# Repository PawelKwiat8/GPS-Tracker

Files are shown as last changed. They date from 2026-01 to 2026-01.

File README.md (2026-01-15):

# Projekt i realizacja autonomicznego rejestratora parametrów ruchu GPS z interfejsem bezprzewodowym opartym o układ ESP32

## Wstęp

 Celem tej pracy jest zaprojektowanie i zbudowanie urządzenia typu “GPS Tracker". Urządzenie ma rejestrować trasę, monitorować parametry ruchu i pokazywać dane w czasie rzeczywistym.

Głównym założeniem projektu było stworzenie systemu autonomicznego, zasilanego bateryjnie, który łączy w sobie funkcjonalność klasycznego rejestratora danych (tzw. "czarnej skrzynki") z nowoczesnym interfejsem użytkownika dostępnym przez przeglądarkę internetową (Web Interface).

### Koncepcja architektury systemu telemetrycznego

Do realizacji zadania wybrano platformę **ESP32**, kierując się jej  architekturą dwurdzeniową. Pozwala ona na separację procesów krytycznych (obsługa przerwań GPS i IMU) od obsługi stosu sieciowego WiFi, co jest ważne, żeby dane były zapisywane ciągle. Dodatkowo, wysoki stopień integracji w jednym układzie pozwolił zminimalizować wymiary urządzenia oraz uprościć układ oraz obniżyć cene.

## Projekt sprzętowy

Warstwa sprzętowa urządzenia została zaprojektowana w sposób modułowy, co ułatwia diagnostykę oraz ewentualną wymianę komponentów. System składa się z następujących komponentów:

### Elementy układu

* **Mikrokontroler:** ESP32 DevKit V1 WROOM-32 – dwurdzeniowy procesor z WiFi i Bluetooth
* **Moduł GPS:** NEO-6M V2 – odbiornik satelitarny (komunikacja UART)
* **IMU (czujnik ruchu):** MPU6050 – akcelerometr i żyroskop 6-osiowy (I2C)
* **Wyświetlacz:** OLED 0.96" – monochromatyczny ekran 128x64 px (I2C)
* **Pamięć masowa:** Micro SD Card Module – czytnik kart MicroSD (SPI)
* **Zasilanie:** Ładowarka Li-Ion z wejściem USB-C i zabezpieczeniami, współpracująca z ogniwem 18650. Układ umożliwia ładowanie baterii lub zasilanie systemu bezpośrednio z portu USB.

### Konfiguracja interfejsów i połączeń

Wszystkie moduły peryferyjne zostały połączone z mikrokontrolerem zgodnie z załączonym schematem elektrycznym. Kluczowym wymogiem poprawności działania układu jest połączenie wszystkich mas (GND) w jeden wspólny potencjał.

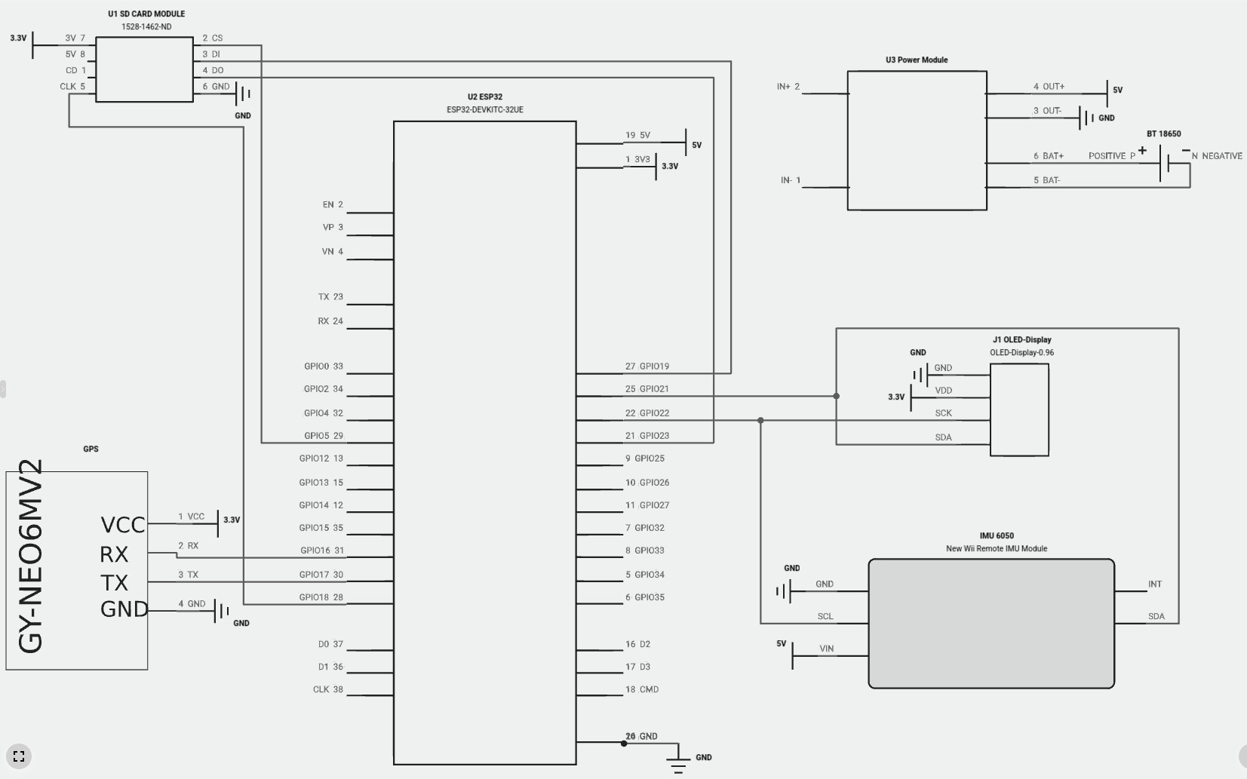
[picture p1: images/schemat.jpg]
Schemat elektryczny systemu


**Magistrala I2C (OLED + MPU6050):**
Urządzenia podłączone równolegle do wspólnych linii SDA i SCL.

| Urządzenie | Pin Modułu | Pin ESP32 | Uwagi |
| :--- | :--- | :--- | :--- |
| **OLED 0.96"** | SDA | GPIO 21 | Adres I2C: 0x3C |
| | SCL | GPIO 22 | |
| | VCC | 3.3V | Z pinu 3V3 ESP32 |
| | GND | GND | Wspólna masa |
| **MPU6050 (IMU)** | SDA | GPIO 21 | Adres I2C: 0x68 |
| | SCL | GPIO 22 | |
| | VCC | 5V | Z pinu 5V OUT power module |
| | GND | GND | Wspólna masa |

**Moduł GPS NEO-6M V2 (UART):**
Wykorzystuje sprzętowy port szeregowy UART2.

| Pin Modułu GPS | Pin ESP32 | Funkcja |
| :--- | :--- | :--- |
| TX | GPIO 16 (RX2) | Transmisja z GPS do ESP32 |
| RX | GPIO 17 (TX2) | Konfiguracja GPS (opcjonalna) |
| VCC | 3.3V | Z pinu 3V3 ESP32 |
| GND | GND | Wspólna masa |

**Micro SD Card Module (SPI):**
Wykorzystuje standardową magistralę VSPI.

| Pin Modułu SD | Pin ESP32 | Funkcja |
| :--- | :--- | :--- |
| CS | GPIO 5 | Chip Select |
| SCK | GPIO 18 | Zegar synchronizacji |
| MISO | GPIO 19 | Dane (Master In, Slave Out) |
| MOSI | GPIO 23 | Dane (Master Out, Slave In) |
| VCC | 3.3V | Z pinu 3V3 ESP32 |
| GND | GND | Wspólna masa |

### Projekt obudowy

Obudowa urządzenia przeszła ewolucję od prototypu (Wersja 1) do wersji finalnej (Wersja 2), wprowadzając istotne usprawnienia w konstrukcji i ergonomii użytkowania. Obie wersje zostały zaprojektowane w środowisku Autodesk Inventor z przeznaczeniem do druku 3D.

#### Wersja 1 (Prototyp)

Pierwsza wersja obudowy składała się z wielu elementów: podstawy z komorami na moduły i ogniwo 18650, ramki montażowej oraz pokrywy z charakterystycznym wzorem plastra miodu. Projekt zawierał dodatkową klapkę oraz otwory na kartę SD, które w praktyce okazały się zbędne lub problematyczne w druku.

Fizyczny model prototypu V1

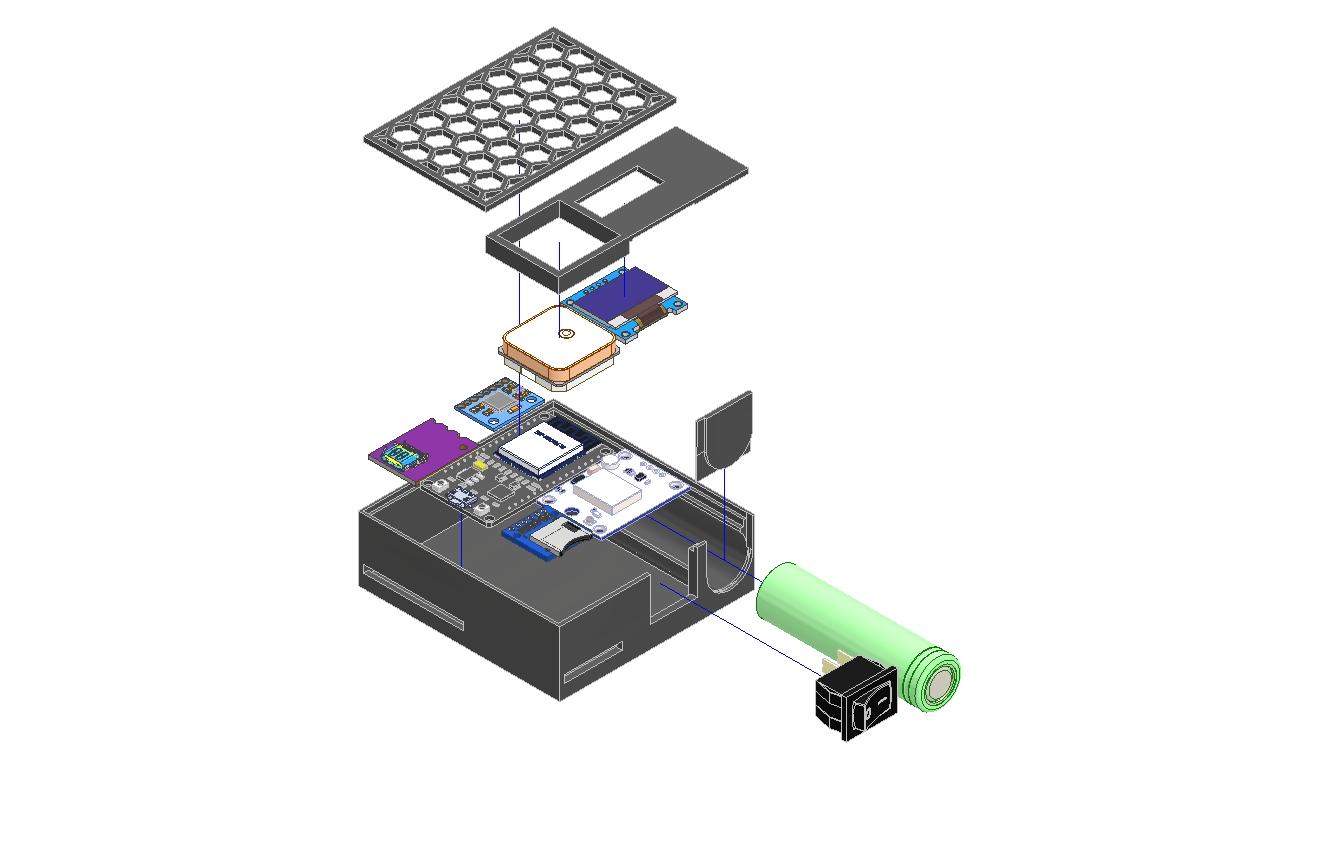
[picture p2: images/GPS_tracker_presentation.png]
Widok eksplodowany konstrukcji V1


#### Wersja 2 (Finalna)

W drugiej wersji wprowadzono szereg udoskonaleń wynikających z testów prototypu:
1.  **Uproszczona konstrukcja**: Usunięto zbędną klapkę oraz otwory na kartę SD, co zwiększyło sztywność i szczelność obudowy.
2.  **Zintegrowana pokrywa**: Dwie oddzielne górne pokrywy zostały połączone w jeden solidny element.
3.  **Wzmocnione ścianki**: Zwiększono grubość ścianek, co poprawiło wytrzymałość mechaniczną wydruku.
4.  **Lepsze dopasowanie**: Poprawiono spasowanie wszystkich elementów, eliminując luzy.
5.  **Dostęp do portów**: Zoptymalizowano otwory na porty USB (dla ładowania i programowania), ułatwiając podłączanie przewodów.

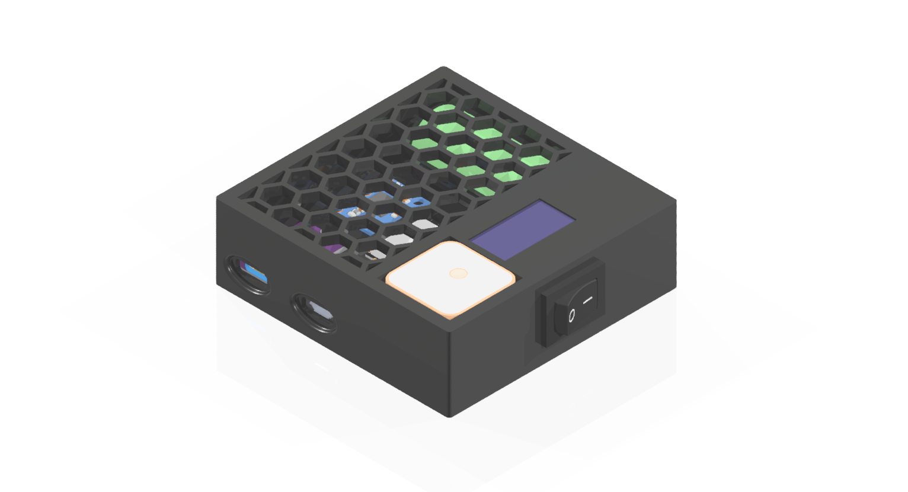
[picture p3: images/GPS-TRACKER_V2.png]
Widok złożonej obudowy V2


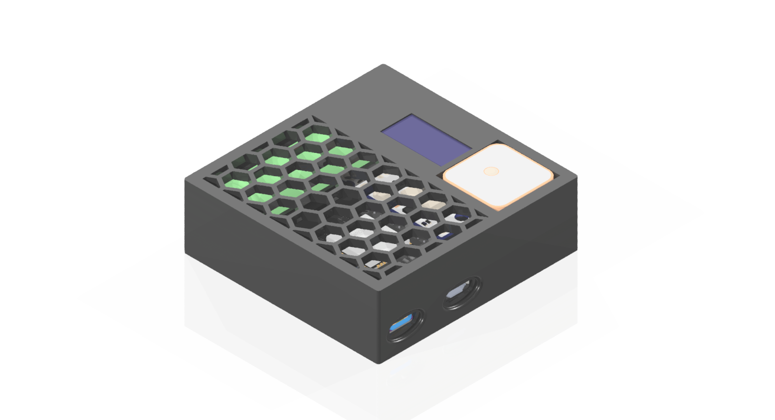
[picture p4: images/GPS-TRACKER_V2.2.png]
Widok obudowy V2 z innej perspektywy


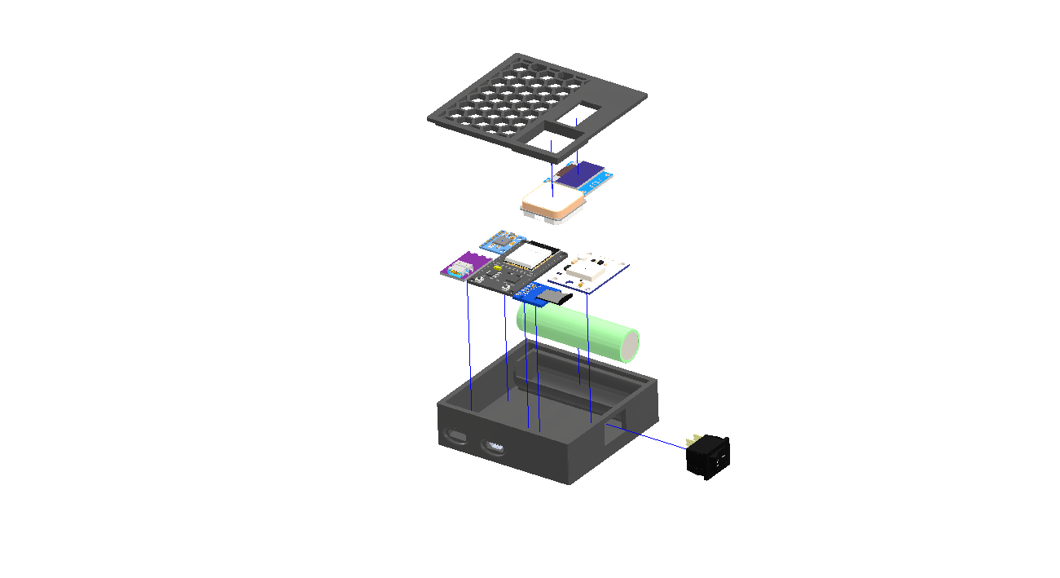
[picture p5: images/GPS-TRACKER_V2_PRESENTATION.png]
Widok eksplodowany konstrukcji V2


## Implementacja oprogramowania

### Opis funkcjonalności i obsługa aplikacji

Aplikacja webowa stanowi główne centrum sterowania urządzeniem. Poniżej przedstawiono szczegółowy opis interfejsu oraz dostępnych funkcji, które zostały zaimplementowane w celu zapewnienia intuicyjnej obsługi.

#### Ekran główny i parametry na żywo

Po nawiązaniu połączenia z siecią Wi-Fi urządzenia, w prawym górnym rogu aplikacji widoczny jest status "POŁĄCZONO". W przypadku utraty zasięgu lub zerwania połączenia, komunikat natychmiast zmienia się na "ROZŁĄCZONO", informując użytkownika o braku aktualnej synchronizacji danych.

Ekran główny został podzielony na dwie sekcje logiczne: mapę z aktualną pozycją (wykorzystującą bibliotekę Leaflet) oraz panel parametrów telemetrycznych.

Na panelu dolnym wyświetlane są kluczowe parametry odświeżane w czasie rzeczywistym:

* **Prędkość:** Aktualna prędkość przemieszczania się wyrażona w km/h.
* **Wysokość:** Wysokość nad poziomem morza w metrach.
* **Dystans:** Całkowita długość trasy przebyta w bieżącej sesji.
* **Satelity:** Liczba widocznych i używanych do nawigacji satelitów, co pozwala ocenić jakość "fixa".
* **HDOP:** Parametr precyzji geometrycznej (im niższy, tym lepiej).
* **Bateria:** Napięcie ogniwa zasilającego, pozwalające monitorować stan naładowania.

W sytuacji, gdy urządzenie nie posiada jeszcze ustalonej pozycji GPS (np. zaraz po włączeniu wewnątrz budynku), na ekranie widnieje wyraźny komunikat o szukaniu sygnału GPS.

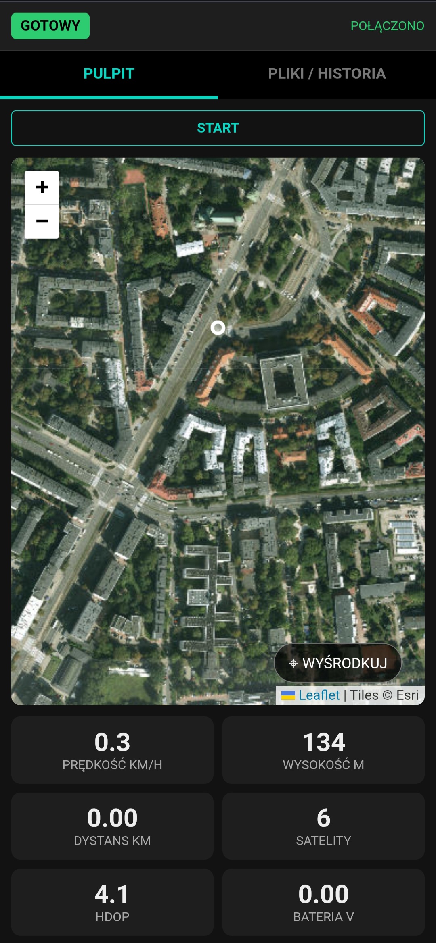
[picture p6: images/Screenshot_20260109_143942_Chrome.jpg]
Ekran startowy aplikacji - system gotowy do pracy


**Proces nagrywania trasy**

Sterowanie procesem rejestracji odbywa się za pomocą centralnego przycisku **"START"**. Rozpoczęcie nagrywania aktywuje rysowanie śladu na mapie oraz zliczanie statystyk sesji. Aplikacja udostępnia również funkcję centrowania mapy – specjalny przycisk pozwala jednym kliknięciem przywrócić widok na aktualną pozycję GPS, co jest przydatne po ręcznym przesuwaniu mapy w celu podejrzenia okolicy.

System obsługuje zaawansowane funkcje pauzowania:

* **Pauza manualna:** Użytkownik może w każdej chwili ręcznie wstrzymać zapis przyciskiem "PAUZA".
* **Auto-Pauza:** System automatycznie wykrywa brak ruchu i wstrzymuje zapis, co jest sygnalizowane pomarańczowym komunikatem "PAUZA / AUTO-PAUZA" na mapie. Zapobiega to rejestrowaniu błędnych punktów podczas postojów.

Po zakończeniu aktywności użytkownik ma do wyboru trzy opcje:

1. **WZNÓW:** Powrót do nagrywania w ramach tej samej sesji.
2. **ZAPISZ:** Trwałe zapisanie zgromadzonych danych do pliku w pamięci urządzenia.
3. **ODRZUĆ:** Anulowanie sesji i usunięcie tymczasowych danych bez zapisu.

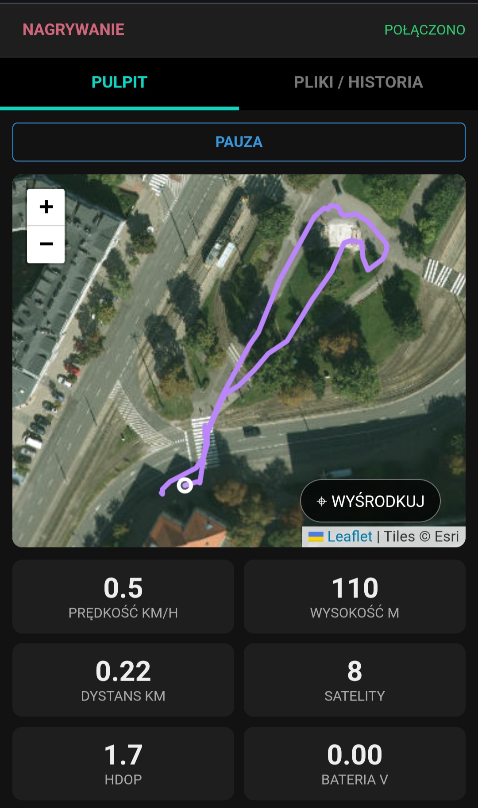
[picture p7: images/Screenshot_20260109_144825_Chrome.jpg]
Trwająca sesja z rysowaną trasą

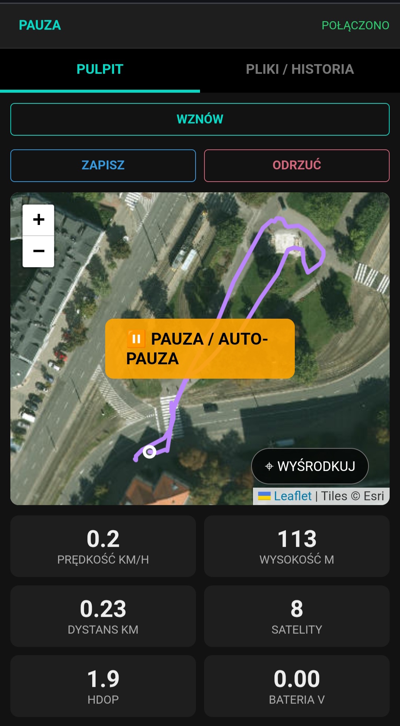
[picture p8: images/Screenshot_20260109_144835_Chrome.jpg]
Stan wstrzymania nagrywania (Pauza)


**Wykresy i analiza trendów**

Dla bardziej wnikliwej analizy aktywności, aplikacja udostępnia sekcję wykresów rysowanych na żywo. Pozwala to na bieżąco śledzić historię parametrów:

* Profil prędkości w czasie.
* Profil wysokości n.p.m.
* Wykres precyzji GPS (HDOP).
* Odczyty z akcelerometru (siły przeciążeń).

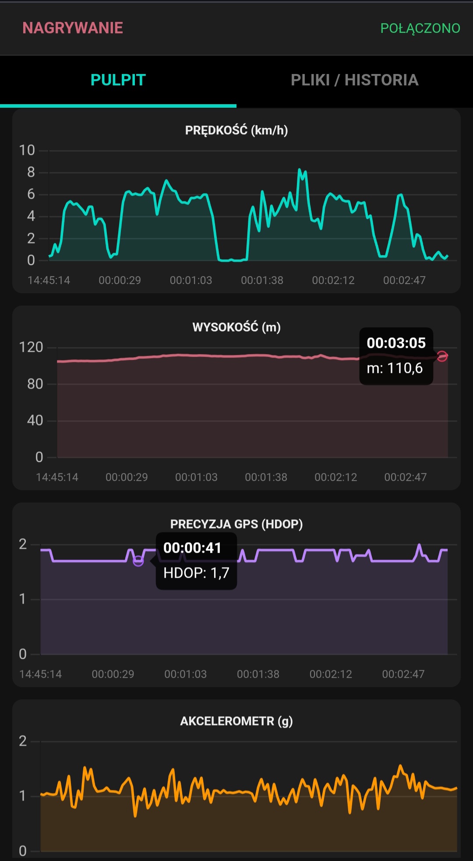
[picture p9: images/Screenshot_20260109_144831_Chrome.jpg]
Wykresy parametrów telemetrycznych


#### Zarządzanie plikami i historia tras

Druga zakładka interfejsu, "PLIKI / HISTORIA", dedykowana jest zarządzaniu danymi zgromadzonymi na karcie SD. Użytkownik otrzymuje pełną kontrolę nad archiwum tras bez konieczności wyjmowania karty z urządzenia.

Dostępne funkcjonalności obejmują:

* **Odświeżanie listy:** Pobranie aktualnego wykazu plików z karty SD.
* **Pobieranie:** Transfer wybranego pliku .csv/.txt bezpośrednio do pamięci telefonu/komputera.
* **Usuwanie:** Trwałe usunięcie niepotrzebnych plików.
* **Podgląd:** Specjalny tryb wizualizacji archiwalnej sesji.

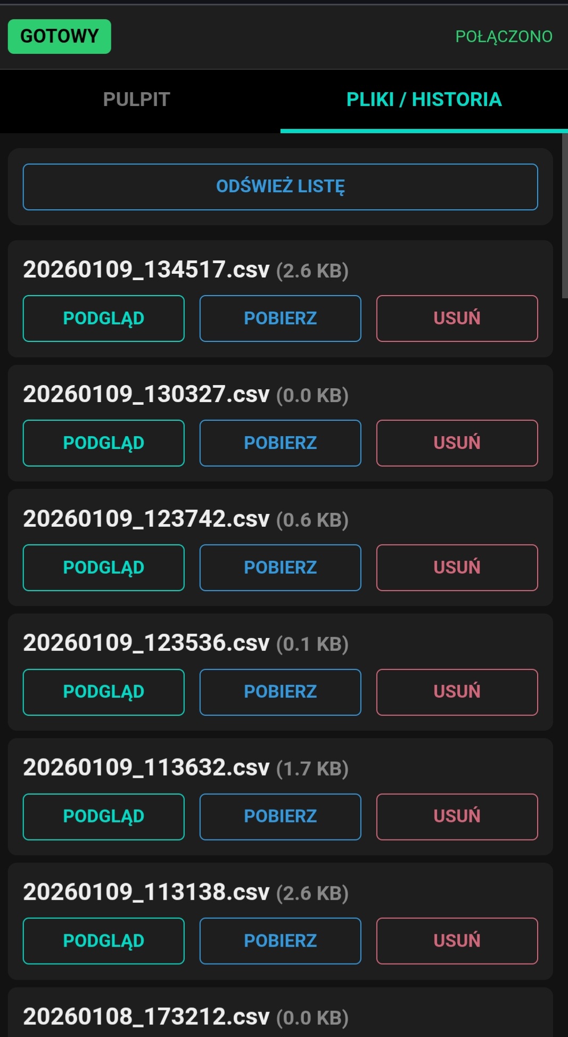
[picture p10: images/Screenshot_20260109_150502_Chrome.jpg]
Lista zapisanych plików


W trybie **podglądu pliku** interfejs prezentuje kompletny ślad trasy na mapie oraz rozszerzony zestaw statystyk, niedostępnych w trybie na żywo, takich jak:

* **Średnia prędkość:** Wartość wyliczona dla całej trasy, z uwzględnieniem postojów (auto-pauza).
* **Suma wzniosów i spadków:** Łączna różnica wysokości pokonana podczas sesji.
* **Maksymalna wysokość:** Najwyższy punkt osiagnięty na trasie (max AMSL).
* **Dystans:** Całkowita długość trasy.
* **Średnie HDOP:** Średnia wartość precyzji pomiaru z całego zapisu, pozwalająca ocenić wiarygodność danych.

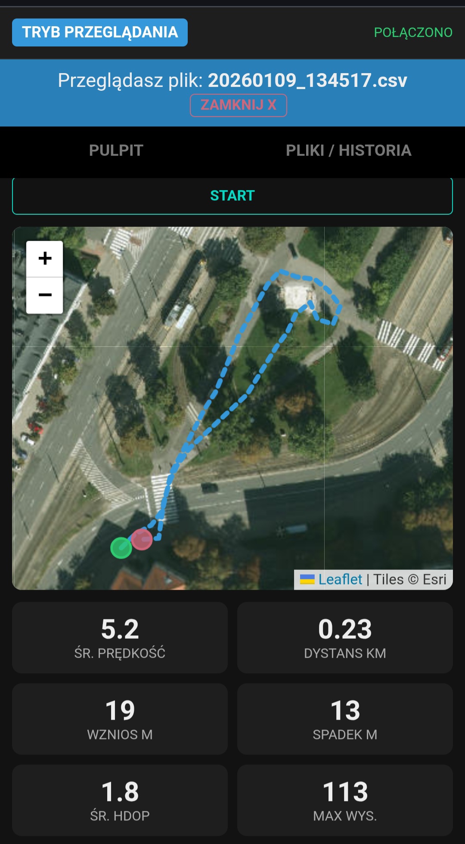
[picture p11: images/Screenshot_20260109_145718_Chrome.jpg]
Tryb podglądu historii z dodatkowymi parametrami


Dodatkowo, w trybie podglądu użytkownik ma dostęp do szczegółowych wykresów analizujących przebieg całej trasy. Są to te same wykresy co w trybie na żywo (prędkość, wysokość, HDOP), ale przedstawiające kompletne dane z całego nagrania, co pozwala na łatwą identyfikację kluczowych momentów wycieczki.

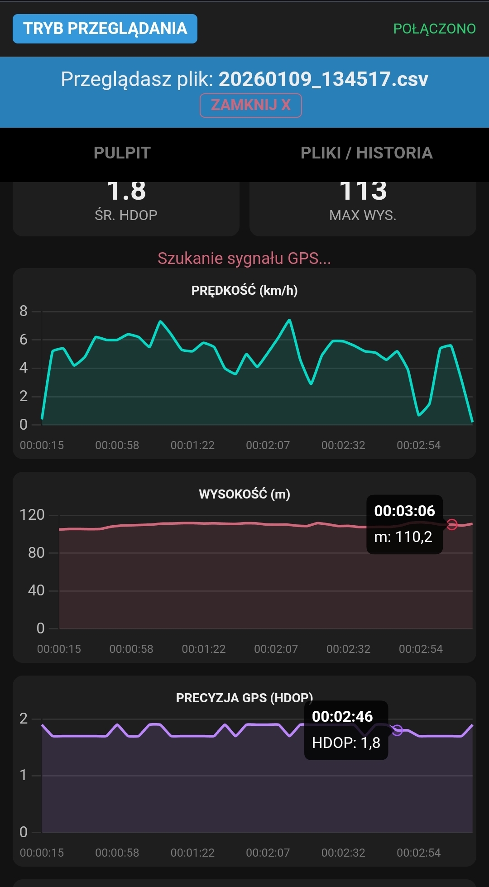
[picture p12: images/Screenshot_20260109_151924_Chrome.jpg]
Szczegółowa analiza wykresów w trybie przeglądania historii


Dane zapisywane są na karcie SD w formacie CSV (Comma Separated Values), co umożliwia ich łatwy import do arkuszy kalkulacyjnych (np. Excel) lub specjalistycznego oprogramowania GIS. Każda linia w pliku odpowiada jednemu punktowi pomiarowemu i zawiera następujące pola, oddzielone przecinkami:

* **Czas (ms):** Czas systemowy w milisekundach od uruchomienia urządzenia.
* **Szerokość i Długość geograficzna:** Współrzędne GPS (format dziesiętny).
* **Prędkość (km/h):** Chwilowa prędkość ruchu.
* **Wysokość (m n.p.m.):}** Wysokość nad poziomem morza.
* **HDOP:** Precyzja pomiaru poziomego (im mniejsza wartość, tym lepiej).
* **Satelity:** Liczba widocznych satelitów użytych do ustalenia pozycji.
* **Akcelerometr (ax, ay, az):** Surowe dane z czujnika przeciążeń dla trzech osi.
* **Bateria (V):** Napięcie zasilania w momencie pomiaru.

Przykładowa struktura linii danych:

```
millis,lat,lon,speed,alt,hdop,sats,ax,ay,az,batt
34500,52.2297,21.0122,15.5,112.4,1.2,8,0.02,-0.98,0.15,4.12
```

**Integracja z wyświetlaczem OLED**

Niezależnie od aplikacji mobilnej, urządzenie wyposażone jest w fizyczny ekran OLED. Pełni on funkcję pomocniczą, prezentując najważniejsze informacje w zwięzłej formie:

* Aktualny status: Oczekiwanie / Nagrywanie / Pauza.
* Liczba widocznych satelitów (ikona "SAT").
* Bieżąca prędkość oraz przebyty dystans.
* Adres IP oraz nazwa sieci WiFi (SSID) w celu ułatwienia połączenia.

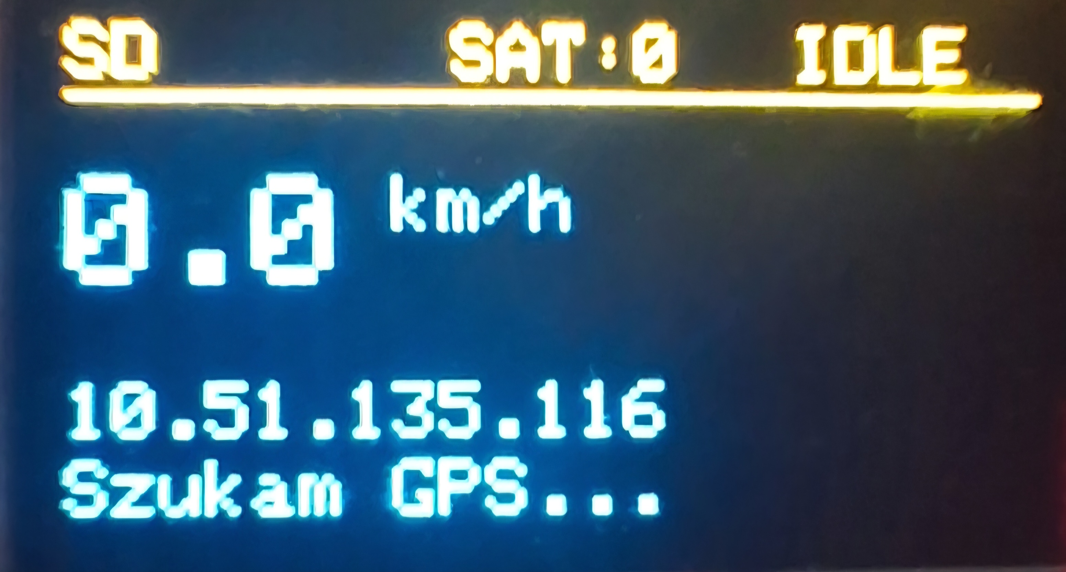
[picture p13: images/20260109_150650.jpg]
Wyświetlacz OLED w działaniu


## Wnioski końcowe

Przeprowadzone testy i analiza działania prototypu pozwalają na sformułowanie następujących wniosków:

1. **Stabilność działania:** Dzięki wykorzystaniu dwóch rdzeni procesora ESP32, urządzenie działa płynnie. Nagrywanie trasy na kartę odbywa się niezależnie od obsługi WiFi, więc korzystanie z podglądu na telefonie nie zakłóca zapisu danych.
2. **Prosty i szybki interfejs:** Strona WWW została napisana tak, aby nie obciążać procesora. Telefon pobiera tylko surowe liczby, a nie całą grafikę, dzięki czemu aplikacja działa szybko i nie zacina się.
3. **Jakość modułu GPS:** Tani moduł NEO-6M jest wystarczający do turystyki pieszej i zastosowań amatorskich. W testach statycznych wykazuje wysoką precyzję, jednak w dynamicznym ruchu (bieg) i trudnym terenie (las) jego dokładność spada, co jest typowe dla odbiorników bez wspomagania inercyjnego.
4. **Efektywność energetyczna:** Osiągnięty czas pracy na poziomie ok. 9 godzin przy zasilaniu z jednego ogniwa 18650 (z przetwornicą) czyni urządzenie praktycznym w jednodniowych zastosowaniach.
5. **Obudowa 3D:** Zaprojektowana obudowa jest kompaktowa i funkcjonalna. Chroni elektronikę przed uszkodzeniami mechanicznymi, zapewniając jednocześnie łatwy dostęp do portu ładowania i karty pamięci.

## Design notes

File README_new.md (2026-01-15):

# Projekt i realizacja autonomicznego rejestratora parametrów ruchu GPS z interfejsem bezprzewodowym opartym o układ ESP32

## Wstęp

  Celem tej pracy jest zaprojektowanie i zbudowanie urządzenia typu “GPS Tracker". Urządzenie ma rejestrować trasę, monitorować parametry ruchu i pokazywać dane w czasie rzeczywistym.

Głównym założeniem projektu było stworzenie systemu autonomicznego, zasilanego bateryjnie, który łączy w sobie funkcjonalność klasycznego rejestratora danych (tzw. "czarnej skrzynki") z nowoczesnym interfejsem użytkownika dostępnym przez przeglądarkę internetową (Web Interface).

### Koncepcja architektury systemu telemetrycznego

Największy problem przy tworzeniu przenośnych rejestratorów danych to znalezienie balansu między siłą obliczeń a zużyciem prądu. Stare, proste rejestratory danych tylko zapisują dane i nic więcej nie robią. Natomiast nowe rozwiązania IoT chcą przetwarzać dane tam, gdzie je zbierają, i nie potrzebują zewnętrznych serwerów. Z mojego doświadczenia widzę, że ten balans decyduje o tym, czy rejestrator będzie działał długo i dobrze.

W niniejszym projekcie przyjęto założenie, że urządzenie nie tylko gromadzi surowe dane pomiarowe, ale działa jako  niezależny serwera aplikacj i udostępnia pełny graficzny interfejs. To wymusiło rezygnację z prostych mikrokontrolerów 8-bitowych na rzecz wydajniejszych jednostek obliczeniowych, łączących wiele funkcji (w tym bezprzewodową łączność) w jednym układzie scalonym.

Do realizacji zadania wybrano platformę **ESP32**, kierując się jej unikalną architekturą dwurdzeniową. Pozwala ona na separację procesów krytycznych (obsługa przerwań GPS i IMU) od obsługi stosu sieciowego WiFi, co jest ważne, żeby dane były zapisywane ciągle. Dodatkowo, wysoki stopień integracji w jednym układzie pozwolił zminimalizować wymiary urządzenia oraz uprościć układ oraz obniżyć cene.

## Projekt sprzętowy

Warstwa sprzętowa urządzenia została zaprojektowana w sposób modułowy, co ułatwia diagnostykę oraz ewentualną wymianę komponentów. System składa się z następujących komponentów:

### Elementy układu

* **Mikrokontroler:** ESP32 DevKit V1 WROOM-32 – dwurdzeniowy procesor z WiFi i Bluetooth
* **Moduł GPS:** NEO-6M V2 – odbiornik satelitarny (komunikacja UART)
* **IMU (czujnik ruchu):** MPU6050 – akcelerometr i żyroskop 6-osiowy (I2C)
* **Wyświetlacz:** OLED 0.96" – monochromatyczny ekran 128x64 px (I2C)
* **Pamięć masowa:** Micro SD Card Module – czytnik kart MicroSD (SPI)
* **Zasilanie:** Ładowarka Li-Ion z wejściem USB-C i zabezpieczeniami, współpracująca z ogniwem 18650. Układ umożliwia ładowanie baterii lub zasilanie systemu bezpośrednio z portu USB.

### Konfiguracja interfejsów i połączeń

Wszystkie moduły peryferyjne zostały połączone z mikrokontrolerem zgodnie z załączonym schematem elektrycznym. Kluczowym wymogiem poprawności działania układu jest połączenie wszystkich mas (GND) w jeden wspólny potencjał.

Schemat elektryczny systemu

**Magistrala I2C (OLED + MPU6050):**
Urządzenia podłączone równolegle do wspólnych linii SDA i SCL.

| Urządzenie | Pin Modułu | Pin ESP32 | Uwagi |
| :--- | :--- | :--- | :--- |
| **OLED 0.96"** | SDA | GPIO 21 | Adres I2C: 0x3C |
| | SCL | GPIO 22 | |
| | VCC | 3.3V | Z pinu 3V3 ESP32 |
| | GND | GND | Wspólna masa |
| **MPU6050 (IMU)** | SDA | GPIO 21 | Adres I2C: 0x68 |
| | SCL | GPIO 22 | |
| | VCC | 5V | Z pinu 5V OUT power module |
| | GND | GND | Wspólna masa |

**Moduł GPS NEO-6M V2 (UART):**
Wykorzystuje sprzętowy port szeregowy UART2.

| Pin Modułu GPS | Pin ESP32 | Funkcja |
| :--- | :--- | :--- |
| TX | GPIO 16 (RX2) | Transmisja z GPS do ESP32 |
| RX | GPIO 17 (TX2) | Konfiguracja GPS (opcjonalna) |
| VCC | 3.3V | Z pinu 3V3 ESP32 |
| GND | GND | Wspólna masa |

**Micro SD Card Module (SPI):**
Wykorzystuje standardową magistralę VSPI.

| Pin Modułu SD | Pin ESP32 | Funkcja |
| :--- | :--- | :--- |
| CS | GPIO 5 | Chip Select |
| SCK | GPIO 18 | Zegar synchronizacji |
| MISO | GPIO 19 | Dane (Master In, Slave Out) |
| MOSI | GPIO 23 | Dane (Master Out, Slave In) |
| VCC | 3.3V | Z pinu 3V3 ESP32 |
| GND | GND | Wspólna masa |

### Projekt obudowy

Obudowa została zaprojektowana w Autodesk Inventor z przeznaczeniem do druku 3D. Składa się z podstawy, ramki montażowej i pokrywy z wzorem plastra miodu. Podstawa zawiera komory na poszczególne moduły oraz schowek na ogniwo 18650. Ramka dystansowa tworzy okno dostępu do ekranu i GPS. Pokrywa z ażurowym wzorem zapewnia podglad wnetrza układu.

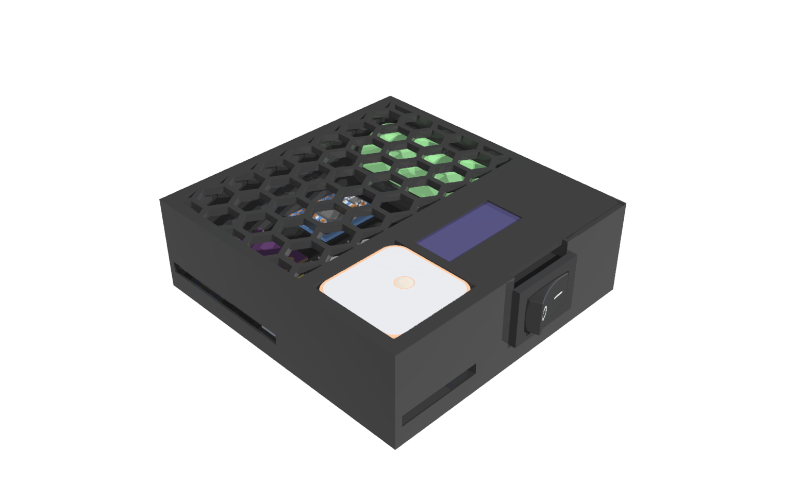
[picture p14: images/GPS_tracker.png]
Widok złożonej obudowy


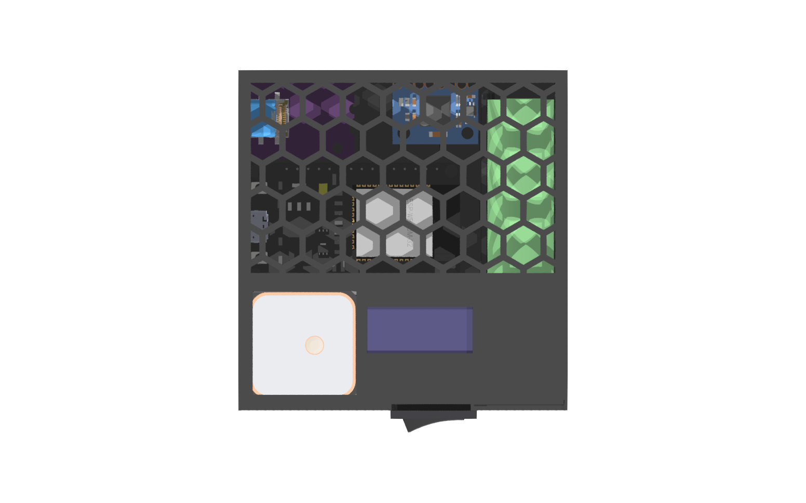
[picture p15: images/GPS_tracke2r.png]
Widok z góry


Widok eksplodowany konstrukcji

## Implementacja oprogramowania

### Opis funkcjonalności i obsługa aplikacji

Aplikacja webowa stanowi główne centrum sterowania urządzeniem. Poniżej przedstawiono szczegółowy opis interfejsu oraz dostępnych funkcji, które zostały zaimplementowane w celu zapewnienia intuicyjnej obsługi.

#### Ekran główny i parametry na żywo

Po nawiązaniu połączenia z siecią Wi-Fi urządzenia, w prawym górnym rogu aplikacji widoczny jest status "POŁĄCZONO". W przypadku utraty zasięgu lub zerwania połączenia, komunikat natychmiast zmienia się na "ROZŁĄCZONO", informując użytkownika o braku aktualnej synchronizacji danych.

Ekran główny został podzielony na dwie sekcje logiczne: mapę z aktualną pozycją (wykorzystującą bibliotekę Leaflet) oraz panel parametrów telemetrycznych.

Na panelu dolnym wyświetlane są kluczowe parametry odświeżane w czasie rzeczywistym:

* **Prędkość:** Aktualna prędkość przemieszczania się wyrażona w km/h.
* **Wysokość:** Wysokość nad poziomem morza w metrach.
* **Dystans:** Całkowita długość trasy przebyta w bieżącej sesji.
* **Satelity:** Liczba widocznych i używanych do nawigacji satelitów, co pozwala ocenić jakość "fixa".
* **HDOP:** Parametr precyzji geometrycznej (im niższy, tym lepiej).
* **Bateria:** Napięcie ogniwa zasilającego, pozwalające monitorować stan naładowania.

W sytuacji, gdy urządzenie nie posiada jeszcze ustalonej pozycji GPS (np. zaraz po włączeniu wewnątrz budynku), na ekranie widnieje wyraźny komunikat o szukaniu sygnału GPS.

Ekran startowy aplikacji - system gotowy do pracy

**Proces nagrywania trasy**

Sterowanie procesem rejestracji odbywa się za pomocą centralnego przycisku **"START"**. Rozpoczęcie nagrywania aktywuje rysowanie śladu na mapie oraz zliczanie statystyk sesji. Aplikacja udostępnia również funkcję centrowania mapy – specjalny przycisk pozwala jednym kliknięciem przywrócić widok na aktualną pozycję GPS, co jest przydatne po ręcznym przesuwaniu mapy w celu podejrzenia okolicy.

System obsługuje zaawansowane funkcje pauzowania:

* **Pauza manualna:** Użytkownik może w każdej chwili ręcznie wstrzymać zapis przyciskiem "PAUZA".
* **Auto-Pauza:** System automatycznie wykrywa brak ruchu i wstrzymuje zapis, co jest sygnalizowane pomarańczowym komunikatem "PAUZA / AUTO-PAUZA" na mapie. Zapobiega to rejestrowaniu błędnych punktów podczas postojów.

Po zakończeniu aktywności użytkownik ma do wyboru trzy opcje:

1. **WZNÓW:** Powrót do nagrywania w ramach tej samej sesji.
2. **ZAPISZ:** Trwałe zapisanie zgromadzonych danych do pliku w pamięci urządzenia.
3. **ODRZUĆ:** Anulowanie sesji i usunięcie tymczasowych danych bez zapisu.

Trwająca sesja z rysowaną trasą
Stan wstrzymania nagrywania (Pauza)

**Wykresy i analiza trendów**

Dla bardziej wnikliwej analizy aktywności, aplikacja udostępnia sekcję wykresów rysowanych na żywo. Pozwala to na bieżąco śledzić historię parametrów:

* Profil prędkości w czasie.
* Profil wysokości n.p.m.
* Wykres precyzji GPS (HDOP).
* Odczyty z akcelerometru (siły przeciążeń).

Wykresy parametrów telemetrycznych

#### Zarządzanie plikami i historia tras

Druga zakładka interfejsu, "PLIKI / HISTORIA", dedykowana jest zarządzaniu danymi zgromadzonymi na karcie SD. Użytkownik otrzymuje pełną kontrolę nad archiwum tras bez konieczności wyjmowania karty z urządzenia.

Dostępne funkcjonalności obejmują:

* **Odświeżanie listy:** Pobranie aktualnego wykazu plików z karty SD.
* **Pobieranie:** Transfer wybranego pliku .csv/.txt bezpośrednio do pamięci telefonu/komputera.
* **Usuwanie:** Trwałe usunięcie niepotrzebnych plików.
* **Podgląd:** Specjalny tryb wizualizacji archiwalnej sesji.

Lista zapisanych plików

W trybie **podglądu pliku** interfejs prezentuje kompletny ślad trasy na mapie oraz rozszerzony zestaw statystyk, niedostępnych w trybie na żywo, takich jak:

* **Średnia prędkość:** Wartość wyliczona dla całej trasy, z uwzględnieniem postojów (auto-pauza).
* **Suma wzniosów i spadków:** Łączna różnica wysokości pokonana podczas sesji.
* **Maksymalna wysokość:** Najwyższy punkt osiagnięty na trasie (max AMSL).
* **Dystans:** Całkowita długość trasy.
* **Średnie HDOP:** Średnia wartość precyzji pomiaru z całego zapisu, pozwalająca ocenić wiarygodność danych.

Tryb podglądu historii z dodatkowymi parametrami

Dodatkowo, w trybie podglądu użytkownik ma dostęp do szczegółowych wykresów analizujących przebieg całej trasy. Są to te same wykresy co w trybie na żywo (prędkość, wysokość, HDOP), ale przedstawiające kompletne dane z całego nagrania, co pozwala na łatwą identyfikację kluczowych momentów wycieczki.

Szczegółowa analiza wykresów w trybie przeglądania historii

Dane zapisywane są na karcie SD w formacie CSV (Comma Separated Values), co umożliwia ich łatwy import do arkuszy kalkulacyjnych (np. Excel) lub specjalistycznego oprogramowania GIS. Każda linia w pliku odpowiada jednemu punktowi pomiarowemu i zawiera następujące pola, oddzielone przecinkami:

* **Czas (ms):** Czas systemowy w milisekundach od uruchomienia urządzenia.
* **Szerokość i Długość geograficzna:** Współrzędne GPS (format dziesiętny).
* **Prędkość (km/h):** Chwilowa prędkość ruchu.
* **Wysokość (m n.p.m.):}** Wysokość nad poziomem morza.
* **HDOP:** Precyzja pomiaru poziomego (im mniejsza wartość, tym lepiej).
* **Satelity:** Liczba widocznych satelitów użytych do ustalenia pozycji.
* **Akcelerometr (ax, ay, az):** Surowe dane z czujnika przeciążeń dla trzech osi.
* **Bateria (V):** Napięcie zasilania w momencie pomiaru.

Przykładowa struktura linii danych:

```
millis,lat,lon,speed,alt,hdop,sats,ax,ay,az,batt
34500,52.2297,21.0122,15.5,112.4,1.2,8,0.02,-0.98,0.15,4.12
```

**Integracja z wyświetlaczem OLED**

Niezależnie od aplikacji mobilnej, urządzenie wyposażone jest w fizyczny ekran OLED. Pełni on funkcję pomocniczą, prezentując najważniejsze informacje w zwięzłej formie:

* Aktualny status: Oczekiwanie / Nagrywanie / Pauza.
* Liczba widocznych satelitów (ikona "SAT").
* Bieżąca prędkość oraz przebyty dystans.
* Adres IP oraz nazwa sieci WiFi (SSID) w celu ułatwienia połączenia.

## Wnioski końcowe

Przeprowadzone testy i analiza działania prototypu pozwalają na sformułowanie następujących wniosków:

1. **Stabilność działania:** Dzięki wykorzystaniu dwóch rdzeni procesora ESP32, urządzenie działa płynnie. Nagrywanie trasy na kartę odbywa się niezależnie od obsługi WiFi, więc korzystanie z podglądu na telefonie nie zakłóca zapisu danych.
2. **Prosty i szybki interfejs:** Strona WWW została napisana tak, aby nie obciążać procesora. Telefon pobiera tylko surowe liczby, a nie całą grafikę, dzięki czemu aplikacja działa szybko i nie zacina się.
3. **Jakość modułu GPS:** Tani moduł NEO-6M jest wystarczający do turystyki pieszej i zastosowań amatorskich. W testach statycznych wykazuje wysoką precyzję, jednak w dynamicznym ruchu (bieg) i trudnym terenie (las) jego dokładność spada, co jest typowe dla odbiorników bez wspomagania inercyjnego.
4. **Efektywność energetyczna:** Osiągnięty czas pracy na poziomie ok. 9 godzin przy zasilaniu z jednego ogniwa 18650 (z przetwornicą) czyni urządzenie praktycznym w jednodniowych zastosowaniach.
5. **Obudowa 3D:** Zaprojektowana obudowa jest kompaktowa i funkcjonalna. Chroni elektronikę przed uszkodzeniami mechanicznymi, zapewniając jednocześnie łatwy dostęp do portu ładowania i karty pamięci.

### Podsumowanie działania

Zrealizowany system działa w pełni poprawnie i spełnił wszystkie założenia oraz cel pracy. Urządzenie pomyślnie przeszło testy terenowe, rejestrując trasy bez awarii. Projekt udowodnił, że wykorzystując tanie i ogólnodostępne moduły (ESP32, NEO-6M), można zbudować narzędzie telemetryczne o funkcjonalności zbliżonej do prostych urządzeń komercyjnych.

Dodatkową wartością projektu jest jego aspekt edukacyjny. Budowa urządzenia wymagała połączenia wiedzy z zakresu elektroniki, druku 3D oraz programowania systemów wbudowanych i aplikacji webowych. Powstały prototyp jest nie tylko działającym urządzeniem, ale także solidną platformą do dalszego rozwoju, np. poprzez dodanie modułu GSM w przyszłości.

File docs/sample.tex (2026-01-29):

\documentclass[12pt, a4paper]{EE-dyplom}

\usepackage{float}
\usepackage{tabularx}
\usepackage{url}
\def\UrlBreaks{\do\/\do-}
\usepackage{indentfirst}
\usepackage{titlesec}
\usepackage{hyperref}

% DANE DO STRONY TYTUŁOWEJ
\kierunek{Automatyka, Robotyka i Informatyka Przemysłowa}
\title{Projekt i realizacja autonomicznego rejestratora parametrów ruchu GPS z interfejsem bezprzewodowym opartym o układ ESP32}
\album{320126}
\author{Paweł Kwiatkowski}
\promotor{[...]} 
\date{2026}

% Ręczna konfiguracja języka polskiego
\renewcommand{\contentsname}{Spis treści}
\renewcommand{\listfigurename}{Spis rysunków}
\renewcommand{\listtablename}{Spis tabel}
\renewcommand{\figurename}{Rysunek}
\renewcommand{\tablename}{Tabela}
\renewcommand{\refname}{Bibliografia}
\renewcommand{\abstractname}{Streszczenie}

\sloppy 

\begin{document}

\maketitle

\newpage

\begin{abstract}
Celem niniejszej pracy inżynierskiej jest zaprojektowanie i realizacja autonomicznego 
rejestratora parametrów ruchu GPS, wyposażonego w zintegrowany interfejs bezprzewodowy WiFi. 
Urządzenie, oparte na dwurdzeniowym mikrokontrolerze ESP32, łączy w sobie funkcjonalność klasycznego
 "data-loggera" zapisującego dane na karcie pamięci SD z nowoczesną wizualizacją parametrów w czasie r
 zeczywistym poprzez dedykowaną stronę internetową (Web Interface).

W ramach projektu opracowano kompletną warstwę sprzętową, integrującą moduł nawigacji satelitarnej 
NEO-6M, czujnik inercyjny IMU (MPU6050) oraz wyświetlacz OLED. Praca opisuje również 
proces projektowania ergonomicznej obudowy  oraz jej wykonanie w technologii druku 3D. 
Przeprowadzone testy terenowe potwierdziły poprawność działania prototypu, stabilność rejestracji śladu 
oraz satysfakcjonujący czas pracy na zasilaniu bateryjnym.
\end{abstract}
\newpage

\tableofcontents
\newpage
\section{Wstęp}
\subsection{Cel pracy i założenia projektowe}

Celem tej pracy jest zaprojektowanie i 
zbudowanie urządzenia typu “GPS Tracker". Urządzenie ma rejestrować trasę,
monitorować parametry ruchu i pokazywać dane w czasie rzeczywistym.

Głównym założeniem projektu było stworzenie systemu autonomicznego, 
zasilanego bateryjnie, który łączy w sobie funkcjonalność klasycznego rejestratora danych 
 z nowoczesnym interfejsem użytkownika dostępnym przez przeglądarkę 
internetową (Web Interface).

\subsection{Koncepcja architektury systemu telemetrycznego}

W niniejszym projekcie przyjęto założenie, że urządzenie nie tylko gromadzi surowe dane pomiarowe, 
ale działa jako  niezależny serwera aplikacj i udostępnia pełny graficzny interfejs. 
To wymusiło rezygnację z prostych mikrokontrolerów 8-bitowych na rzecz wydajniejszych jednostek obliczeniowych,
łączących wiele funkcji (w tym bezprzewodową łączność) w jednym układzie scalonym.

Do realizacji zadania wybrano platformę \textbf{ESP32}, kierując się jej unikalną architekturą dwurdzeniową.
Pozwala ona na separację procesów krytycznych (obsługa przerwań GPS i IMU) od obsługi stosu sieciowego WiFi, 
co jest ważne, żeby dane były zapisywane ciągle. Dodatkowo, wysoki stopień integracji  
w jednym układzie pozwolił zminimalizować wymiary urządzenia oraz uprościć układ oraz obniżyć cene 

\section{Projekt sprzętowy}

Warstwa sprzętowa urządzenia została zaprojektowana w sposób modułowy, co ułatwia diagnostykę oraz ewentualną wymianę komponentów. System składa się z następujących komponentów:

\subsection{Elementy układu}

\begin{itemize}
    \item \textbf{Mikrokontroler:} ESP32 DevKit V1 WROOM-32 – dwurdzeniowy procesor z WiFi i Bluetooth
    \item \textbf{Moduł GPS:} NEO-6M V2 – odbiornik satelitarny (komunikacja UART)
    \item \textbf{IMU (czujnik ruchu):} MPU6050 – akcelerometr i żyroskop 6-osiowy (I2C)
    \item \textbf{Wyświetlacz:} OLED 0.96" – monochromatyczny ekran 128x64 px (I2C)
    \item \textbf{Pamięć masowa:} Micro SD Card Module – czytnik kart MicroSD (SPI)
    \item \textbf{Zasilanie:} Ładowarka Li-Ion z wejściem USB-C i zabezpieczeniami, współpracująca z ogniwem 18650. Układ umożliwia ładowanie baterii lub zasilanie systemu bezpośrednio z portu USB.
\end{itemize}

\subsection{Konfiguracja interfejsów i połączeń}
Wszystkie moduły peryferyjne zostały połączone z mikrokontrolerem zgodnie z załączonym schematem elektrycznym. Kluczowym wymogiem poprawności działania układu jest połączenie wszystkich mas (GND) w jeden wspólny potencjał.

\begin{figure}[H]
    \centering
    
    \caption{Schemat elektryczny systemu}
    \label{fig:schemat}
\end{figure}

\textbf{Magistrala I2C (OLED + MPU6050):}
Urządzenia podłączone równolegle do wspólnych linii SDA i SCL.

\begin{table}[H]
\centering
\begin{tabular}{|l|l|l|l|}
\hline
\textbf{Urządzenie} & \textbf{Pin Modułu} & \textbf{Pin ESP32} & \textbf{Uwagi} \\
\hline
\textbf{OLED 0.96"} & SDA & GPIO 21 & Adres I2C: 0x3C \\
 & SCL & GPIO 22 & \\
 & VCC & 3.3V & Z pinu 3V3 ESP32 \\
 & GND & GND & Wspólna masa \\
\hline
\textbf{MPU6050 (IMU)} & SDA & GPIO 21 & Adres I2C: 0x68 \\
 & SCL & GPIO 22 & \\
 & VCC & 5V & Z pinu 5V OUT power module \\
 & GND & GND & Wspólna masa \\
\hline
\end{tabular}
\caption{Konfiguracja magistrali I2C}
\label{tab:i2c}
\end{table}

\textbf{Moduł GPS NEO-6M V2 (UART):}
Wykorzystuje sprzętowy port szeregowy UART2.

\begin{table}[H]
\centering
\begin{tabular}{|l|l|l|}
\hline
\textbf{Pin Modułu GPS} & \textbf{Pin ESP32} & \textbf{Funkcja} \\
\hline
TX & GPIO 16 (RX2) & Transmisja z GPS do ESP32 \\
RX & GPIO 17 (TX2) & Konfiguracja GPS (opcjonalna) \\
VCC & 3.3V & Z pinu 3V3 ESP32 \\
GND & GND & Wspólna masa \\
\hline
\end{tabular}
\caption{Połączenie modułu GPS}
\label{tab:gps}
\end{table}

\textbf{Micro SD Card Module (SPI):}
Wykorzystuje standardową magistralę VSPI.

\begin{table}[H]
\centering
\begin{tabular}{|l|l|l|}
\hline
\textbf{Pin Modułu SD} & \textbf{Pin ESP32} & \textbf{Funkcja} \\
\hline
CS & GPIO 5 & Chip Select \\
SCK & GPIO 18 & Zegar synchronizacji \\
MISO & GPIO 19 & Dane (Master In, Slave Out) \\
MOSI & GPIO 23 & Dane (Master Out, Slave In) \\
VCC & 3.3V & Z pinu 3V3 ESP32 \\
GND & GND & Wspólna masa \\
\hline
\end{tabular}
\caption{Połączenie czytnika kart SD}
\label{tab:sd}
\end{table}

\subsection{Projekt obudowy}

Obudowa urządzenia przeszła ewolucję od prototypu (Wersja 1) do wersji finalnej (Wersja 2), wprowadzając istotne usprawnienia w konstrukcji i ergonomii użytkowania. Obie wersje zostały zaprojektowane w środowisku Autodesk Inventor z przeznaczeniem do druku 3D.

\subsubsection{Wersja 1 (Prototyp)}

Pierwsza wersja obudowy składała się z wielu elementów: podstawy z komorami na moduły i ogniwo 18650, ramki montażowej oraz pokrywy z charakterystycznym wzorem plastra miodu. Projekt zawierał dodatkową klapkę oraz otwory na kartę SD, które w praktyce okazały się zbędne lub problematyczne w druku.

\begin{figure}[H]
    \centering
    
    \caption{Fizyczny model prototypu V1}
\end{figure}

\begin{figure}[H]
    \centering
    
    \caption{Widok rozstrzelony konstrukcji V1}
\end{figure}

\subsubsection{Wersja 2 (Finalna)}

W drugiej wersji wprowadzono szereg udoskonaleń wynikających z testów prototypu:
\begin{enumerate}
    \item \textbf{Uproszczona konstrukcja}: Usunięto zbędną klapkę oraz otwory na kartę SD, co zwiększyło sztywność i szczelność obudowy.
    \item \textbf{Zintegrowana pokrywa}: Dwie oddzielne górne pokrywy zostały połączone w jeden solidny element.
    \item \textbf{Wzmocnione ścianki}: Zwiększono grubość ścianek, co poprawiło wytrzymałość mechaniczną wydruku.
    \item \textbf{Lepsze dopasowanie}: Poprawiono spasowanie wszystkich elementów, eliminując luzy.
    \item \textbf{Dostęp do portów}: Zoptymalizowano otwory na porty USB (dla ładowania i programowania), ułatwiając podłączanie przewodów.
\end{enumerate}

\begin{figure}[H]
    \centering
    
    \caption{Widok złożonej obudowy V2}
\end{figure}

\begin{figure}[H]
    \centering
    
    \caption{Widok obudowy V2 z innej perspektywy}
\end{figure}

\begin{figure}[H]
    \centering
    
    \caption{Widok rozstrzelony konstrukcji V2}
\end{figure}

\newpage
\section{Przegląd technologii i narzędzi}

Budowa trackera GPS wymaga połączenia kilku różnych technologii komunikacyjnych. Poniżej opisano kluczowe elementy systemu wykorzystane w projekcie.

\subsection{Rozwój IoT i miniaturyzacja}

Internet Rzeczy (IoT) to świat połączonych urządzeń – od zegarków, przez czujniki temperatury, aż po inteligentne zamki \cite{botland_esp32, msalamon_rodziny}. Miniaturyzacja, czyli proces zmniejszania rozmiarów komponentów elektronicznych, umożliwiła budowę tak małych i wydajnych urządzeń.

Moduł odbiornika GPS NEO-6M ma wymiary zaledwie 16 × 12,2 × 2,4 mm \cite{ublox_datasheet}, co pozwala zbudować kompaktowy tracker. Mniejsze układy zużywają też znacznie mniej energii – urządzenie może pracować na baterii przez wiele godzin lub dni. Integracja wielu funkcji w jednym układzie (System on Chip, w skrócie SoC) obniża koszty produkcji i zwiększa niezawodność systemu.

\subsection{Telemetria i przetwarzanie danych}

Telemetria to technologia zbierania danych z odległych miejsc i przesyłania ich w czasie rzeczywistym. W przypadku trackera GPS oznacza to automatyczne odczytywanie pozycji i prędkości bez potrzeby fizycznego dostępu do urządzenia.

Przetwarzanie na miejscu (Edge Computing) to koncepcja, w której dane nie są od razu wysyłane do internetu, ale wstępnie analizowane bezpośrednio w urządzeniu \cite{sensors_edge}. Mikrokontroler ESP32 odbiera surowe dane z modułu GPS, przetwarza je – rozpoznaje współrzędne, oblicza prędkość – i zapisuje gotowe wyniki na karcie pamięci. 

Dlaczego to ważne? Po pierwsze, oszczędza to energię baterii – zamiast ciągle wysyłać dane przez sieć (co zużywa dużo prądu), urządzenie analizuje je lokalnie i wysyła tylko niezbędne informacje. Po drugie, zwiększa to szybkość reakcji – decyzje podejmowane są natychmiast, bez czekania na odpowiedź z serwera.

\subsection{Architektura ESP32}

ESP32 to mikrokontroler firmy Espressif Systems, który posiada dwa niezależne rdzenie procesora Xtensa LX6 pracujące z częstotliwością do 240 MHz \cite{esp32_trm, msalamon_rodziny}. W praktyce oznacza to, że może wykonywać dwa zadania jednocześnie, bez wzajemnego spowalniania się.

Jak to działa? Jeden rdzeń może zajmować się obliczeniami – odbieraniem danych GPS, zapisywaniem ich na kartę pamięci, wyświetlaniem informacji na ekranie \cite{electronics_lang}. W tym samym czasie drugi rdzeń obsługuje komunikację bezprzewodową – Wi-Fi lub Bluetooth. Dzięki temu oba procesy działają płynnie i nie przeszkadzają sobie nawzajem.

ESP32 posiada także wbudowane moduły Wi-Fi i Bluetooth, co czyni go idealnym rozwiązaniem dla projektów wymagających bezprzewodowej komunikacji \cite{botland_esp32}. Dodatkowo, układ obsługuje zaawansowane tryby oszczędzania energii – może automatycznie "zasypiać" gdy nie wykonuje zadań, pobierając mniej niż 10 mikroamperów prądu.

\subsection{System GNSS i protokół NMEA 0183}

Odbiornik GPS komunikuje się z mikrokontrolerem za pomocą protokołu NMEA 0183 – standardu opracowanego przez National Marine Electronics Association, używanego w nawigacji morskiej i lądowej \cite{wikipedia_nmea, geoforum_nmea}. Jest to protokół tekstowy, w którym dane przesyłane są w postaci czytelnych dla człowieka zdań ASCII.

Moduł u-blox NEO-6M wysyła dane przez port szeregowy z prędkością 9600 bitów na sekundę \cite{ublox_datasheet}. Dane te mają postać tekstowych linii rozpoczynających się od znaku dolara (\$), zawierających kod identyfikacyjny oraz pola oddzielone przecinkami.

Najważniejsze typy ramek wykorzystywane w projekcie to:

\begin{itemize}
    \item \textbf{\$GPGGA} – zawiera podstawowe dane o pozycji: szerokość geograficzną, długość geograficzną, wysokość nad poziomem morza oraz liczbę widocznych satelitów. To te informacje, które odpowiadają na pytanie "gdzie jestem?" \cite{elektropraktyk_nmea}.
    \item \textbf{\$GPRMC} – dostarcza dane o ruchu: prędkość przemieszczania się oraz kierunek jazdy (kurs). Dzięki tym danym można wyświetlić strzałkę wskazującą kierunek poruszania się.
\end{itemize}

ESP32 posiada sprzętowe porty UART, które automatycznie odbierają dane w tle \cite{esp32_trm}. Oznacza to, że procesor nie musi ciągle sprawdzać, czy nadeszły nowe dane – specjalny układ UART robi to automatycznie i informuje procesor, gdy cała ramka została odebrana. To znacznie odciąża główny procesor i zapewnia stabilność działania.

\subsection{Magistrale komunikacyjne w systemach wbudowanych}

W projekcie wykorzystano trzy różne standardy komunikacji, każdy wybrany do konkretnego zadania:

\textbf{I2C (Inter-Integrated Circuit)} to magistrala, która wykorzystuje tylko dwa przewody: jeden do przesyłania danych (SDA), drugi do synchronizacji czasowej (SCL) \cite{wonderfulpcb_protocols}. Największą zaletą I2C jest możliwość podłączenia wielu urządzeń do tych samych dwóch przewodów – każde urządzenie ma swój unikalny adres i reaguje tylko na komunikaty skierowane do niego.

W trackerze na jednej magistrali I2C pracują jednocześnie wyświetlacz OLED oraz czujnik ruchu IMU. Mikrokontroler rozróżnia je po adresach. I2C jest idealne dla urządzeń znajdujących się blisko siebie, które nie wymagają bardzo szybkiego przesyłu danych – typowa prędkość to do 400 tysięcy bitów na sekundę, co w zupełności wystarcza dla wyświetlaczy i czujników \cite{ourpcb_i2c_spi}.

\vspace{0.5cm}
\textbf{SPI (Serial Peripheral Interface)} to magistrala synchroniczna zaprojektowana do szybkiego przesyłu danych. Wykorzystuje cztery linie komunikacyjne i może przesyłać dane jednocześnie w obu kierunkach (tzw. komunikacja dwukierunkowa) \cite{wonderfulpcb_protocols}.

SPI zostało wybrane do obsługi karty pamięci SD, ponieważ zapis danych wymaga szybkiego transferu – karta SD może przyjmować dane z prędkością kilku do kilkudziesięciu megabitów na sekundę \cite{ourpcb_i2c_spi}. To znacznie szybciej niż I2C, dlatego dla karty pamięci jest to najlepszy wybór.

\vspace{0.5cm}
\textbf{UART (Universal Asynchronous Receiver-Transmitter)} to port szeregowy wykorzystujący dwa przewody: jeden do wysyłania danych (TX), drugi do odbierania (RX) \cite{elektropraktyk_uart}. Komunikacja odbywa się bez wspólnej linii zegarowej – oba urządzenia muszą być po prostu skonfigurowane na tę samą prędkość transmisji.

W projekcie UART obsługuje moduł GPS. ESP32 posiada sprzętowe porty UART, co oznacza, że odbiór danych odbywa się automatycznie przez dedykowany układ elektroniczny \cite{esp32_trm}. Procesor nie musi ciągle sprawdzać, czy nadeszły nowe dane – układ sam go powiadomi. To zapewnia stabilność odbioru danych nawet przy intensywnej pracy procesora.

UART jest prosty, niezawodny i działa nawet na większych odległościach (przy odpowiednio niższych prędkościach). Jest idealny dla urządzeń, które wymagają prostego, dwukierunkowego połączenia między dwoma urządzeniami.

\section{Implementacja oprogramowania}

\subsection{Opis funkcjonalności i obsługa aplikacji}
Aplikacja webowa stanowi główne centrum sterowania urządzeniem. Poniżej przedstawiono szczegółowy opis interfejsu oraz dostępnych funkcji, które zostały zaimplementowane w celu zapewnienia intuicyjnej obsługi.

\subsubsection{Ekran główny i parametry na żywo}

Po nawiązaniu połączenia z siecią Wi-Fi urządzenia, w prawym górnym rogu aplikacji widoczny jest status "POŁĄCZONO". W przypadku utraty zasięgu lub zerwania połączenia, komunikat natychmiast zmienia się na "ROZŁĄCZONO", informując użytkownika o braku aktualnej synchronizacji danych.

Ekran główny został podzielony na dwie sekcje logiczne: mapę z aktualną pozycją (wykorzystującą bibliotekę Leaflet) oraz panel parametrów telemetrycznych.

Na panelu dolnym wyświetlane są kluczowe parametry odświeżane w czasie rzeczywistym:
\begin{itemize}
    \item \textbf{Prędkość:} Aktualna prędkość przemieszczania się wyrażona w km/h.
    \item \textbf{Wysokość:} Wysokość nad poziomem morza w metrach.
    \item \textbf{Dystans:} Całkowita długość trasy przebyta w bieżącej sesji.
    \item \textbf{Satelity:} Liczba widocznych i używanych do nawigacji satelitów, co pozwala ocenić jakość "fixa".
    \item \textbf{HDOP:} Parametr precyzji geometrycznej (im niższy, tym lepiej).
    \item \textbf{Bateria:} Napięcie ogniwa zasilającego, pozwalające monitorować stan naładowania.
\end{itemize}

W sytuacji, gdy urządzenie nie posiada jeszcze ustalonej pozycji GPS (np. zaraz po włączeniu wewnątrz budynku), na ekranie widnieje wyraźny komunikat o szukaniu sygnału GPS.

\begin{figure}[H]
    \centering
    
    \caption{Ekran startowy aplikacji - system gotowy do pracy}
    \label{fig:app_start}
\end{figure}

\textbf{Proces nagrywania trasy}

Sterowanie procesem rejestracji odbywa się za pomocą centralnego przycisku \textbf{"START"}. Rozpoczęcie nagrywania aktywuje rysowanie śladu na mapie oraz zliczanie statystyk sesji. Aplikacja udostępnia również funkcję centrowania mapy – specjalny przycisk pozwala jednym kliknięciem przywrócić widok na aktualną pozycję GPS, co jest przydatne po ręcznym przesuwaniu mapy w celu podejrzenia okolicy.

System obsługuje zaawansowane funkcje pauzowania:
\begin{itemize}
    \item \textbf{Pauza manualna:} Użytkownik może w każdej chwili ręcznie wstrzymać zapis przyciskiem "PAUZA".
    \item \textbf{Auto-Pauza:} System automatycznie wykrywa brak ruchu i wstrzymuje zapis, co jest sygnalizowane pomarańczowym komunikatem "PAUZA / AUTO-PAUZA" na mapie. Zapobiega to rejestrowaniu błędnych punktów podczas postojów.
\end{itemize}

Po zakończeniu aktywności użytkownik ma do wyboru trzy opcje:
\begin{enumerate}
    \item \textbf{WZNÓW:} Powrót do nagrywania w ramach tej samej sesji.
    \item \textbf{ZAPISZ:} Trwałe zapisanie zgromadzonych danych do pliku w pamięci urządzenia.
    \item \textbf{ODRZUĆ:} Anulowanie sesji i usunięcie tymczasowych danych bez zapisu.
\end{enumerate}

\begin{figure}[H]
    \centering
    \begin{minipage}{0.45\textwidth}
        \centering
        
        \caption{Trwająca sesja z rysowaną trasą}
    \end{minipage}\hfill
    \begin{minipage}{0.45\textwidth}
        \centering
        
        \caption{Stan wstrzymania nagrywania (Pauza)}
    \end{minipage}
\end{figure}

\textbf{Wykresy i analiza trendów}

Dla bardziej wnikliwej analizy aktywności, aplikacja udostępnia sekcję wykresów rysowanych na żywo. Pozwala to na bieżąco śledzić historię parametrów:
\begin{itemize}
    \item Profil prędkości w czasie.
    \item Profil wysokości n.p.m.
    \item Wykres precyzji GPS (HDOP).
    \item Odczyty z akcelerometru (siły przeciążeń).
\end{itemize}

\begin{figure}[H]
    \centering
    
    \caption{Wykresy parametrów telemetrycznych}
    \label{fig:app_charts}
\end{figure}

\subsubsection{Zarządzanie plikami i historia tras}

Druga zakładka interfejsu, "PLIKI / HISTORIA", dedykowana jest zarządzaniu danymi zgromadzonymi na karcie SD. Użytkownik otrzymuje pełną kontrolę nad archiwum tras bez konieczności wyjmowania karty z urządzenia.

Dostępne funkcjonalności obejmują:
\begin{itemize}
    \item \textbf{Odświeżanie listy:} Pobranie aktualnego wykazu plików z karty SD.
    \item \textbf{Pobieranie:} Transfer wybranego pliku .csv/.txt bezpośrednio do pamięci telefonu/komputera.
    \item \textbf{Usuwanie:} Trwałe usunięcie niepotrzebnych plików.
    \item \textbf{Podgląd:} Specjalny tryb wizualizacji archiwalnej sesji.
\end{itemize}

\begin{figure}[H]
    \centering
    
    \caption{Lista zapisanych plików}
\end{figure}

W trybie \textbf{podglądu pliku} interfejs prezentuje kompletny ślad trasy na mapie oraz rozszerzony zestaw statystyk, niedostępnych w trybie na żywo, takich jak:
\begin{itemize}
    \item \textbf{Średnia prędkość:} Wartość wyliczona dla całej trasy, z uwzględnieniem postojów (auto-pauza).
    \item \textbf{Suma wzniosów i spadków:} Łączna różnica wysokości pokonana podczas sesji.
    \item \textbf{Maksymalna wysokość:} Najwyższy punkt osiagnięty na trasie (max AMSL).
    \item \textbf{Dystans:} Całkowita długość trasy.
    \item \textbf{Średnie HDOP:} Średnia wartość precyzji pomiaru z całego zapisu, pozwalająca ocenić wiarygodność danych.
\end{itemize}

\begin{figure}[H]
    \centering
    
    \caption{Tryb podglądu historii z dodatkowymi parametrami}
\end{figure}

Dodatkowo, w trybie podglądu użytkownik ma dostęp do szczegółowych wykresów analizujących przebieg całej trasy. Są to te same wykresy co w trybie na żywo (prędkość, wysokość, HDOP), ale przedstawiające kompletne dane z całego nagrania, co pozwala na łatwą identyfikację kluczowych momentów wycieczki.

\begin{figure}[H]
    \centering
    
    \caption{Szczegółowa analiza wykresów w trybie przeglądania historii}
    \label{fig:history_charts}
\end{figure}

Dane zapisywane są na karcie SD w formacie CSV (Comma Separated Values), co umożliwia ich łatwy import do arkuszy kalkulacyjnych (np. Excel) lub specjalistycznego oprogramowania GIS. Każda linia w pliku odpowiada jednemu punktowi pomiarowemu i zawiera następujące pola, oddzielone przecinkami:
\begin{itemize}
    \item \textbf{Czas (ms):} Czas systemowy w milisekundach od uruchomienia urządzenia.
    \item \textbf{Szerokość i Długość geograficzna:} Współrzędne GPS (format dziesiętny).
    \item \textbf{Prędkość (km/h):} Chwilowa prędkość ruchu.
    \item \textbf{Wysokość (m n.p.m.):} Wysokość nad poziomem morza.
    \item \textbf{HDOP:} Precyzja pomiaru poziomego (im mniejsza wartość, tym lepiej).
    \item \textbf{Satelity:} Liczba widocznych satelitów użytych do ustalenia pozycji.
    \item \textbf{Akcelerometr (ax, ay, az):} Surowe dane z czujnika przeciążeń dla trzech osi.
    \item \textbf{Bateria (V):} Napięcie zasilania w momencie pomiaru.
\end{itemize}

Przykładowa struktura linii danych:
\begin{verbatim}
millis,lat,lon,speed,alt,hdop,sats,ax,ay,az,batt
34500,52.2297,21.0122,15.5,112.4,1.2,8,0.02,-0.98,0.15,4.12
\end{verbatim}

\textbf{Integracja z wyświetlaczem OLED}

Niezależnie od aplikacji mobilnej, urządzenie wyposażone jest w fizyczny ekran OLED. Pełni on funkcję pomocniczą, prezentując najważniejsze informacje w zwięzłej formie:
\begin{itemize}
    \item Aktualny status: Oczekiwanie / Nagrywanie / Pauza.
    \item Liczba widocznych satelitów (ikona "SAT").
    \item Bieżąca prędkość oraz przebyty dystans.
    \item Adres IP oraz nazwa sieci WiFi (SSID) w celu ułatwienia połączenia.
\end{itemize}

\begin{figure}[H]
    \centering
    
    \caption{Przykładowy wygląd ekranu OLED prezentujący status urządzenia}
    \label{fig:oled_screen}
\end{figure}

\subsection{Szczegóły techniczne implementacji}

\textbf{Architektura wielowątkowa}

Oprogramowanie zostało zrealizowane w środowisku PlatformIO (C++) na układzie ESP32, który posiada dwa rdzenie. Pozwoliło to na podział zadań:
\begin{itemize}
    \item \textbf{Rdzeń 0 (Komunikacyjny):} Obsługuje WiFi i serwer strony internetowej. Dzięki temu, gdy użytkownik przegląda mapę na telefonie, nie obciąża to głównego procesu zapisu.
    \item \textbf{Rdzeń 1 (Logiczny):} Zajmuje się tylko tym, co najważniejsze - odbieraniem danych z GPS i zapisywaniem ich na kartę.
\end{itemize}

\vspace{0.5cm}
\textbf{Bezpieczeństwo i wielozadaniowość (Mutex)}

Aby dwa rdzenie nie próbowały jednocześnie pisać na tę samą kartę SD (co mogłoby ją uszkodzić), zastosowano mechanizm Mutex. Działa on jak cyfrowy "klucz" - tylko jeden proces może mieć do niego dostęp w danym momencie. Jeśli WiFi chce odczytać plik, musi poczekać, aż GPS skończy zapamiętywać pozycję.

\vspace{0.5cm}
\textbf{Logika sterowania (Maszyna Stanów)}

System działa w trzech, ściśle określonych trybach, co zapobiega błędom:
\begin{itemize}
    \item \textbf{IDLE (Czuwanie):} Urządzenie działa i pokazuje dane, ale nie zapisuje plików.
    \item \textbf{RECORDING (Nagrywanie):} Główny tryb wycieczkowy - dane są zapisywane na kartę.
    \item \textbf{PAUSED (Pauza):} Wstrzymanie zapisu. Ważne jest to, że przejście w tryb pauzy wymusza "zrzut" (Flush) wszystkich danych na kartę, więc nagłe wyłączenie urządzenia nie spowoduje utraty ostatniego fragmentu trasy.
\end{itemize}

\vspace{0.5cm}
\textbf{Interfejs WWW (SPA)}

Strona internetowa ładuje się z pamięci urządzenia tylko raz. Potem telefon pobiera w tle już tylko same liczby (prędkość, pozycję). Dzięki temu interfejs działa płynnie nawet na słabszym zasięgu, a bateria trackera jest oszczędzana.

\vspace{0.5cm}
\textbf{Bezpieczeństwo Zapisu}

Dane zbierane są w pamięci RAM, a na kartę SD zrzucane są w większych paczkach co 10 sekund. Chroni to kartę przed zużyciem, a nazwy plików tworzone są automatycznie z daty i godziny.

\vspace{0.5cm}
\textbf{Stabilność i Watchdog}

System ignoruje "pływanie" GPS na postoju (Filtr Histerezowy). Dodatkowo, funkcja "Watchdog" restertuje moduł WiFi w razie problemów z połączeniem, nie przerywając przy tym nagrywania trasy.

\section{Testy i analiza wyników}

W celu weryfikacji założeń projektowych przeprowadzono serię testów sprawdzających niezawodność urządzenia w warunkach rzeczywistych. Skupiono się na trzech krytycznych aspektach: czasie akwizycji sygnału GPS, odporności na błędy zapisu oraz wydajności energetycznej.

\subsection{Testy modułu GPS (Cold Start vs Hot Start)}
Jednym z kluczowych parametrów użytkowych lokalizatora jest czas oczekiwania na ustalenie pierwszej pozycji (Time To First Fix - TTFF). Procedura testowa obejmowała uruchomienie urządzenia w otwartej przestrzeni po długim okresie nieaktywności (powyżej 4 godzin).

\begin{itemize}
    \item \textbf{Cold Start (Zimny start):} Moduł uruchamia się "na ślepo" - nie wie, gdzie się znajduje,
     ani gdzie na niebie szukać satelitów. Musi dopiero pobrać te dane z sygnału GPS. 
     aobserwowane czasy oczekiwania wynosiły od 1 do 5 minut.  
    \item \textbf{Hot Start:} Po krótkim zaniku zasilania (poniżej 30 minut) moduł odzyskuje fix niemal natychmiastowo (zazwyczaj poniżej 5 sekund), co potwierdza poprawność działania układu zasilania.
\end{itemize}

Jak wskazują badania porównawcze \cite{gps_comparison_2025}, moduł NEO-6M, mimo bycia rozwiązaniem budżetowym, oferuje dokładność porównywalną do droższych sensorów (np. Walksnail WS-M181). Głównymi wadami wymienianymi w literaturze, a potwierdzonymi w niniejszym projekcie, są długi czas zimnego startu (wyszukiwania satelitów) oraz niższa częstotliwość odświeżania. Jednakże, jak zauważają autorzy badania, wady te nie są krytyczne w typowych zastosowaniach amatorskich i przy pomiarach w punktach statycznych.

\subsection{Analiza jakości śladu w ruchu}
Testy wykazały, że o ile w warunkch, gdzie emodoł jest donbrze widoczny urządzenie radzi sobie bardzo dobrze, 
to podczas aktywności bardziej dynamicznych (np. bieg) 
lub przy okresowym przesłanianiu anteny, jakość sygnału zauważalnie spada.

W momentach, gdy antena jest zasłaniana (np. przez ciało biegacza lub gęste korony drzew), na mapie mogą pojawiać się nieprawdziwe trasy (artefakty), odbiegające od rzeczywistego toru poruszania się. Towarzyszą temu również błędne odczyty prędkości chwilowej. Jest to zjawisko wynikające z chwilowej utraty widoczności satelitów i jest typowe dla odbiorników GPS tej klasy bez wspomagania systemami inercyjnymi.

\subsection{Bilans energetyczny i czas pracy}
Urządzenie zasilane jest ogniwem Li-Ion 18650 o pojemności nominalnej 2600 mAh.
Szacunkowy pobór prądu przez poszczególne moduły:
\begin{itemize}
    \item ESP32 (z WiFi w trybie AP+STA): ok. 150-200 mA \cite{esp32_power}
    \item Moduł GPS: ok. 40 mA \cite{roboticsbd_neo6m}
    \item OLED i czujniki: ok. 10-15 mA \cite{bitbank_oled}
\end{itemize}
Łączny pobór prądu oscyluje w granicach 250 mA. Uwzględniając sprawność przetwornicy Step-Up (ok. 85\%), realny czas pracy wynosi:
\[
T \approx \frac{2600 mAh}{250 mA} \cdot 0.85 \approx 8.8 h
\]
Jest to wynik satysfakcjonujący dla jednodniowej wycieczki rowerowej lub pieszego monitoringu.

\section{Podsumowanie i wnioski}

\subsection{Wnioski końcowe}
Przeprowadzone testy i analiza działania prototypu pozwalają na sformułowanie następujących wniosków:

\begin{enumerate}
    \item \textbf{Stabilność działania:} Dzięki wykorzystaniu dwóch rdzeni procesora ESP32, urządzenie działa płynnie. Nagrywanie trasy na kartę odbywa się niezależnie od obsługi WiFi, więc korzystanie z podglądu na telefonie nie zakłóca zapisu danych.
    \item \textbf{Prosty i szybki interfejs:} Strona WWW została napisana tak, aby nie obciążać procesora. Telefon pobiera tylko surowe liczby, a nie całą grafikę, dzięki czemu aplikacja działa szybko i nie zacina się.
    \item \textbf{Jakość modułu GPS:} Tani moduł NEO-6M jest wystarczający do turystyki pieszej i zastosowań amatorskich. W testach statycznych wykazuje wysoką precyzję, jednak w dynamicznym ruchu (bieg) i trudnym terenie (las) jego dokładność spada, co jest typowe dla odbiorników bez wspomagania inercyjnego.
    \item \textbf{Efektywność energetyczna:} Osiągnięty czas pracy na poziomie ok. 9 godzin przy zasilaniu z jednego ogniwa 18650 (z przetwornicą) czyni urządzenie praktycznym w jednodniowych zastosowaniach.
    \item \textbf{Obudowa 3D:} Zaprojektowana obudowa jest kompaktowa i funkcjonalna. Chroni elektronikę przed uszkodzeniami mechanicznymi, zapewniając jednocześnie łatwy dostęp do portu ładowania i karty pamięci.
\end{enumerate}

\subsection{Podsumowanie działania}
Zrealizowany system działa w pełni poprawnie i spełnił wszystkie założenia oraz cel pracy. Urządzenie pomyślnie przeszło testy terenowe, rejestrując trasy bez awarii. Projekt udowodnił, że wykorzystując tanie i ogólnodostępne moduły (ESP32, NEO-6M), można zbudować narzędzie telemetryczne o funkcjonalności zbliżonej do prostych urządzeń komercyjnych.

Dodatkową wartością projektu jest jego aspekt edukacyjny. 
Budowa urządzenia wymagała połączenia wiedzy z zakresu elektroniki,
 druku 3D oraz programowania systemów wbudowanych i aplikacji webowych. 
 Powstały prototyp jest nie tylko działającym urządzeniem, ale także solidną platformą 
 do dalszego rozwoju, np. poprzez dodanie modułu GSM w przyszłości.

\newpage
\begin{thebibliography}{99}

\bibitem{ublox_datasheet}
u-blox AG. \textit{NEO-6 u-blox 6 GPS Modules – Data Sheet} (GPS.G6-HW-09005). 2011.

\bibitem{sensors_edge}
Design and Implementation of ESP32-Based Edge Computing for Object Detection. \textit{Sensors}, vol. 25, no. 6, p. 1656, 2025. DOI: 10.3390/s25061656.

\bibitem{botland_esp32}
Botland. \textit{ESP32 - Co to jest i do czego służy?} 2024. [Online]. Dostępne: \url{https://botland.com.pl/blog/esp32-co-to-jest-i-do-czego-sluzy/}

\bibitem{electronics_lang}
Performance Evaluation of Programming Languages on ESP32 Microcontroller. \textit{Electronics}, vol. 12, no. 1, p. 143, 2022.

\bibitem{esp32_trm}
Espressif Systems. \textit{ESP32 Technical Reference Manual}. 2024. [Online]. Dostępne: \url{https://www.espressif.com/sites/default/files/documentation/esp32_technical_reference_manual_en.pdf}

\bibitem{msalamon_rodziny}
MSalamon.pl. \textit{ESP32 od Podstaw – Przegląd Rodzin Układów i Ich Najważniejszych Cech}. 2025. [Online]. Dostępne: \url{https://sklep.msalamon.pl/blog/esp32-od-podstaw-przeglad-rodzin-ukladow-i-ich-najwazniejszych-cech/}

\bibitem{wikipedia_nmea}
Wikipedia. \textit{NMEA 0183 – Wikipedia, wolna encyklopedia}. 2005. [Online]. Dostępne: \url{https://pl.wikipedia.org/wiki/NMEA_0183}

\bibitem{elektropraktyk_nmea}
Elektro-Praktyk. \textit{System nawigacji satelitarnej GPS, część 8 – Protokół NMEA-0183}. 2013.

\bibitem{geoforum_nmea}
Geoforum.pl. \textit{Uniwersalny język nawigacji – Standard NMEA-0183 w odbiornikach GPS}. (b.d.).

\bibitem{elektropraktyk_uart}
Elektro-Praktyk. \textit{UART na SPI/I2C – Zestawienie cech i parametrów mostków komunikacyjnych}. 2013.

\bibitem{wonderfulpcb_protocols}
WonderfulPCB. \textit{Wybór właściwego protokołu komunikacyjnego: I2C, SPI lub UART}. 2025. [Online]. Dostępne: \url{https://www.wonderfulpcb.com/pl/blog/i2c-communication-protocol-vs-spi-vs-uart-comparison-guide/}

\bibitem{ourpcb_i2c_spi}
OurPCB. \textit{I2C vs SPI: Różnice, które powinieneś znać}. (b.d.). [Online]. Dostępne: \url{https://ourpcb.pl/i2c-vs-spi.html}

\bibitem{gps_comparison_2025}
Comparative Experimental Evaluation of the Error of GPS Modules. \textit{Automatic Control and Power Systems}, vol. 10, no. 2, 2025. [Online]. Dostępne: \url{https://science.lpnu.ua/acps/all-volumes-and-issues/volume-10-number-2-2025/comparative-experimental-evaluation-error-gps}

\bibitem{esp32_power}
DeepBlueEmbedded. \textit{ESP32 Sleep Modes \& Power Consumption}. (b.d.). [Online]. Dostępne: \url{https://deepbluembedded.com/esp32-sleep-modes-power-consumption-in-each-mode/}

\bibitem{roboticsbd_neo6m}
Robotics Bangladesh. \textit{GPS Module NEO-6M Satellite Positioning Module}. (b.d.). [Online]. Dostępne: \url{https://roboticsbd.com/electronics-module/2397-gps-module-neo-6m-satellite-positioning-module-for-arduino-with-microusb-robotics-bangladesh-roboticsbd-745.html}

\bibitem{bitbank_oled}
BitBank Software. \textit{How much current do OLED displays use?}. 2019. [Online]. Dostępne: \url{https://bitbanksoftware.blogspot.com/2019/06/how-much-current-do-oled-displays-use.html}

\end{thebibliography}

\end{document}

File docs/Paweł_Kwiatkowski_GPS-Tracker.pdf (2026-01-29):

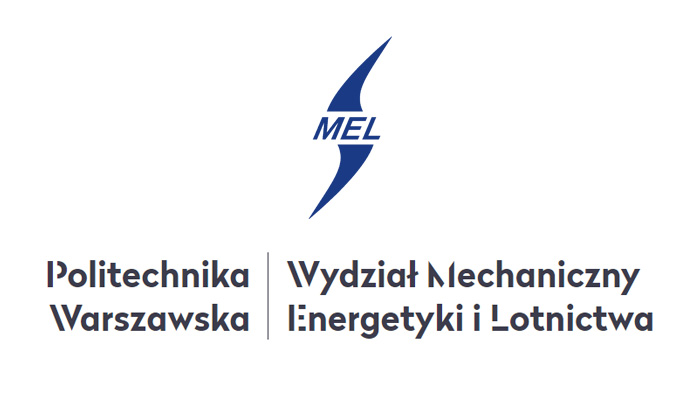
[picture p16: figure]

# Praca przejsciowa ´

# magisterska

## Projekt i realizacja autonomicznego rejestratora parametrów ruchu GPS z interfejsem bezprzewodowym opartym o układ ESP32

## Paweł Kwiatkowski

promotor
[...]

WARSZAWA 2026

Streszczenie

Celem niniejszej pracy inzynierskiej jest zaprojektowanie i realizacja autonomicznego rejes- ˙ tratora parametrów ruchu GPS, wyposazonego w zintegrowany interfejs bezprzewodowy WiFi. ˙ Urz ądzenie, oparte na dwurdzeniowym mikrokontrolerze ESP32, ł ączy w sobie funkcjonalnosć´ klasycznego "data-loggera" zapisuj ącego dane na karcie pamięci SD z nowoczesn ą wizualizacj ą parametrów w czasie r zeczywistym poprzez dedykowan ą stronę internetow ą (Web Interface).
W ramach projektu opracowano kompletn ą warstwę sprzętow ą, integruj ąc ą moduł nawigacji satelitarnej NEO-6M, czujnik inercyjny IMU (MPU6050) oraz wyswietlacz OLED. Praca opisuje ´ równiez proces projektowania ergonomicznej obudowy oraz jej wykonanie w technologii druku ˙
3D. Przeprowadzone testy terenowe potwierdziły poprawnosć działania prototypu, stabilno ´ | sć re- ´
jestracji sladu oraz satysfakcjonuj ący czas pracy na zasilaniu bateryjnym. ´

## Spis tresci ´

1 Wstęp | 3
1.1 Cel pracy i załozenia projektowe | | 3 ˙
2 Projekt sprzętowy | 3
2.2 Konfiguracja interfejsów i poł ączen | | 3 ´
3 Przegl ąd technologii i narzędzi | 9
4 Implementacja oprogramowania | 11
4.1 Opis funkcjonalnosci i obsługa aplikacji | | 11 ´
4.1.1 | Ekran główny i parametry na zywo | | 11 ˙
5 Testy i analiza wyników | 19
5.2 Analiza jakosci ´ sladu w ruchu | | 19 ´
6 Podsumowanie i wnioski | 20
6.1 Wnioski koncowe | | 20 ´

## 1 Wstęp

### 1.1 Cel pracy i załozenia projektowe ˙

Celem tej pracy jest zaprojektowanie i zbudowanie urz ądzenia typu “GPS Tracker". Urz ądzenie
ma rejestrowac trasę, monitorowa ´ | c parametry ruchu i pokazywa ´ | c dane w czasie rzeczywistym. ´
Głównym załozeniem projektu było stworzenie systemu autonomicznego, zasilanego bateryjnie, ˙ który ł ączy w sobie funkcjonalnosć klasycznego rejestratora danych z nowoczesnym interfejsem ´ uzytkownika dostępnym przez przegl ądarkę internetow ą (Web Interface). ˙

### 1.2 Koncepcja architektury systemu telemetrycznego

W niniejszym projekcie przyjęto załozenie, ˙ ze urz ądzenie nie tylko gromadzi surowe dane po- ˙ miarowe, ale działa jako niezalezny serwera aplikacj i udostępnia pełny graficzny interfejs. To ˙ wymusiło rezygnację z prostych mikrokontrolerów 8-bitowych na rzecz wydajniejszych jednostek obliczeniowych, ł ącz ących wiele funkcji (w tym bezprzewodow ą ł ącznosć) w jednym układzie ´ scalonym.
Do realizacji zadania wybrano platformę ESP32, kieruj ąc się jej unikaln ą architektur ą dwurdzeniow ą. Pozwala ona na separację procesów krytycznych (obsługa przerwan GPS i IMU) od ob- ´
sługi stosu sieciowego WiFi, co jest wazne, ˙ | zeby dane były zapisywane ci ągle. Dodatkowo, wysoki ˙
stopien integracji w jednym układzie pozwolił zminimalizowa ´ | c wymiary urz ądzenia oraz upro ´ | sci ´ c´
układ oraz obnizy˙ c cene ´

## 2 Projekt sprzętowy

Warstwa sprzętowa urz ądzenia została zaprojektowana w sposób modułowy, co ułatwia diagnostykę oraz ewentualn ą wymianę komponentów. System składa się z następuj ących komponentów:

### 2.1 Elementy układu

- Mikrokontroler: ESP32 DevKit V1 WROOM-32 – dwurdzeniowy procesor z WiFi i Bluetooth
- Moduł GPS: NEO-6M V2 – odbiornik satelitarny (komunikacja UART)
- IMU (czujnik ruchu): MPU6050 – akcelerometr i zyroskop 6-osiowy (I2C) ˙
- Wyswietlacz: ´ | OLED 0.96" – monochromatyczny ekran 128x64 px (I2C)
- Pamięc masowa: ´ | Micro SD Card Module – czytnik kart MicroSD (SPI)
- Zasilanie: Ładowarka Li-Ion z wejsciem USB-C i zabezpieczeniami, współpracuj ąca z ogni- ´
wem 18650. Układ umozliwia ładowanie baterii lub zasilanie systemu bezpo ˙ | srednio z portu ´
USB.

### 2.2 Konfiguracja interfejsów i poł ączen´

Wszystkie moduły peryferyjne zostały poł ączone z mikrokontrolerem zgodnie z zał ączonym schematem elektrycznym. Kluczowym wymogiem poprawnosci działania układu jest poł ączenie wszyst- ´ kich mas (GND) w jeden wspólny potencjał.


Rysunek 1: Schemat elektryczny systemu

Magistrala I2C (OLED + MPU6050): Urz ądzenia podł ączone równolegle do wspólnych linii SDA i SCL.

Urz ądzenie | Pin Modułu | Pin ESP32 | Uwagi
OLED 0.96" | SDA SCL VCC GND | GPIO 21 GPIO 22 3.3V GND | Adres I2C: 0x3C Z pinu 3V3 ESP32 Wspólna masa
MPU6050 (IMU) | SDA SCL VCC GND | GPIO 21 GPIO 22 5V GND | Adres I2C: 0x68 Z pinu 5V OUT power module Wspólna masa

Tabela 1: Konfiguracja magistrali I2C

Moduł GPS NEO-6M V2 (UART): Wykorzystuje sprzętowy port szeregowy UART2.

Pin Modułu GPS | Pin ESP32 | Funkcja
TX RX VCC GND | GPIO 16 (RX2) GPIO 17 (TX2) 3.3V GND | Transmisja z GPS do ESP32 Konfiguracja GPS (opcjonalna) Z pinu 3V3 ESP32 Wspólna masa

Tabela 2: Poł ączenie modułu GPS

Micro SD Card Module (SPI): Wykorzystuje standardow ą magistralę VSPI.

Pin Modułu SD | Pin ESP32 | Funkcja
CS SCK MISO MOSI VCC GND | GPIO 5 GPIO 18 GPIO 19 GPIO 23 3.3V GND | Chip Select Zegar synchronizacji Dane (Master In, Slave Out) Dane (Master Out, Slave In) Z pinu 3V3 ESP32 Wspólna masa

Tabela 3: Poł ączenie czytnika kart SD

### 2.3 Projekt obudowy

Obudowa urz ądzenia przeszła ewolucję od prototypu (Wersja 1) do wersji finalnej (Wersja 2), wprowadzaj ąc istotne usprawnienia w konstrukcji i ergonomii uzytkowania. Obie wersje zostały ˙ zaprojektowane w srodowisku Autodesk Inventor z przeznaczeniem do druku 3D. ´

### 2.3.1 Wersja 1 (Prototyp)

Pierwsza wersja obudowy składała się z wielu elementów: podstawy z komorami na moduły i ogniwo 18650, ramki montazowej oraz pokrywy z charakterystycznym wzorem plastra miodu. Pro- ˙ jekt zawierał dodatkow ą klapkę oraz otwory na kartę SD, które w praktyce okazały się zbędne lub problematyczne w druku.

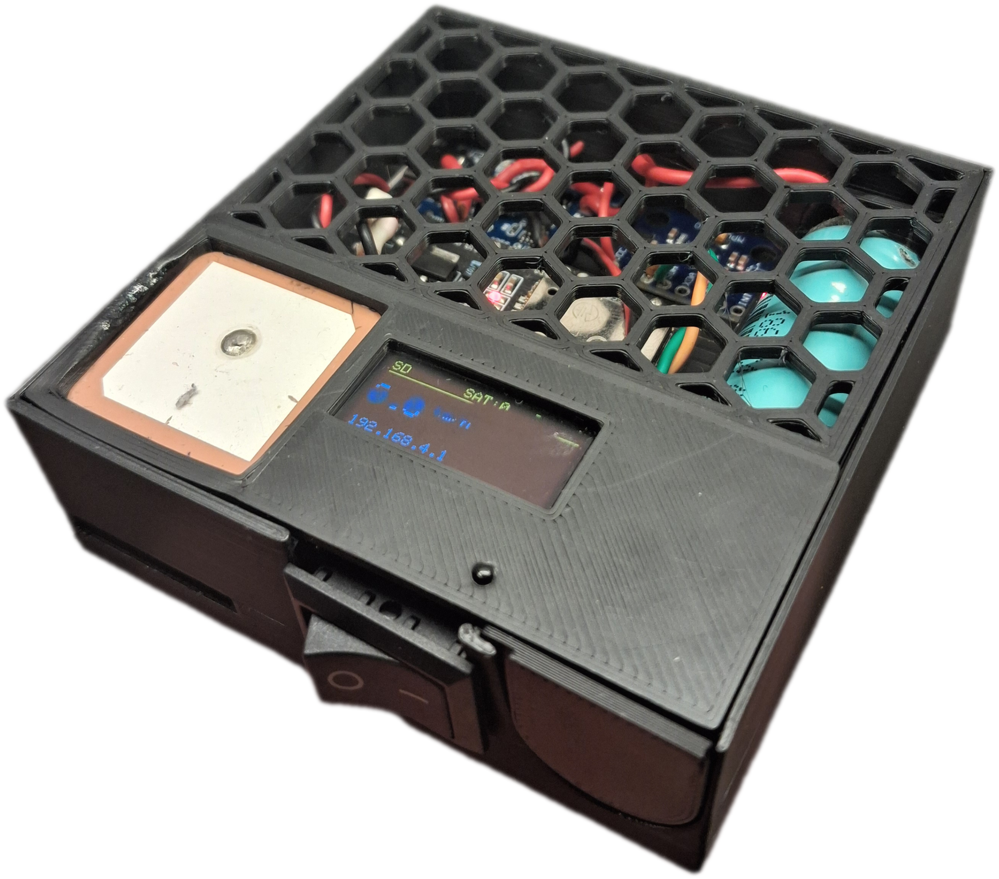
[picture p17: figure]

Rysunek 2: Fizyczny model prototypu V1

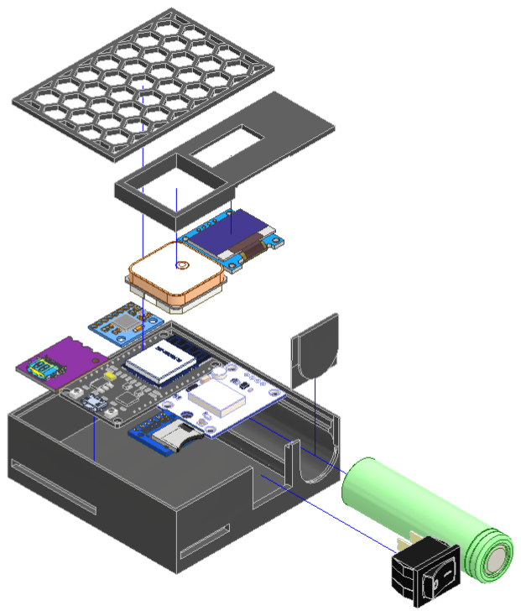
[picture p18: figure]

Rysunek 3: Widok rozstrzelony konstrukcji V1

### 2.3.2 Wersja 2 (Finalna)

W drugiej wersji wprowadzono szereg udoskonalen wynikaj ących z testów prototypu: ´

1. Uproszczona konstrukcja: Usunięto zbędn ą klapkę oraz otwory na kartę SD, co zwiększyło
sztywnosć i szczelno ´ | sć obudowy. ´
2. Zintegrowana pokrywa: Dwie oddzielne górne pokrywy zostały poł ączone w jeden solidny element.
3. Wzmocnione scianki ´ | : Zwiększono grubosć´ scianek, co poprawiło wytrzymało ´ | sć mechaniczn ą ´
wydruku.
4. Lepsze dopasowanie: Poprawiono spasowanie wszystkich elementów, eliminuj ąc luzy.
5. Dostęp do portów: Zoptymalizowano otwory na porty USB (dla ładowania i programowania), ułatwiaj ąc podł ączanie przewodów.

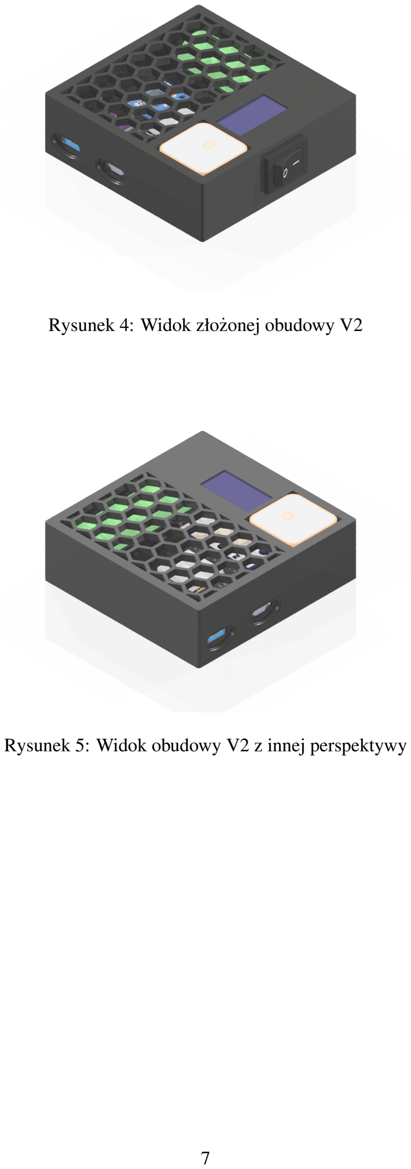
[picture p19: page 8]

Rysunek 4: Widok złozonej obudowy V2 ˙

Rysunek 5: Widok obudowy V2 z innej perspektywy

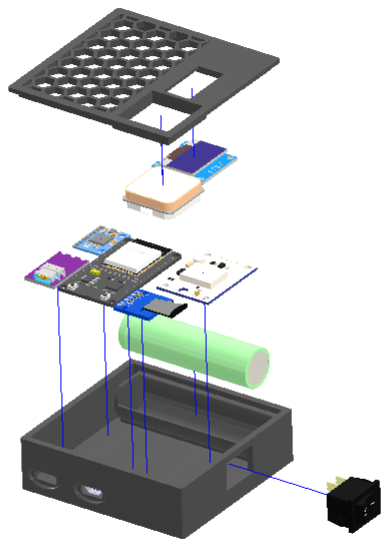
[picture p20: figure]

Rysunek 6: Widok rozstrzelony konstrukcji V2

## 3 Przegl ąd technologii i narzędzi

Budowa trackera GPS wymaga poł ączenia kilku róznych technologii komunikacyjnych. Poni ˙ | zej ˙
opisano kluczowe elementy systemu wykorzystane w projekcie.

### 3.1 Rozwój IoT i miniaturyzacja

Internet Rzeczy (IoT) to swiat poł ączonych urz ądze ´ | n – od zegarków, przez czujniki temperatury, ´
az po inteligentne zamki [3, 6]. Miniaturyzacja, czyli proces zmniejszania rozmiarów komponentów ˙
elektronicznych, umozliwiła budowę tak małych i wydajnych urz ądze ˙ | n.´
Moduł odbiornika GPS NEO-6M ma wymiary zaledwie 16 × 12,2 × 2,4 mm [1], co pozwala
zbudowac kompaktowy tracker. Mniejsze układy zu ´ | zywaj ą te ˙ | z znacznie mniej energii – urz ądzenie ˙
moze pracowa ˙ | c na baterii przez wiele godzin lub dni. Integracja wielu funkcji w jednym układzie ´
(System on Chip, w skrócie SoC) obniza koszty produkcji i zwiększa niezawodno ˙ | sć systemu. ´

### 3.2 Telemetria i przetwarzanie danych

Telemetria to technologia zbierania danych z odległych miejsc i przesyłania ich w czasie rzeczywistym. W przypadku trackera GPS oznacza to automatyczne odczytywanie pozycji i prędkosci bez ´ potrzeby fizycznego dostępu do urz ądzenia.
Przetwarzanie na miejscu (Edge Computing) to koncepcja, w której dane nie s ą od razu wysyłane do internetu, ale wstępnie analizowane bezposrednio w urz ądzeniu [2]. Mikrokontroler ESP32 od- ´ biera surowe dane z modułu GPS, przetwarza je – rozpoznaje współrzędne, oblicza prędkosć – i ´ zapisuje gotowe wyniki na karcie pamięci.
Dlaczego to wazne? Po pierwsze, oszczędza to energię baterii – zamiast ci ągle wysyła ˙ | c dane przez ´
siec (co zu ´ | zywa du ˙ | zo pr ądu), urz ądzenie analizuje je lokalnie i wysyła tylko niezbędne informacje. ˙
Po drugie, zwiększa to szybkosć reakcji – decyzje podejmowane s ą natychmiast, bez czekania na ´ odpowiedź z serwera.

### 3.3 Architektura ESP32

ESP32 to mikrokontroler firmy Espressif Systems, który posiada dwa niezalezne rdzenie proce- ˙
sora Xtensa LX6 pracuj ące z częstotliwosci ą do 240 MHz [5, 6]. W praktyce oznacza to, ´ | ze mo ˙ | ze˙
wykonywac dwa zadania jednocze ´ | snie, bez wzajemnego spowalniania się. ´
Jak to działa? Jeden rdzen mo ´ | ze zajmowa ˙ | c się obliczeniami – odbieraniem danych GPS, za- ´
pisywaniem ich na kartę pamięci, wyswietlaniem informacji na ekranie [4]. W tym samym czasie ´ drugi rdzen obsługuje komunikację bezprzewodow ą – Wi-Fi lub Bluetooth. Dzięki temu oba procesy ´ działaj ą płynnie i nie przeszkadzaj ą sobie nawzajem.
ESP32 posiada takze wbudowane moduły Wi-Fi i Bluetooth, co czyni go idealnym rozwi ązaniem ˙ dla projektów wymagaj ących bezprzewodowej komunikacji [3]. Dodatkowo, układ obsługuje za-
awansowane tryby oszczędzania energii – moze automatycznie "zasypia ˙ | c" gdy nie wykonuje zada ´ | n,´
pobieraj ąc mniej niz 10 mikroamperów pr ądu. ˙

### 3.4 System GNSS i protokół NMEA 0183

Odbiornik GPS komunikuje się z mikrokontrolerem za pomoc ą protokołu NMEA 0183 – standardu opracowanego przez National Marine Electronics Association, uzywanego w nawigacji ˙ morskiej i l ądowej [7, 9]. Jest to protokół tekstowy, w którym dane przesyłane s ą w postaci czytelnych dla człowieka zdan ASCII. ´

Moduł u-blox NEO-6M wysyła dane przez port szeregowy z prędkosci ą 9600 bitów na sekundę ´ [1]. Dane te maj ą postac tekstowych linii rozpoczynaj ących się od znaku dolara ($), zawieraj ących ´ kod identyfikacyjny oraz pola oddzielone przecinkami.
Najwazniejsze typy ramek wykorzystywane w projekcie to: ˙
- $GPGGA – zawiera podstawowe dane o pozycji: szerokosć geograficzn ą, długo ´ | sć ge- ´
ograficzn ą, wysokosć nad poziomem morza oraz liczbę widocznych satelitów. To te informacje, ´ które odpowiadaj ą na pytanie "gdzie jestem?" [8].
- $GPRMC – dostarcza dane o ruchu: prędkosć przemieszczania się oraz kierunek jazdy (kurs). ´
Dzięki tym danym mozna wy ˙ | swietli ´ | c strzałkę wskazuj ąc ą kierunek poruszania się. ´

ESP32 posiada sprzętowe porty UART, które automatycznie odbieraj ą dane w tle [5]. Oznacza
to, ze procesor nie musi ci ągle sprawdza ˙ | c, czy nadeszły nowe dane – specjalny układ UART robi to ´
automatycznie i informuje procesor, gdy cała ramka została odebrana. To znacznie odci ąza główny ˙ procesor i zapewnia stabilnosć działania. ´

### 3.5 Magistrale komunikacyjne w systemach wbudowanych

W projekcie wykorzystano trzy rózne standardy komunikacji, ka ˙ | zdy wybrany do konkretnego ˙
zadania:
I2C (Inter-Integrated Circuit) to magistrala, która wykorzystuje tylko dwa przewody: jeden do przesyłania danych (SDA), drugi do synchronizacji czasowej (SCL) [11]. Największ ą zalet ą I2C jest
mozliwo ˙ | sć podł ączenia wielu urz ądze ´ | n do tych samych dwóch przewodów – ka ´ | zde urz ądzenie ma ˙
swój unikalny adres i reaguje tylko na komunikaty skierowane do niego.
W trackerze na jednej magistrali I2C pracuj ą jednoczesnie wy ´ | swietlacz OLED oraz czujnik ruchu ´
IMU. Mikrokontroler rozróznia je po adresach. I2C jest idealne dla urz ądze ˙ | n znajduj ących się blisko ´
siebie, które nie wymagaj ą bardzo szybkiego przesyłu danych – typowa prędkosć to do 400 tysięcy ´
bitów na sekundę, co w zupełnosci wystarcza dla wy ´ | swietlaczy i czujników [12]. ´

SPI (Serial Peripheral Interface) to magistrala synchroniczna zaprojektowana do szybkiego
przesyłu danych. Wykorzystuje cztery linie komunikacyjne i moze przesyła ˙ | c dane jednocze ´ | snie w ´
obu kierunkach (tzw. komunikacja dwukierunkowa) [11].
SPI zostało wybrane do obsługi karty pamięci SD, poniewaz zapis danych wymaga szybkiego ˙
transferu – karta SD moze przyjmowa ˙ | c dane z prędko ´ | sci ą kilku do kilkudziesięciu megabitów na ´
sekundę [12]. To znacznie szybciej niz I2C, dlatego dla karty pamięci jest to najlepszy wybór. ˙

UART (Universal Asynchronous Receiver-Transmitter) to port szeregowy wykorzystuj ący dwa przewody: jeden do wysyłania danych (TX), drugi do odbierania (RX) [10]. Komunikacja odbywa się bez wspólnej linii zegarowej – oba urz ądzenia musz ą byc po prostu skonfigurowane na tę sam ą ´ prędkosć transmisji. ´
W projekcie UART obsługuje moduł GPS. ESP32 posiada sprzętowe porty UART, co oznacza, ze˙ odbiór danych odbywa się automatycznie przez dedykowany układ elektroniczny [5]. Procesor nie
musi ci ągle sprawdzac, czy nadeszły nowe dane – układ sam go powiadomi. To zapewnia stabilno ´ | sć´
odbioru danych nawet przy intensywnej pracy procesora.
UART jest prosty, niezawodny i działa nawet na większych odległosciach (przy odpowiednio ´
nizszych prędko ˙ | sciach). Jest idealny dla urz ądze ´ | n, które wymagaj ą prostego, dwukierunkowego ´
poł ączenia między dwoma urz ądzeniami.

## 4 Implementacja oprogramowania

### 4.1 Opis funkcjonalnosci i obsługa aplikacji ´

Aplikacja webowa stanowi główne centrum sterowania urz ądzeniem. Ponizej przedstawiono ˙ szczegółowy opis interfejsu oraz dostępnych funkcji, które zostały zaimplementowane w celu zapewnienia intuicyjnej obsługi.

### 4.1.1 Ekran główny i parametry na zywo ˙

Po nawi ązaniu poł ączenia z sieci ą Wi-Fi urz ądzenia, w prawym górnym rogu aplikacji widoczny jest status "POŁ ĄCZONO". W przypadku utraty zasięgu lub zerwania poł ączenia, komunikat natychmiast zmienia się na "ROZŁ ĄCZONO", informuj ąc uzytkownika o braku aktualnej synchronizacji ˙ danych.
Ekran główny został podzielony na dwie sekcje logiczne: mapę z aktualn ą pozycj ą (wykorzystuj ąc ą bibliotekę Leaflet) oraz panel parametrów telemetrycznych.
Na panelu dolnym wyswietlane s ą kluczowe parametry od ´ | swie ´ | zane w czasie rzeczywistym: ˙
- Prędkosć:´ Aktualna prędkosć przemieszczania się wyra ´ | zona w km/h. ˙
- Wysokosć:´ Wysokosć nad poziomem morza w metrach. ´
- Dystans: Całkowita długosć trasy przebyta w bie ´ | z ącej sesji. ˙
- Satelity: Liczba widocznych i uzywanych do nawigacji satelitów, co pozwala oceni ˙ | c jako ´ | sć´
"fixa".
- HDOP: Parametr precyzji geometrycznej (im nizszy, tym lepiej). ˙
- Bateria: Napięcie ogniwa zasilaj ącego, pozwalaj ące monitorowac stan naładowania. ´

W sytuacji, gdy urz ądzenie nie posiada jeszcze ustalonej pozycji GPS (np. zaraz po wł ączeniu wewn ątrz budynku), na ekranie widnieje wyraźny komunikat o szukaniu sygnału GPS.


Rysunek 7: Ekran startowy aplikacji - system gotowy do pracy

Proces nagrywania trasy
Sterowanie procesem rejestracji odbywa się za pomoc ą centralnego przycisku "START". Rozpoczęcie nagrywania aktywuje rysowanie sladu na mapie oraz zliczanie statystyk sesji. Aplikacja ´ udostępnia równiez funkcję centrowania mapy – specjalny przycisk pozwala jednym kliknięciem ˙ przywrócic widok na aktualn ą pozycję GPS, co jest przydatne po ręcznym przesuwaniu mapy w ´ celu podejrzenia okolicy.
System obsługuje zaawansowane funkcje pauzowania:
- Pauza manualna: Uzytkownik mo ˙ | ze w ka ˙ | zdej chwili ręcznie wstrzyma ˙ | c zapis przyciskiem ´
"PAUZA".
- Auto-Pauza: System automatycznie wykrywa brak ruchu i wstrzymuje zapis, co jest sygnalizowane pomaranczowym komunikatem "PAUZA / AUTO-PAUZA" na mapie. Zapobiega to ´ rejestrowaniu błędnych punktów podczas postojów.
Po zakonczeniu aktywno ´ | sci u ´ | zytkownik ma do wyboru trzy opcje: ˙

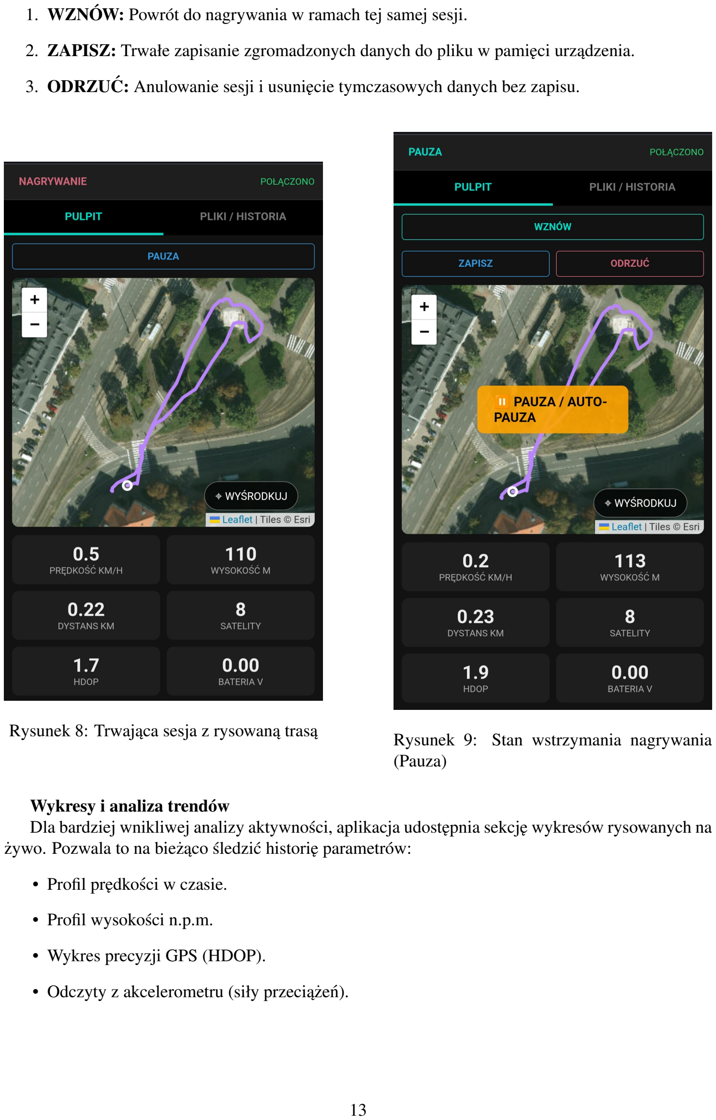
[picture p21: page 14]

1. WZNÓW: Powrót do nagrywania w ramach tej samej sesji.
2. ZAPISZ: Trwałe zapisanie zgromadzonych danych do pliku w pamięci urz ądzenia.
3. ODRZUC: ´ Anulowanie sesji i usunięcie tymczasowych danych bez zapisu.
Rysunek 8: Trwaj ąca sesja z rysowan ą tras ą | Rysunek 9: Stan wstrzymania nagrywania

(Pauza)

Wykresy i analiza trendów
Dla bardziej wnikliwej analizy aktywnosci, aplikacja udostępnia sekcję wykresów rysowanych na ´
zywo. Pozwala to na bie ˙ | z ąco ˙ | sledzi ´ | c historię parametrów: ´
- Profil prędkosci w czasie. ´
- Profil wysokosci n.p.m. ´
- Wykres precyzji GPS (HDOP).
- Odczyty z akcelerometru (siły przeci ąze˙ n). ´


Rysunek 10: Wykresy parametrów telemetrycznych

### 4.1.2 Zarz ądzanie plikami i historia tras

Druga zakładka interfejsu, "PLIKI / HISTORIA", dedykowana jest zarz ądzaniu danymi zgromad-
zonymi na karcie SD. Uzytkownik otrzymuje pełn ą kontrolę nad archiwum tras bez konieczno ˙ | sci ´
wyjmowania karty z urz ądzenia.
Dostępne funkcjonalnosci obejmuj ą: ´
- Odswie ´ | zanie listy: ˙ | Pobranie aktualnego wykazu plików z karty SD.
- Pobieranie: Transfer wybranego pliku .csv/.txt bezposrednio do pamięci telefonu/komputera. ´
- Usuwanie: Trwałe usunięcie niepotrzebnych plików.
- Podgl ąd: Specjalny tryb wizualizacji archiwalnej sesji.


Rysunek 11: Lista zapisanych plików

W trybie podgl ądu pliku interfejs prezentuje kompletny slad trasy na mapie oraz rozszerzony ´ zestaw statystyk, niedostępnych w trybie na zywo, takich jak: ˙

- Srednia prędko ´ | sć:´ Wartosć wyliczona dla całej trasy, z uwzględnieniem postojów (auto- ´
pauza).
- Suma wzniosów i spadków: Ł ączna róznica wysoko ˙ | sci pokonana podczas sesji. ´
- Maksymalna wysokosć:´ Najwyzszy punkt osiagnięty na trasie (max AMSL). ˙
- Dystans: Całkowita długosć trasy. ´
- Srednie HDOP: ´ | Srednia warto ´ | sć precyzji pomiaru z całego zapisu, pozwalaj ąca oceni ´ | c wiary- ´
godnosć danych. ´


Rysunek 12: Tryb podgl ądu historii z dodatkowymi parametrami

Dodatkowo, w trybie podgl ądu uzytkownik ma dostęp do szczegółowych wykresów analizuj ących ˙
przebieg całej trasy. S ą to te same wykresy co w trybie na zywo (prędko ˙ | sć, wysoko ´ | sć, HDOP), ale ´
przedstawiaj ące kompletne dane z całego nagrania, co pozwala na łatw ą identyfikację kluczowych momentów wycieczki.


Rysunek 13: Szczegółowa analiza wykresów w trybie przegl ądania historii

Dane zapisywane s ą na karcie SD w formacie CSV (Comma Separated Values), co umozliwia ˙ ich łatwy import do arkuszy kalkulacyjnych (np. Excel) lub specjalistycznego oprogramowania GIS. Kazda linia w pliku odpowiada jednemu punktowi pomiarowemu i zawiera następuj ące pola, odd- ˙ zielone przecinkami:

- Czas (ms): Czas systemowy w milisekundach od uruchomienia urz ądzenia.
- Szerokosć i Długo ´ | sć geograficzna: ´ | Współrzędne GPS (format dziesiętny).
- Prędkosć (km/h): ´ | Chwilowa prędkosć ruchu. ´
- Wysokosć (m n.p.m.): ´ | Wysokosć nad poziomem morza. ´
- HDOP: Precyzja pomiaru poziomego (im mniejsza wartosć, tym lepiej). ´
- Satelity: Liczba widocznych satelitów uzytych do ustalenia pozycji. ˙
- Akcelerometr (ax, ay, az): Surowe dane z czujnika przeci ąze˙ n dla trzech osi. ´
- Bateria (V): Napięcie zasilania w momencie pomiaru.

Przykładowa struktura linii danych:

millis,lat,lon,speed,alt,hdop,sats,ax,ay,az,batt 34500,52.2297,21.0122,15.5,112.4,1.2,8,0.02,-0.98,0.15,4.12

Integracja z wyswietlaczem OLED ´
Niezaleznie od aplikacji mobilnej, urz ądzenie wyposa ˙ | zone jest w fizyczny ekran OLED. Pełni on ˙
funkcję pomocnicz ą, prezentuj ąc najwazniejsze informacje w zwięzłej formie: ˙
- Aktualny status: Oczekiwanie / Nagrywanie / Pauza.
- Liczba widocznych satelitów (ikona "SAT").
- Biez ąca prędko ˙ | sć oraz przebyty dystans. ´
- Adres IP oraz nazwa sieci WiFi (SSID) w celu ułatwienia poł ączenia.

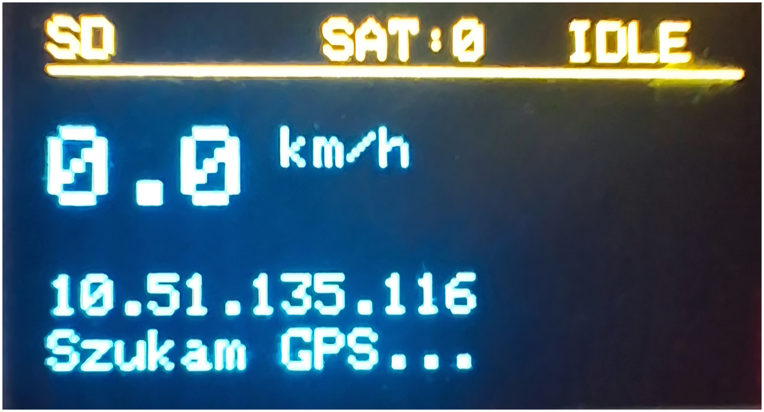
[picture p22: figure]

Rysunek 14: Przykładowy wygl ąd ekranu OLED prezentuj ący status urz ądzenia

### 4.2 Szczegóły techniczne implementacji

Architektura wielow ątkowa
Oprogramowanie zostało zrealizowane w srodowisku PlatformIO (C++) na układzie ESP32, który ´ posiada dwa rdzenie. Pozwoliło to na podział zadan:´
- Rdzen 0 (Komunikacyjny): ´ | Obsługuje WiFi i serwer strony internetowej. Dzięki temu, gdy
uzytkownik przegl ąda mapę na telefonie, nie obci ą ˙ | za to głównego procesu zapisu. ˙
- Rdzen 1 (Logiczny): ´ | Zajmuje się tylko tym, co najwazniejsze - odbieraniem danych z GPS i ˙
zapisywaniem ich na kartę.
Bezpieczenstwo i wielozadaniowo ´ | sć (Mutex) ´
Aby dwa rdzenie nie próbowały jednoczesnie pisa ´ | c na tę sam ą kartę SD (co mogłoby j ą ´
uszkodzic), zastosowano mechanizm Mutex. Działa on jak cyfrowy "klucz" - tylko jeden proces ´
moze mie ˙ | c do niego dostęp w danym momencie. Je ´ | sli WiFi chce odczyta ´ | c plik, musi poczeka ´ | c, a ´ z˙
GPS skonczy zapamiętywa ´ | c pozycję. ´

Logika sterowania (Maszyna Stanów)
System działa w trzech, sci ´ sle okre ´ | slonych trybach, co zapobiega błędom: ´
- IDLE (Czuwanie): Urz ądzenie działa i pokazuje dane, ale nie zapisuje plików.

- RECORDING (Nagrywanie): Główny tryb wycieczkowy - dane s ą zapisywane na kartę.
- PAUSED (Pauza): Wstrzymanie zapisu. Wazne jest to, ˙ | ze przej ˙ | scie w tryb pauzy wymusza ´
"zrzut" (Flush) wszystkich danych na kartę, więc nagłe wył ączenie urz ądzenia nie spowoduje utraty ostatniego fragmentu trasy.

Interfejs WWW (SPA)
Strona internetowa ładuje się z pamięci urz ądzenia tylko raz. Potem telefon pobiera w tle juz tylko ˙ same liczby (prędkosć, pozycję). Dzięki temu interfejs działa płynnie nawet na słabszym zasięgu, a ´ bateria trackera jest oszczędzana.

Bezpieczenstwo Zapisu ´
Dane zbierane s ą w pamięci RAM, a na kartę SD zrzucane s ą w większych paczkach co 10 sekund. Chroni to kartę przed zuzyciem, a nazwy plików tworzone s ą automatycznie z daty i godziny. ˙

Stabilnosć i Watchdog ´
System ignoruje "pływanie" GPS na postoju (Filtr Histerezowy). Dodatkowo, funkcja "Watchdog" restertuje moduł WiFi w razie problemów z poł ączeniem, nie przerywaj ąc przy tym nagrywania trasy.

## 5 Testy i analiza wyników

W celu weryfikacji załoze˙ n projektowych przeprowadzono serię testów sprawdzaj ących nieza- ´ wodnosć urz ądzenia w warunkach rzeczywistych. Skupiono się na trzech krytycznych aspektach: ´
czasie akwizycji sygnału GPS, odpornosci na błędy zapisu oraz wydajno ´ | sci energetycznej. ´

### 5.1 Testy modułu GPS (Cold Start vs Hot Start)

Jednym z kluczowych parametrów uzytkowych lokalizatora jest czas oczekiwania na ustale- ˙ nie pierwszej pozycji (Time To First Fix - TTFF). Procedura testowa obejmowała uruchomienie
urz ądzenia w otwartej przestrzeni po długim okresie nieaktywnosci (powy ´ | zej 4 godzin). ˙
- Cold Start (Zimny start): Moduł uruchamia się "na slepo" - nie wie, gdzie się znajduje, ani ´
gdzie na niebie szukac satelitów. Musi dopiero pobra ´ | c te dane z sygnału GPS. aobserwowane ´
czasy oczekiwania wynosiły od 1 do 5 minut.
- Hot Start: Po krótkim zaniku zasilania (ponizej 30 minut) moduł odzyskuje fix niemal natych- ˙
miastowo (zazwyczaj ponizej 5 sekund), co potwierdza poprawno ˙ | sć działania układu zasilania. ´

Jak wskazuj ą badania porównawcze [13], moduł NEO-6M, mimo bycia rozwi ązaniem budze- ˙
towym, oferuje dokładnosć porównywaln ą do dro ´ | zszych sensorów (np. Walksnail WS-M181). ˙
Głównymi wadami wymienianymi w literaturze, a potwierdzonymi w niniejszym projekcie, s ą długi
czas zimnego startu (wyszukiwania satelitów) oraz nizsza częstotliwo ˙ | sć od ´ | swie ´ | zania. Jednak ˙ | ze, jak ˙
zauwazaj ą autorzy badania, wady te nie s ą krytyczne w typowych zastosowaniach amatorskich i przy ˙ pomiarach w punktach statycznych.

### 5.2 Analiza jakosci ´ sladu w ruchu ´

Testy wykazały, ze o ile w warunkch, gdzie emodoł jest donbrze widoczny urz ądzenie radzi so- ˙ bie bardzo dobrze, to podczas aktywnosci bardziej dynamicznych (np. bieg) lub przy okresowym ´
przesłanianiu anteny, jakosć sygnału zauwa ´ | zalnie spada. ˙

W momentach, gdy antena jest zasłaniana (np. przez ciało biegacza lub gęste korony drzew), na mapie mog ą pojawiac się nieprawdziwe trasy (artefakty), odbiegaj ące od rzeczywistego toru porusza- ´
nia się. Towarzysz ą temu równiez błędne odczyty prędko ˙ | sci chwilowej. Jest to zjawisko wynikaj ące ´
z chwilowej utraty widocznosci satelitów i jest typowe dla odbiorników GPS tej klasy bez wspoma- ´ gania systemami inercyjnymi.

### 5.3 Bilans energetyczny i czas pracy

Urz ądzenie zasilane jest ogniwem Li-Ion 18650 o pojemnosci nominalnej 2600 mAh. Sza- ´ cunkowy pobór pr ądu przez poszczególne moduły:

- ESP32 (z WiFi w trybie AP+STA): ok. 150-200 mA [14]
- Moduł GPS: ok. 40 mA [15]
- OLED i czujniki: ok. 10-15 mA [16]

Ł ączny pobór pr ądu oscyluje w granicach 250 mA. Uwzględniaj ąc sprawnosć przetwornicy Step-Up ´ (ok. 85%), realny czas pracy wynosi:

T ≈

2600mAh
250mA · 0.85 ≈ 8.8h

Jest to wynik satysfakcjonuj ący dla jednodniowej wycieczki rowerowej lub pieszego monitoringu.

## 6 Podsumowanie i wnioski

### 6.1 Wnioski koncowe ´

Przeprowadzone testy i analiza działania prototypu pozwalaj ą na sformułowanie następuj ących wniosków:

1. Stabilnosć działania: ´ | Dzięki wykorzystaniu dwóch rdzeni procesora ESP32, urz ądzenie działa
płynnie. Nagrywanie trasy na kartę odbywa się niezaleznie od obsługi WiFi, więc korzystanie ˙ z podgl ądu na telefonie nie zakłóca zapisu danych.
2. Prosty i szybki interfejs: Strona WWW została napisana tak, aby nie obci ąza˙ c procesora. ´ Telefon pobiera tylko surowe liczby, a nie cał ą grafikę, dzięki czemu aplikacja działa szybko i nie zacina się.
3. Jakosć modułu GPS: ´ | Tani moduł NEO-6M jest wystarczaj ący do turystyki pieszej i za-
stosowan amatorskich. W testach statycznych wykazuje wysok ą precyzję, jednak w dy- ´ namicznym ruchu (bieg) i trudnym terenie (las) jego dokładnosć spada, co jest typowe dla ´ odbiorników bez wspomagania inercyjnego.
4. Efektywnosć energetyczna: ´ | Osi ągnięty czas pracy na poziomie ok. 9 godzin przy zasilaniu
z jednego ogniwa 18650 (z przetwornic ą) czyni urz ądzenie praktycznym w jednodniowych zastosowaniach.
5. Obudowa 3D: Zaprojektowana obudowa jest kompaktowa i funkcjonalna. Chroni elektronikę przed uszkodzeniami mechanicznymi, zapewniaj ąc jednoczesnie łatwy dostęp do portu ładowa- ´ nia i karty pamięci.

### 6.2 Podsumowanie działania

Zrealizowany system działa w pełni poprawnie i spełnił wszystkie załozenia oraz cel pracy. ˙ Urz ądzenie pomyslnie przeszło testy terenowe, rejestruj ąc trasy bez awarii. Projekt udowodnił, ´
ze wykorzystuj ąc tanie i ogólnodostępne moduły (ESP32, NEO-6M), mo ˙ | zna zbudowa ˙ | c narzędzie ´
telemetryczne o funkcjonalnosci zbli ´ | zonej do prostych urz ądze ˙ | n komercyjnych. ´
Dodatkow ą wartosci ą projektu jest jego aspekt edukacyjny. Budowa urz ądzenia wymagała ´ poł ączenia wiedzy z zakresu elektroniki, druku 3D oraz programowania systemów wbudowanych i aplikacji webowych. Powstały prototyp jest nie tylko działaj ącym urz ądzeniem, ale takze solidn ą ˙ platform ą do dalszego rozwoju, np. poprzez dodanie modułu GSM w przyszłosci. ´

## Bibliografia

[1] u-blox AG. NEO-6 u-blox 6 GPS Modules – Data Sheet (GPS.G6-HW-09005). 2011.
[2] Design and Implementation of ESP32-Based Edge Computing for Object Detection. Sensors, vol. 25, no. 6, p. 1656, 2025. DOI: 10.3390/s25061656.
[3] Botland. ESP32 - Co to jest i do czego słuzy? ˙ 2024. [Online]. Dostępne: https://
botland.com.pl/blog/esp32-co-to-jest-i-do-czego-sluzy/
[4] Performance Evaluation of Programming Languages on ESP32 Microcontroller. Electronics, vol. 12, no. 1, p. 143, 2022.
[5] Espressif Systems. ESP32 Technical Reference Manual. 2024. [Online]. Dostępne:
https://www.espressif.com/sites/default/files/documentation/esp32_technical_reference_manual_en.pdf (https://www.espressif.com/sites/default/files/documentation/esp32_technical_reference_manual_en.pdf)
[6] MSalamon.pl. ESP32 od Podstaw – Przegl ąd Rodzin Układów i Ich Najwazniejszych ˙ Cech. 2025. [Online]. Dostępne: https://sklep.msalamon.pl/blog/esp32-od-
podstaw-przeglad-rodzin-ukladow-i-ich-najwazniejszych-cech/ (https://sklep.msalamon.pl/blog/esp32-od-podstaw-przeglad-rodzin-ukladow-i-ich-najwazniejszych-cech/)
[7] Wikipedia. NMEA 0183 – Wikipedia, wolna encyklopedia. 2005. [Online]. Dostępne: https:
//pl.wikipedia.org/wiki/NMEA_0183
[8] Elektro-Praktyk. System nawigacji satelitarnej GPS, częsć 8 – Protokół NMEA-0183 ´ | . 2013.
[9] Geoforum.pl. Uniwersalny język nawigacji – Standard NMEA-0183 w odbiornikach GPS. (b.d.).
[10] Elektro-Praktyk. UART na SPI/I2C – Zestawienie cech i parametrów mostków komunikacyjnych. 2013.
[11] WonderfulPCB. Wybór własciwego protokołu komunikacyjnego: | I2C, SPI lub UART ´ | .
2025. | [Online]. | Dostępne: | https://www.wonderfulpcb.com/pl/blog/i2c-
communication-protocol-vs-spi-vs-uart-comparison-guide/ (https://www.wonderfulpcb.com/pl/blog/i2c-communication-protocol-vs-spi-vs-uart-comparison-guide/)
[12] OurPCB. I2C vs SPI: Róznice, które powiniene ˙ | s znać ´ | . (b.d.). [Online]. Dostępne: https://
ourpcb.pl/i2c-vs-spi.html
[13] Comparative Experimental Evaluation of the Error of GPS Modules. Automatic Control and Power Systems, vol. 10, no. 2, 2025. [Online]. Dostępne: https:
//science.lpnu.ua/acps/all-volumes-and-issues/volume-10-number-2-2025/comparative-experimental-evaluation-error-gps (https://science.lpnu.ua/acps/all-volumes-and-issues/volume-10-number-2-2025/comparative-experimental-evaluation-error-gps)
[14] DeepBlueEmbedded. ESP32 Sleep Modes & Power Consumption. (b.d.). [Online].
Dostępne: | https://deepbluembedded.com/esp32-sleep-modes-power-
consumption-in-each-mode/ (https://deepbluembedded.com/esp32-sleep-modes-power-consumption-in-each-mode/)
[15] Robotics Bangladesh. GPS Module NEO-6M Satellite Positioning Module. (b.d.). [On-
line]. Dostępne: https://roboticsbd.com/electronics-module/2397-gpsmodule-neo-6m-satellite-positioning-module-for-arduino-withmicrousb-robotics-bangladesh-roboticsbd-745.html (https://roboticsbd.com/electronics-module/2397-gps-module-neo-6m-satellite-positioning-module-for-arduino-with-microusb-robotics-bangladesh-roboticsbd-745.html)
[16] BitBank Software. How much current do OLED displays use?. 2019. [Online]. Dostępne:
https://bitbanksoftware.blogspot.com/2019/06/how-much-currentdo-oled-displays-use.html (https://bitbanksoftware.blogspot.com/2019/06/how-much-current-do-oled-displays-use.html)

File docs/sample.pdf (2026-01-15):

## Projekt i realizacja autonomicznego rejestratora parametrów ruchu GPS z interfejsem bezprzewodowym opartym o ukªad ESP32

### Paweª

### January 9, 2026

## Contents

1 Wst¦p | 2
2 Projekt sprz¦towy | 2
3 Przegl¡d technologii i narz¦dzi | 6
4 Implementacja oprogramowania | 8
5 Testy i analiza wyników | 16
6 Podsumowanie i wnioski | 17

## 1 Wst¦p

Rozwój technologii Internetu Rzeczy (IoT Internet of Things) pozwoliª na zmniejszenie systemów telemetrycznych. Jeszcze dziesi¦¢ lat temu potrzebna byªa du»a infrastruktura sprz¦towa. Celem tej pracy jest zaprojektowanie i zbudowanie urz¡dzenia typu GPS Tracker". Urz¡dzenie ma rejestrowa¢ tras¦, monitorowa¢ parametry ruchu i pokazywa¢ dane w czasie rzeczywistym.
Gªównym zaªo»eniem projektu byªo stworzenie systemu autonomicznego, zasilanego bateryjnie, który ª¡czy w sobie funkcjonalno±¢ klasycznego rejestratora danych (tzw. "czarnej skrzynki") z nowoczesnym interfejsem u»ytkownika dost¦pnym przez przegl¡dark¦ internetow¡ (Web Interface).

### 1.1 Koncepcja architektury systemu telemetrycznego

Najwi¦kszy problem przy tworzeniu przeno±nych rejestratorów danych to znalezienie balansu mi¦dzy siª¡ oblicze« a zu»yciem pr¡du. Stare, proste rejestratory danych tylko zapisuj¡ dane i nic wi¦cej nie robi¡. Natomiast nowe rozwi¡zania IoT chc¡ przetwarza¢ dane tam, gdzie je zbieraj¡, i nie potrzebuj¡ zewn¦trznych serwerów. Z mojego do±wiadczenia widz¦, »e ten balans decyduje o tym, czy rejestrator b¦dzie dziaªaª dªugo i dobrze.
W niniejszym projekcie przyj¦to zaªo»enie, »e urz¡dzenie nie tylko gromadzi surowe dane pomiarowe, ale dziaªa jako niezale»ny serwera aplikacj i udost¦pnia peªny graczny interfejs. To wymusiªo rezygnacj¦ z prostych mikrokontrolerów 8-bitowych na rzecz wydajniejszych jednostek obliczeniowych, ª¡cz¡cych wiele funkcji (w tym bezprzewodow¡ ª¡czno±¢) w jednym ukªadzie scalonym.
Do realizacji zadania wybrano platform¦ ESP32, kieruj¡c si¦ jej unikaln¡ architektur¡ dwurdzeniow¡. Pozwala ona na separacj¦ procesów krytycznych (obsªuga przerwa« GPS i IMU) od obsªugi stosu sieciowego WiFi, co jest wa»ne, »eby dane byªy zapisywane ci¡gle. Dodatkowo, wysoki stopie« integracji w jednym ukªadzie pozwoliª zminimalizowa¢ wymiary urz¡dzenia oraz upro±ci¢ ukªad oraz obni»y¢ cene

## 2 Projekt sprz¦towy

Warstwa sprz¦towa urz¡dzenia zostaªa zaprojektowana w sposób moduªowy, co uªatwia diagnostyk¦ oraz ewentualn¡ wymian¦ komponentów. System skªada si¦ z nast¦puj¡cych komponentów:

### 2.1 Elementy ukªadu

Mikrokontroler: ESP32 DevKit V1 WROOM-32 dwurdzeniowy procesor z WiFi i
| Bluetooth

Moduª GPS: NEO-6M V2 odbiornik satelitarny (komunikacja UART)

IMU (czujnik ruchu): MPU6050 akcelerometr i »yroskop 6-osiowy (I2C)

Wy±wietlacz: OLED 0.96" monochromatyczny ekran 128x64 px (I2C)

Pami¦¢ masowa: Micro SD Card Module czytnik kart MicroSD (SPI)

Zasilanie: adowarka Li-Ion z wej±ciem USB-C i zabezpieczeniami, wspóªpracuj¡ca z
| ogniwem 18650. Ukªad umo»liwia ªadowanie baterii lub zasilanie systemu bezpo±rednio z portu USB.

### 2.2 Konguracja interfejsów i poª¡cze«

Wszystkie moduªy peryferyjne zostaªy poª¡czone z mikrokontrolerem zgodnie z zaª¡czonym schematem elektrycznym. Kluczowym wymogiem poprawno±ci dziaªania ukªadu jest poª¡czenie wszystkich mas (GND) w jeden wspólny potencjaª.


Figure 1: Schemat elektryczny systemu

Magistrala I2C (OLED + MPU6050): Urz¡dzenia podª¡czone równolegle do wspólnych linii SDA i SCL.

Urz¡dzenie | Pin Moduªu | Pin ESP32 | Uwagi
OLED 0.96" | SDA SCL VCC GND | GPIO 21 GPIO 22 3.3V GND | Adres I2C: 0x3C Z pinu 3V3 ESP32 Wspólna masa
MPU6050 (IMU) | SDA SCL VCC GND | GPIO 21 GPIO 22 5V GND | Adres I2C: 0x68 Z pinu 5V OUT power module Wspólna masa

Table 1: Konguracja magistrali I2C

Moduª GPS NEO-6M V2 (UART): Wykorzystuje sprz¦towy port szeregowy UART2.

Pin Moduªu GPS | Pin ESP32 | Funkcja
TX RX VCC GND | GPIO 16 (RX2) GPIO 17 (TX2) 3.3V GND | Transmisja z GPS do ESP32 Konguracja GPS (opcjonalna) Z pinu 3V3 ESP32 Wspólna masa

Table 2: Poª¡czenie moduªu GPS

Micro SD Card Module (SPI): Wykorzystuje standardow¡ magistral¦ VSPI.

Pin Moduªu SD | Pin ESP32 | Funkcja
CS SCK MISO MOSI VCC GND | GPIO 5 GPIO 18 GPIO 19 GPIO 23 3.3V GND | Chip Select Zegar synchronizacji Dane (Master In, Slave Out) Dane (Master Out, Slave In) Z pinu 3V3 ESP32 Wspólna masa

Table 3: Poª¡czenie czytnika kart SD

### 2.3 Projekt obudowy

Obudowa zostaªa zaprojektowana w Autodesk Inventor z przeznaczeniem do druku 3D. Skªada si¦ z podstawy, ramki monta»owej i pokrywy z wzorem plastra miodu. Podstawa zawiera komory na poszczególne moduªy oraz schowek na ogniwo 18650. Ramka dystansowa tworzy okno dost¦pu do ekranu i GPS. Pokrywa z a»urowym wzorem zapewnia podglad wnetrza ukªadu.

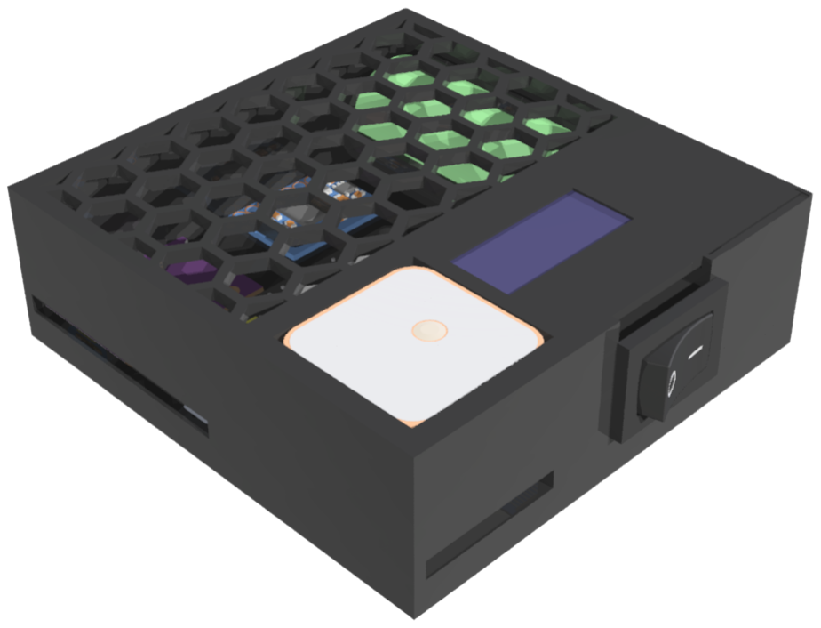
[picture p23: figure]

Figure 2: Widok zªo»onej obudowy

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

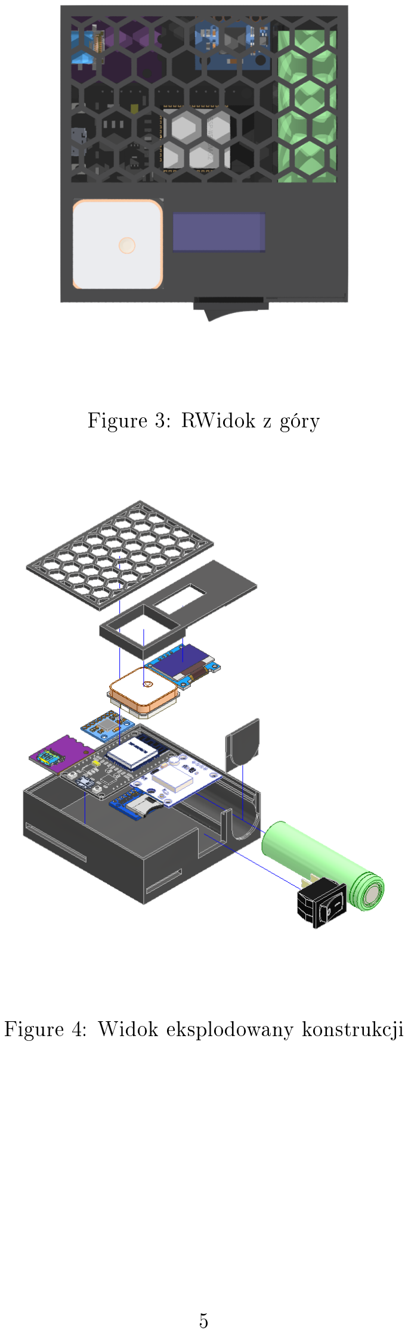
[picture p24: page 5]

## 3 Przegl¡d technologii i narz¦dzi

Budowa trackera GPS wymaga poª¡czenia kilku ró»nych technologii komunikacyjnych. Poni»ej opisano kluczowe elementy systemu wykorzystane w projekcie.

### 3.1 Rozwój IoT i miniaturyzacja

Internet Rzeczy (IoT) to ±wiat poª¡czonych urz¡dze« od zegarków, przez czujniki temperatury, a» po inteligentne zamki [3, 6]. Miniaturyzacja, czyli proces zmniejszania rozmiarów komponentów elektronicznych, umo»liwiªa budow¦ tak maªych i wydajnych urz¡dze«.
Moduª odbiornika GPS NEO-6M ma wymiary zaledwie 16 Ö 12,2 Ö 2,4 mm [1], co pozwala zbudowa¢ kompaktowy tracker. Mniejsze ukªady zu»ywaj¡ te» znacznie mniej energii urz¡dzenie mo»e pracowa¢ na baterii przez wiele godzin lub dni. Integracja wielu funkcji w jednym ukªadzie (System on Chip, w skrócie SoC) obni»a koszty produkcji i zwi¦ksza niezawodno±¢ systemu.

### 3.2 Telemetria i przetwarzanie danych

Telemetria to technologia zbierania danych z odlegªych miejsc i przesyªania ich w czasie rzeczywistym. W przypadku trackera GPS oznacza to automatyczne odczytywanie pozycji i pr¦dko±ci bez potrzeby zycznego dost¦pu do urz¡dzenia.
Przetwarzanie na miejscu (Edge Computing) to koncepcja, w której dane nie s¡ od razu wysyªane do internetu, ale wst¦pnie analizowane bezpo±rednio w urz¡dzeniu [2]. Mikrokontroler ESP32 odbiera surowe dane z moduªu GPS, przetwarza je rozpoznaje wspóªrz¦dne, oblicza pr¦dko±¢ i zapisuje gotowe wyniki na karcie pami¦ci.
Dlaczego to wa»ne? Po pierwsze, oszcz¦dza to energi¦ baterii zamiast ci¡gle wysyªa¢ dane przez sie¢ (co zu»ywa du»o pr¡du), urz¡dzenie analizuje je lokalnie i wysyªa tylko niezb¦dne informacje. Po drugie, zwi¦ksza to szybko±¢ reakcji decyzje podejmowane s¡ natychmiast, bez czekania na odpowied¹ z serwera.

### 3.3 Architektura ESP32

ESP32 to mikrokontroler rmy Espressif Systems, który posiada dwa niezale»ne rdzenie procesora Xtensa LX6 pracuj¡ce z cz¦stotliwo±ci¡ do 240 MHz [5, 6]. W praktyce oznacza to, »e mo»e wykonywa¢ dwa zadania jednocze±nie, bez wzajemnego spowalniania si¦.
Jak to dziaªa? Jeden rdze« mo»e zajmowa¢ si¦ obliczeniami odbieraniem danych GPS, zapisywaniem ich na kart¦ pami¦ci, wy±wietlaniem informacji na ekranie [4]. W tym samym czasie drugi rdze« obsªuguje komunikacj¦ bezprzewodow¡ Wi-Fi lub Bluetooth. Dzi¦ki temu oba procesy dziaªaj¡ pªynnie i nie przeszkadzaj¡ sobie nawzajem.
ESP32 posiada tak»e wbudowane moduªy Wi-Fi i Bluetooth, co czyni go idealnym rozwi¡zaniem dla projektów wymagaj¡cych bezprzewodowej komunikacji [3]. Dodatkowo, ukªad obsªuguje zaawansowane tryby oszcz¦dzania energii mo»e automatycznie "zasypia¢" gdy nie wykonuje zada«, pobieraj¡c mniej ni» 10 mikroamperów pr¡du.

### 3.4 System GNSS i protokóª NMEA 0183

Odbiornik GPS komunikuje si¦ z mikrokontrolerem za pomoc¡ protokoªu NMEA 0183 standardu opracowanego przez National Marine Electronics Association, u»ywanego w nawigacji morskiej i l¡dowej [7, 9]. Jest to protokóª tekstowy, w którym dane przesyªane s¡ w postaci czytelnych dla czªowieka zda« ASCII.

Moduª u-blox NEO-6M wysyªa dane przez port szeregowy z pr¦dko±ci¡ 9600 bitów na sekund¦ [1]. Dane te maj¡ posta¢ tekstowych linii rozpoczynaj¡cych si¦ od znaku dolara ($), zawieraj¡cych kod identykacyjny oraz pola oddzielone przecinkami.
Najwa»niejsze typy ramek wykorzystywane w projekcie to:

$GPGGA zawiera podstawowe dane o pozycji: szeroko±¢ geograczn¡, dªugo±¢ geograczn¡, wysoko±¢ nad poziomem morza oraz liczb¦ widocznych satelitów. To te informacje, które odpowiadaj¡ na pytanie "gdzie jestem?" [8].

$GPRMC dostarcza dane o ruchu: pr¦dko±¢ przemieszczania si¦ oraz kierunek jazdy (kurs). Dzi¦ki tym danym mo»na wy±wietli¢ strzaªk¦ wskazuj¡c¡ kierunek poruszania si¦.

ESP32 posiada sprz¦towe porty UART, które automatycznie odbieraj¡ dane w tle [5]. Oznacza to, »e procesor nie musi ci¡gle sprawdza¢, czy nadeszªy nowe dane specjalny ukªad UART robi to automatycznie i informuje procesor, gdy caªa ramka zostaªa odebrana. To znacznie odci¡»a gªówny procesor i zapewnia stabilno±¢ dziaªania.

### 3.5 Magistrale komunikacyjne w systemach wbudowanych

W projekcie wykorzystano trzy ró»ne standardy komunikacji, ka»dy wybrany do konkretnego zadania:
I2C (Inter-Integrated Circuit) to magistrala, która wykorzystuje tylko dwa przewody: jeden do przesyªania danych (SDA), drugi do synchronizacji czasowej (SCL) [11]. Najwi¦ksz¡ zalet¡ I2C jest mo»liwo±¢ podª¡czenia wielu urz¡dze« do tych samych dwóch przewodów ka»de urz¡dzenie ma swój unikalny adres i reaguje tylko na komunikaty skierowane do niego.
W trackerze na jednej magistrali I2C pracuj¡ jednocze±nie wy±wietlacz OLED oraz czujnik ruchu IMU. Mikrokontroler rozró»nia je po adresach. I2C jest idealne dla urz¡dze« znajduj¡cych si¦ blisko siebie, które nie wymagaj¡ bardzo szybkiego przesyªu danych typowa pr¦dko±¢ to do 400 tysi¦cy bitów na sekund¦, co w zupeªno±ci wystarcza dla wy±wietlaczy i czujników [12].

SPI (Serial Peripheral Interface) to magistrala synchroniczna zaprojektowana do szybkiego przesyªu danych. Wykorzystuje cztery linie komunikacyjne i mo»e przesyªa¢ dane jednocze±nie w obu kierunkach (tzw. komunikacja dwukierunkowa) [11].
SPI zostaªo wybrane do obsªugi karty pami¦ci SD, poniewa» zapis danych wymaga szybkiego transferu karta SD mo»e przyjmowa¢ dane z pr¦dko±ci¡ kilku do kilkudziesi¦ciu megabitów na sekund¦ [12]. To znacznie szybciej ni» I2C, dlatego dla karty pami¦ci jest to najlepszy wybór.

UART (Universal Asynchronous Receiver-Transmitter) to port szeregowy wykorzystuj¡cy dwa przewody: jeden do wysyªania danych (TX), drugi do odbierania (RX) [10]. Komunikacja odbywa si¦ bez wspólnej linii zegarowej oba urz¡dzenia musz¡ by¢ po prostu skongurowane na t¦ sam¡ pr¦dko±¢ transmisji.
W projekcie UART obsªuguje moduª GPS. ESP32 posiada sprz¦towe porty UART, co oznacza, »e odbiór danych odbywa si¦ automatycznie przez dedykowany ukªad elektroniczny [5]. Procesor nie musi ci¡gle sprawdza¢, czy nadeszªy nowe dane ukªad sam go powiadomi. To zapewnia stabilno±¢ odbioru danych nawet przy intensywnej pracy procesora.
UART jest prosty, niezawodny i dziaªa nawet na wi¦kszych odlegªo±ciach (przy odpowiednio ni»szych pr¦dko±ciach). Jest idealny dla urz¡dze«, które wymagaj¡ prostego, dwukierunkowego poª¡czenia mi¦dzy dwoma urz¡dzeniami.

## 4 Implementacja oprogramowania

### 4.1 Opis funkcjonalno±ci i obsªuga aplikacji

Aplikacja webowa stanowi gªówne centrum sterowania urz¡dzeniem. Poni»ej przedstawiono szczegóªowy opis interfejsu oraz dost¦pnych funkcji, które zostaªy zaimplementowane w celu zapewnienia intuicyjnej obsªugi.

4.1.1 Ekran gªówny i parametry na »ywo

Po nawi¡zaniu poª¡czenia z sieci¡ Wi-Fi urz¡dzenia, w prawym górnym rogu aplikacji widoczny jest status "POCZONO". W przypadku utraty zasi¦gu lub zerwania poª¡czenia, komunikat natychmiast zmienia si¦ na "ROZCZONO", informuj¡c u»ytkownika o braku aktualnej synchronizacji danych.
Ekran gªówny zostaª podzielony na dwie sekcje logiczne: map¦ z aktualn¡ pozycj¡ (wykorzystuj¡c¡ bibliotek¦ Leaet) oraz panel parametrów telemetrycznych.
Na panelu dolnym wy±wietlane s¡ kluczowe parametry od±wie»ane w czasie rzeczywistym:

Pr¦dko±¢: Aktualna pr¦dko±¢ przemieszczania si¦ wyra»ona w km/h.

Wysoko±¢: Wysoko±¢ nad poziomem morza w metrach.

Dystans: Caªkowita dªugo±¢ trasy przebyta w bie»¡cej sesji.

Satelity: Liczba widocznych i u»ywanych do nawigacji satelitów, co pozwala oceni¢
| jako±¢ "xa".

HDOP: Parametr precyzji geometrycznej (im ni»szy, tym lepiej).

Bateria: Napi¦cie ogniwa zasilaj¡cego, pozwalaj¡ce monitorowa¢ stan naªadowania.

W sytuacji, gdy urz¡dzenie nie posiada jeszcze ustalonej pozycji GPS (np. zaraz po wª¡czeniu wewn¡trz budynku), na ekranie widnieje wyra¹ny komunikat o szukaniu sygnaªu GPS.


Figure 5: Ekran startowy aplikacji - system gotowy do pracy

Proces nagrywania trasy
Sterowanie procesem rejestracji odbywa si¦ za pomoc¡ centralnego przycisku "START". Rozpocz¦cie nagrywania aktywuje rysowanie ±ladu na mapie oraz zliczanie statystyk sesji. Aplikacja udost¦pnia równie» funkcj¦ centrowania mapy specjalny przycisk pozwala jednym klikni¦ciem przywróci¢ widok na aktualn¡ pozycj¦ GPS, co jest przydatne po r¦cznym przesuwaniu mapy w celu podejrzenia okolicy.
System obsªuguje zaawansowane funkcje pauzowania:

Pauza manualna: U»ytkownik mo»e w ka»dej chwili r¦cznie wstrzyma¢ zapis przyciskiem "PAUZA".

Auto-Pauza: System automatycznie wykrywa brak ruchu i wstrzymuje zapis, co jest sygnalizowane pomara«czowym komunikatem "PAUZA / AUTO-PAUZA" na mapie. Zapobiega to rejestrowaniu bª¦dnych punktów podczas postojów.

Po zako«czeniu aktywno±ci u»ytkownik ma do wyboru trzy opcje:

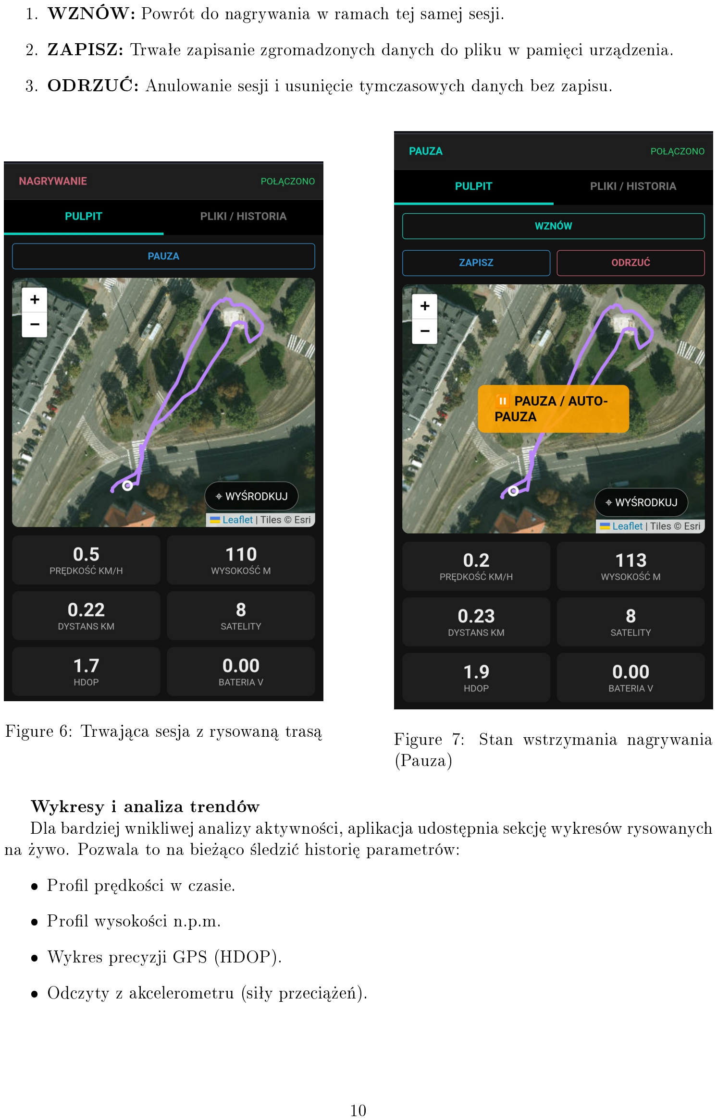
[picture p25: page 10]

1. WZNÓW: Powrót do nagrywania w ramach tej samej sesji.
2. ZAPISZ: Trwaªe zapisanie zgromadzonych danych do pliku w pami¦ci urz¡dzenia.
3. ODRZU: Anulowanie sesji i usuni¦cie tymczasowych danych bez zapisu.
Figure 6: Trwaj¡ca sesja z rysowan¡ tras¡ | Figure 7: Stan wstrzymania nagrywania
| (Pauza)

Wykresy i analiza trendów
Dla bardziej wnikliwej analizy aktywno±ci, aplikacja udost¦pnia sekcj¦ wykresów rysowanych na »ywo. Pozwala to na bie»¡co ±ledzi¢ histori¦ parametrów:

Prol pr¦dko±ci w czasie.

Prol wysoko±ci n.p.m.

Wykres precyzji GPS (HDOP).

Odczyty z akcelerometru (siªy przeci¡»e«).


Figure 8: Wykresy parametrów telemetrycznych

4.1.2 Zarz¡dzanie plikami i historia tras

Druga zakªadka interfejsu, "PLIKI / HISTORIA", dedykowana jest zarz¡dzaniu danymi zgromadzonymi na karcie SD. U»ytkownik otrzymuje peªn¡ kontrol¦ nad archiwum tras bez konieczno±ci wyjmowania karty z urz¡dzenia.
Dost¦pne funkcjonalno±ci obejmuj¡:

Od±wie»anie listy: Pobranie aktualnego wykazu plików z karty SD.

Pobieranie: Transfer wybranego pliku .csv/.txt bezpo±rednio do pami¦ci telefonu/komputera.

Usuwanie: Trwaªe usuni¦cie niepotrzebnych plików.

Podgl¡d: Specjalny tryb wizualizacji archiwalnej sesji.


Figure 9: Lista zapisanych plików

W trybie podgl¡du pliku interfejs prezentuje kompletny ±lad trasy na mapie oraz rozszerzony zestaw statystyk, niedost¦pnych w trybie na »ywo, takich jak:

rednia pr¦dko±¢: Warto±¢ wyliczona dla caªej trasy, z uwzgl¦dnieniem postojów (auto-pauza).

Suma wzniosów i spadków: ¡czna ró»nica wysoko±ci pokonana podczas sesji.

Maksymalna wysoko±¢: Najwy»szy punkt osiagni¦ty na trasie (max AMSL).

Dystans: Caªkowita dªugo±¢ trasy.

rednie HDOP: rednia warto±¢ precyzji pomiaru z caªego zapisu, pozwalaj¡ca oceni¢ wiarygodno±¢ danych.


Figure 10: Tryb podgl¡du historii z dodatkowymi parametrami

Dodatkowo, w trybie podgl¡du u»ytkownik ma dost¦p do szczegóªowych wykresów analizuj¡cych przebieg caªej trasy. S¡ to te same wykresy co w trybie na »ywo (pr¦dko±¢, wysoko±¢, HDOP), ale przedstawiaj¡ce kompletne dane z caªego nagrania, co pozwala na ªatw¡ identy-kacj¦ kluczowych momentów wycieczki.


Figure 11: Szczegóªowa analiza wykresów w trybie przegl¡dania historii

Dane zapisywane s¡ na karcie SD w formacie CSV (Comma Separated Values), co umo»liwia ich ªatwy import do arkuszy kalkulacyjnych (np. Excel) lub specjalistycznego oprogramowania GIS. Ka»da linia w pliku odpowiada jednemu punktowi pomiarowemu i zawiera nast¦puj¡ce pola, oddzielone przecinkami:

Czas (ms): Czas systemowy w milisekundach od uruchomienia urz¡dzenia.

Szeroko±¢ i Dªugo±¢ geograczna: Wspóªrz¦dne GPS (format dziesi¦tny).

Pr¦dko±¢ (km/h): Chwilowa pr¦dko±¢ ruchu.

Wysoko±¢ (m n.p.m.): Wysoko±¢ nad poziomem morza.

HDOP: Precyzja pomiaru poziomego (im mniejsza warto±¢, tym lepiej).

Satelity: Liczba widocznych satelitów u»ytych do ustalenia pozycji.

Akcelerometr (ax, ay, az): Surowe dane z czujnika przeci¡»e« dla trzech osi.

Bateria (V): Napi¦cie zasilania w momencie pomiaru.

Przykªadowa struktura linii danych:

millis,lat,lon,speed,alt,hdop,sats,ax,ay,az,batt 34500,52.2297,21.0122,15.5,112.4,1.2,8,0.02,-0.98,0.15,4.12

Integracja z wy±wietlaczem OLED
Niezale»nie od aplikacji mobilnej, urz¡dzenie wyposa»one jest w zyczny ekran OLED. Peªni on funkcj¦ pomocnicz¡, prezentuj¡c najwa»niejsze informacje w zwi¦zªej formie:

Aktualny status: Oczekiwanie / Nagrywanie / Pauza.

Liczba widocznych satelitów (ikona "SAT").

Bie»¡ca pr¦dko±¢ oraz przebyty dystans.

Adres IP oraz nazwa sieci WiFi (SSID) w celu uªatwienia poª¡czenia.


Figure 12: Przykªadowy wygl¡d ekranu OLED prezentuj¡cy status urz¡dzenia

### 4.2 Szczegóªy techniczne implementacji

Architektura wielow¡tkowa
Oprogramowanie zostaªo zrealizowane w ±rodowisku PlatformIO (C++) na ukªadzie ESP32, który posiada dwa rdzenie. Pozwoliªo to na podziaª zada«:

Rdze« 0 (Komunikacyjny): Obsªuguje WiFi i serwer strony internetowej. Dzi¦ki temu,
| gdy u»ytkownik przegl¡da map¦ na telefonie, nie obci¡»a to gªównego procesu zapisu.

Rdze« 1 (Logiczny): Zajmuje si¦ tylko tym, co najwa»niejsze - odbieraniem danych z
| GPS i zapisywaniem ich na kart¦.

Bezpiecze«stwo i wielozadaniowo±¢ (Mutex)
Aby dwa rdzenie nie próbowaªy jednocze±nie pisa¢ na t¦ sam¡ kart¦ SD (co mogªoby j¡ uszkodzi¢), zastosowano mechanizm Mutex. Dziaªa on jak cyfrowy "klucz" - tylko jeden proces mo»e mie¢ do niego dost¦p w danym momencie. Je±li WiFi chce odczyta¢ plik, musi poczeka¢, a» GPS sko«czy zapami¦tywa¢ pozycj¦.

Logika sterowania (Maszyna Stanów)
System dziaªa w trzech, ±ci±le okre±lonych trybach, co zapobiega bª¦dom:

IDLE (Czuwanie): Urz¡dzenie dziaªa i pokazuje dane, ale nie zapisuje plików.

RECORDING (Nagrywanie): Gªówny tryb wycieczkowy - dane s¡ zapisywane na kart¦.

PAUSED (Pauza): Wstrzymanie zapisu. Wa»ne jest to, »e przej±cie w tryb pauzy wymusza "zrzut" (Flush) wszystkich danych na kart¦, wi¦c nagªe wyª¡czenie urz¡dzenia nie spowoduje utraty ostatniego fragmentu trasy.

Interfejs WWW (SPA)
Strona internetowa ªaduje si¦ z pami¦ci urz¡dzenia tylko raz. Potem telefon pobiera w tle ju» tylko same liczby (pr¦dko±¢, pozycj¦). Dzi¦ki temu interfejs dziaªa pªynnie nawet na sªabszym zasi¦gu, a bateria trackera jest oszcz¦dzana.

Bezpiecze«stwo Zapisu
Dane zbierane s¡ w pami¦ci RAM, a na kart¦ SD zrzucane s¡ w wi¦kszych paczkach co 10 sekund. Chroni to kart¦ przed zu»yciem, a nazwy plików tworzone s¡ automatycznie z daty i godziny.

Stabilno±¢ i Watchdog
System ignoruje "pªywanie" GPS na postoju (Filtr Histerezowy). Dodatkowo, funkcja "Watchdog" restertuje moduª WiFi w razie problemów z poª¡czeniem, nie przerywaj¡c przy tym nagrywania trasy.

## 5 Testy i analiza wyników

W celu werykacji zaªo»e« projektowych przeprowadzono seri¦ testów sprawdzaj¡cych niezawodno±¢ urz¡dzenia w warunkach rzeczywistych. Skupiono si¦ na trzech krytycznych aspektach: czasie akwizycji sygnaªu GPS, odporno±ci na bª¦dy zapisu oraz wydajno±ci energetycznej.

### 5.1 Testy moduªu GPS (Cold Start vs Hot Start)

Jednym z kluczowych parametrów u»ytkowych lokalizatora jest czas oczekiwania na ustalenie pierwszej pozycji (Time To First Fix - TTFF). Procedura testowa obejmowaªa uruchomienie urz¡dzenia w otwartej przestrzeni po dªugim okresie nieaktywno±ci (powy»ej 4 godzin).

Cold Start (Zimny start): Moduª uruchamia si¦ "na ±lepo" - nie wie, gdzie si¦ znaj-
| duje, ani gdzie na niebie szuka¢ satelitów. Musi dopiero pobra¢ te dane z sygnaªu GPS. aobserwowane czasy oczekiwania wynosiªy od 1 do 5 minut.

Hot Start: Po krótkim zaniku zasilania (poni»ej 30 minut) moduª odzyskuje x niemal
| natychmiastowo (zazwyczaj poni»ej 5 sekund), co potwierdza poprawno±¢ dziaªania ukªadu zasilania.

Jak wskazuj¡ badania porównawcze [13], moduª NEO-6M, mimo bycia rozwi¡zaniem bud»etowym, oferuje dokªadno±¢ porównywaln¡ do dro»szych sensorów (np. Walksnail WS-M181). Gªównymi wadami wymienianymi w literaturze, a potwierdzonymi w niniejszym projekcie, s¡ dªugi czas zimnego startu (wyszukiwania satelitów) oraz ni»sza cz¦stotliwo±¢ od±wie»ania. Jednak»e, jak zauwa»aj¡ autorzy badania, wady te nie s¡ krytyczne w typowych zastosowaniach amatorskich i przy pomiarach w punktach statycznych.

### 5.2 Analiza jako±ci ±ladu w ruchu

Testy wykazaªy, »e o ile w warunkach statycznych moduª radzi sobie bardzo dobrze, to podczas aktywno±ci dynamicznych (np. bieg) lub przy okresowym przesªanianiu anteny, jako±¢ sygnaªu zauwa»alnie spada.
W momentach, gdy antena jest zasªaniana (np. przez ciaªo biegacza lub g¦ste korony drzew), na mapie mog¡ pojawia¢ si¦ nieprawdziwe trasy (artefakty), odbiegaj¡ce od rzeczywistego toru poruszania si¦. Towarzysz¡ temu równie» bª¦dne odczyty pr¦dko±ci chwilowej. Jest to zjawisko wynikaj¡ce z chwilowej utraty widoczno±ci satelitów i jest typowe dla odbiorników GPS tej klasy bez wspomagania systemami inercyjnymi.

### 5.3 Bilans energetyczny i czas pracy

Urz¡dzenie zasilane jest ogniwem Li-Ion 18650 o pojemno±ci nominalnej 2600 mAh. Szacunkowy pobór pr¡du przez poszczególne moduªy:
ESP32 (z WiFi w trybie AP+STA): ok. 150-200 mA [14]

Moduª GPS: ok. 40 mA [15]

OLED i czujniki: ok. 10-15 mA [16]

¡czny pobór pr¡du oscyluje w granicach 250 mA. Uwzgl¦dniaj¡c sprawno±¢ przetwornicy Step-Up (ok. 85%), realny czas pracy wynosi:
| T ≈ 2600mAh 250mA · 0.85 ≈ 8.8h

Jest to wynik satysfakcjonuj¡cy dla jednodniowej wycieczki rowerowej lub pieszego monitoringu.

## 6 Podsumowanie i wnioski

### 6.1 Wnioski ko«cowe

Przeprowadzone testy i analiza dziaªania prototypu pozwalaj¡ na sformuªowanie nast¦puj¡-cych wniosków:

1. Stabilno±¢ dziaªania: Dzi¦ki wykorzystaniu dwóch rdzeni procesora ESP32, urz¡dzenie
| dziaªa pªynnie. Nagrywanie trasy na kart¦ odbywa si¦ niezale»nie od obsªugi WiFi, wi¦c korzystanie z podgl¡du na telefonie nie zakªóca zapisu danych.
2. Prosty i szybki interfejs: Strona WWW zostaªa napisana tak, aby nie obci¡»a¢ proce-
| sora. Telefon pobiera tylko surowe liczby, a nie caª¡ grak¦, dzi¦ki czemu aplikacja dziaªa szybko i nie zacina si¦.
3. Jako±¢ moduªu GPS: Tani moduª NEO-6M jest wystarczaj¡cy do turystyki pieszej
| i zastosowa« amatorskich. W testach statycznych wykazuje wysok¡ precyzj¦, jednak w dynamicznym ruchu (bieg) i trudnym terenie (las) jego dokªadno±¢ spada, co jest typowe dla odbiorników bez wspomagania inercyjnego.
4. Efektywno±¢ energetyczna: Osi¡gni¦ty czas pracy na poziomie ok. 9 godzin przy za-
| silaniu z jednego ogniwa 18650 (z przetwornic¡) czyni urz¡dzenie praktycznym w jednod- niowych zastosowaniach.
5. Obudowa 3D: Zaprojektowana obudowa jest kompaktowa i funkcjonalna. Chroni elek-
| tronik¦ przed uszkodzeniami mechanicznymi, zapewniaj¡c jednocze±nie ªatwy dost¦p do portu ªadowania i karty pami¦ci.

### 6.2 Podsumowanie dziaªania

Zrealizowany system dziaªa w peªni poprawnie i speªniª wszystkie zaªo»enia oraz cel pracy. Urz¡dzenie pomy±lnie przeszªo testy terenowe, rejestruj¡c trasy bez awarii. Projekt udowodniª, »e wykorzystuj¡c tanie i ogólnodost¦pne moduªy (ESP32, NEO-6M), mo»na zbudowa¢ narz¦dzie telemetryczne o funkcjonalno±ci zbli»onej do prostych urz¡dze« komercyjnych.
Dodatkow¡ warto±ci¡ projektu jest jego aspekt edukacyjny. Budowa urz¡dzenia wymagaªa poª¡czenia wiedzy z zakresu elektroniki, druku 3D oraz programowania systemów wbudowanych i aplikacji webowych. Powstaªy prototyp jest nie tylko dziaªaj¡cym urz¡dzeniem, ale tak»e solidn¡ platform¡ do dalszego rozwoju, np. poprzez dodanie moduªu GSM w przyszªo±ci.
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

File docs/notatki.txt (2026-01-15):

Fragment usunięty z pracy (Filtracja zakłóceń):

Moduły GPS operują na sygnałach radiowych o bardzo niskiej mocy, przez co są niezwykle wrażliwe na zakłócenia elektromagnetyczne (EMI). ESP32 podczas transmisji WiFi generuje znaczne piki prądowe, które mogą wprowadzać szumy w linii zasilania. Aby temu zapobiec, w projekcie kluczowe jest stosowanie kondensatorów filtrujących (elektrolitycznych oraz ceramicznych) jak najbliżej pinów zasilających modułu GPS, co zapewnia stabilność pracy odbiornika satelitarnego.

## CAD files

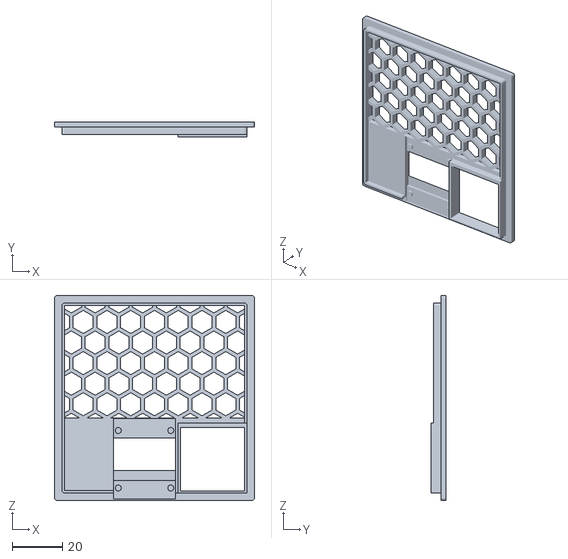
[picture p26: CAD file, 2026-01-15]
Models_Inventor/Stl_models/FINALPOKRYWKAV2.stl
80.0 x 6.00 x 82.0

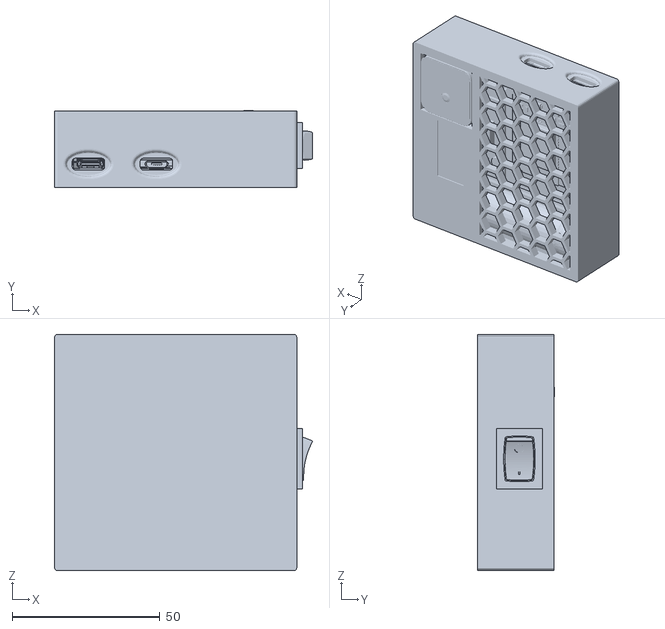
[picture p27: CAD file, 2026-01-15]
Models_Inventor/Stl_models/GPS-TRACKER_V2.stl
87.3 x 26.2 x 80.0

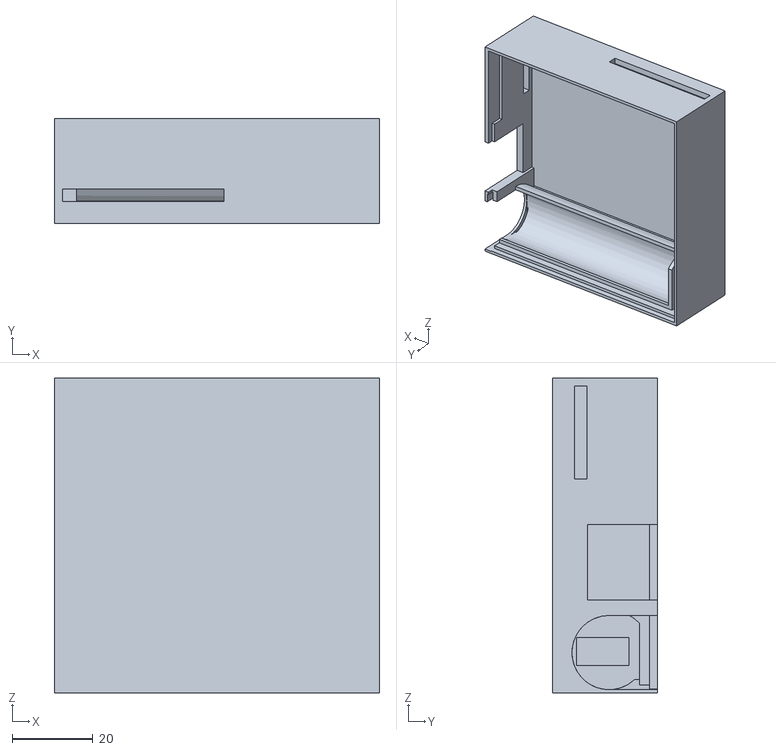
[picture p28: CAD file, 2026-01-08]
Models_Inventor/Stl_models/obudowa.stl
80.5 x 26.0 x 78.0

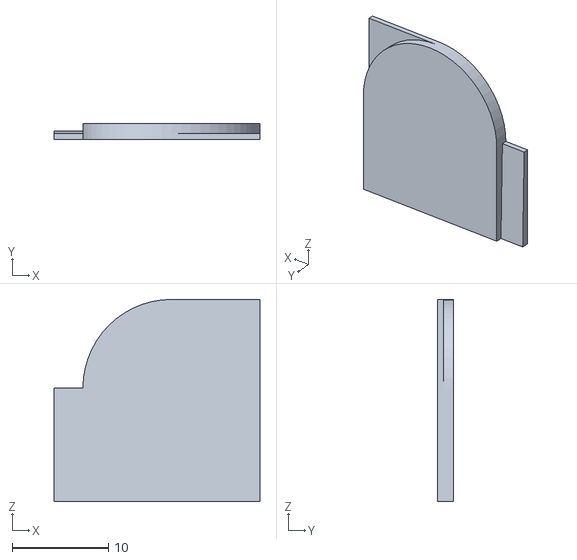
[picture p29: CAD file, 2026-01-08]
Models_Inventor/Stl_models/klapka.stl
21.4 x 1.62 x 21.0

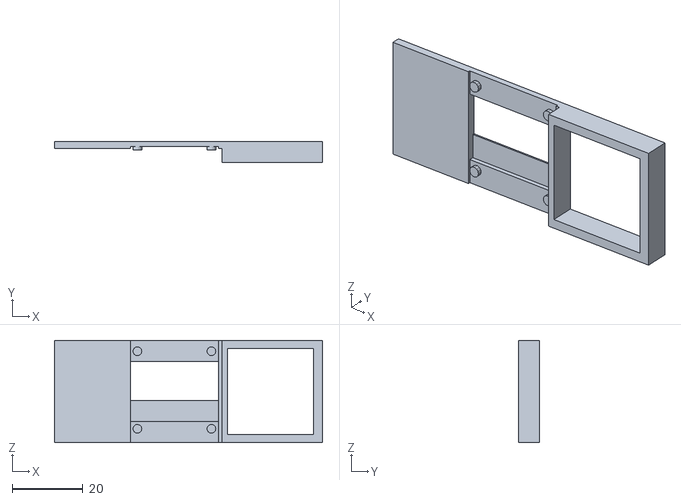
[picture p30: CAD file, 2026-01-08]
Models_Inventor/Stl_models/pokrywka2.stl
76.0 x 6.00 x 29.0

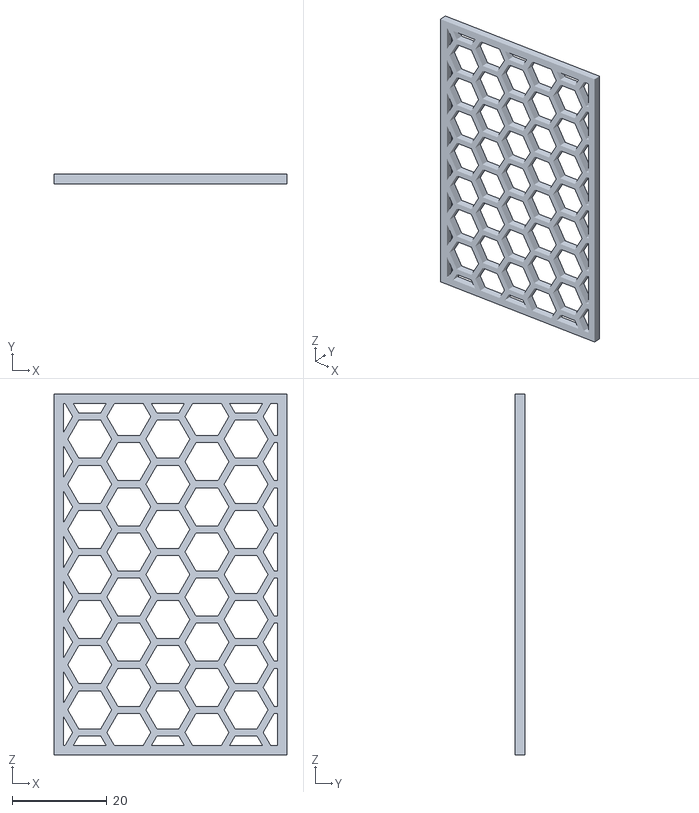
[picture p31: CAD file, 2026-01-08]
Models_Inventor/Stl_models/honneypattern.stl
49.0 x 2.00 x 76.0

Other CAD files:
Models_Inventor/ESP-32_v1/6.ESP-32_Predeterminado.ipt
Models_Inventor/ESP-32_v1/ESP-32_v1.iam
Models_Inventor/ESP-32_v1/KiCAD-ESP-WROOM-32_Predeterminado.ipt
Models_Inventor/ESP-32_v1/OldVersions/6.ESP-32_Predeterminado.0001.ipt
Models_Inventor/ESP-32_v1/OldVersions/ESP-32_v1.0001.iam
Models_Inventor/ESP-32_v1/micro_usb_47346-0001.ipt
Models_Inventor/FINALPOKRYWKAV2.ipt
Models_Inventor/GPS-TRACKER_V2.iam
Models_Inventor/GPS_tracker.iam
Models_Inventor/GPS_tracker.ipn
Models_Inventor/GY-NEO6MV2-withAnt v7/A_GPS_ant v2.iam
Models_Inventor/GY-NEO6MV2-withAnt v7/Component6.ipt
Models_Inventor/GY-NEO6MV2-withAnt v7/Component7.ipt
Models_Inventor/GY-NEO6MV2-withAnt v7/Component8.ipt
Models_Inventor/GY-NEO6MV2-withAnt v7/Component9.ipt
Models_Inventor/GY-NEO6MV2-withAnt v7/GPS_ant.iam
Models_Inventor/GY-NEO6MV2-withAnt v7/GPS_back.iam
Models_Inventor/GY-NEO6MV2-withAnt v7/GPS_board.iam
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

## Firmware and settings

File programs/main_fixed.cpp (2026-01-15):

#include <Arduino.h>
#include <WiFi.h>
#include <AsyncTCP.h>
#include <ESPAsyncWebServer.h>
#include <Wire.h>
#include <SPI.h>
#include <SD.h>
#include <TinyGPS++.h>
#include <Adafruit_GFX.h>
#include <Adafruit_SSD1306.h>
#include <MPU6050_light.h>
#include <esp_wifi.h> // Potrzebne do zmiany mocy WiFi
#include "webpage.h"

// --- KONFIGURACJA PINÓW ---
#define I2C_SDA 21
#define I2C_SCL 22
#define GPS_RX 16
#define GPS_TX 17
#define SD_CS 5
#define SD_SCK 18
#define SD_MISO 19
#define SD_MOSI 23

// --- STAŁE ---
#define WIFI_SSID "Ceskie drahy"
#define WIFI_PASS "30788888"

#define SCREEN_WIDTH 128
#define SCREEN_HEIGHT 64
#define LOG_BUFFER_SIZE 512
#define AUTO_PAUSE_SPEED 2.0 // km/h
#define AUTO_PAUSE_TIME 5000 // ms
#define MIN_DIST 5.0 // meters
#define GPS_READ_LIMIT 100 // Max NMEA chars per loop iteration

// --- OBIEKTY ---
TinyGPSPlus gps;
HardwareSerial gpsSerial(2);
MPU6050 mpu(Wire);
Adafruit_SSD1306 display(SCREEN_WIDTH, SCREEN_HEIGHT, &Wire, -1);
AsyncWebServer server(80);

// --- MUTEX (Chroniący SD oraz logBuffer i sharedStatus) ---
SemaphoreHandle_t sdMutex = NULL;

// --- ZMIENNE STANU ---
enum State { IDLE, RECORDING, PAUSED };
State currentState = IDLE;

// Struktura do współdzielenia stanu z wątkiem serwera (Atomowość)
struct TrackerStatus {
    double lat, lon, speed, alt, dist;
    int sats;
    float ax, ay, az;
    int state;
} sharedStatus;

bool sdReady = false;
bool mpuReady = false;
bool gpsFix = false;

String currentFileName = "";
String logBuffer = "";
unsigned long lastMotionTime = 0;
unsigned long sessionStart = 0;
unsigned long pauseStart = 0;
unsigned long totalPaused = 0;
double totalDist = 0;
double lastLat = 0, lastLon = 0;

// --- PROTOTYPY ---
void setupHardware();
void setupWiFi();
void setupServer();
void logicLoop();
void displayLoop();
void logData();
void startRec();
void stopRec();
bool checkMotion();
String getFileList();
void updateSharedStatus();

void setup() {
    Serial.begin(115200);
    
    // Mutex MUSI być utworzony PRZED setupHardware (SD init)
    sdMutex = xSemaphoreCreateMutex();
    if(sdMutex == NULL) {
        Serial.println("FATAL: Mutex creation failed!");
        while(1); // halt
    }
    
    setupHardware();
    setupWiFi();
    setupServer();
    
    // Preallokacja bufora dla String (zapobiega fragmentacji)
    logBuffer.reserve(LOG_BUFFER_SIZE + 100);
}

void loop() {
    // 1. GPS Feed (LIMITED to avoid blocking)
    int gpsCharsRead = 0;
    while(gpsSerial.available() && gpsCharsRead < GPS_READ_LIMIT) {
        gps.encode(gpsSerial.read());
        gpsCharsRead++;
    }
    
    // 2. MPU Update (Always run for IMU)
    if(mpuReady) mpu.update();

    // 3. Logic & Shared State Update
    logicLoop();

    // 4. Display (Low prio)
    static unsigned long lastDisp = 0;
    if(millis() - lastDisp > 500) {
        displayLoop();
        lastDisp = millis();
    }
}

// --- IMPLEMENTACJA ---

void setupHardware() {
    Wire.begin(I2C_SDA, I2C_SCL);

    // OLED
    if(!display.begin(SSD1306_SWITCHCAPVCC, 0x3C)) {
        Serial.println("OLED Fail");
    }
    display.clearDisplay();
    display.setTextColor(WHITE);
    display.setTextSize(1);
    display.setCursor(0,0);
    display.println("Booting...");
    display.display();

    // MPU
    if(mpu.begin() == 0) {
        mpu.calcOffsets(true,true);
        mpuReady = true;
        Serial.println("MPU OK");
    } else {
        Serial.println("MPU Fail");
    }

    // SD (z Mutex protection)
    SPI.begin(SD_SCK, SD_MISO, SD_MOSI, SD_CS);
    
    if(xSemaphoreTake(sdMutex, portMAX_DELAY) == pdTRUE) {
        if(SD.begin(SD_CS)) {
            sdReady = true;
            Serial.println("SD OK");
        } else {
            Serial.println("SD Fail");
        }
        xSemaphoreGive(sdMutex);
    }

    // GPS
    gpsSerial.begin(9600, SERIAL_8N1, GPS_RX, GPS_TX);
}

void setupWiFi() {
    WiFi.mode(WIFI_AP_STA);
    
    // ZMNIEJSZENIE MOCY TX (Ochrona GPS przed zakłóceniami RF)
    // Bezpieczniejszy poziom dla trybu AP+STA blisko modułu GPS
    WiFi.setTxPower(WIFI_POWER_11dBm);

    display.clearDisplay();
    display.setCursor(0,0);
    display.println("Lacze z Hotspotem...");
    display.println(WIFI_SSID);
    display.display();

    WiFi.begin(WIFI_SSID, WIFI_PASS);
    
    int retries = 0;
    while(WiFi.status() != WL_CONNECTED && retries < 20) {
        delay(500);
        Serial.print(".");
        retries++;
    }

    if(WiFi.status() == WL_CONNECTED) {
        Serial.println("\nSTA Connected!");
        Serial.print("IP: "); Serial.println(WiFi.localIP());
        display.println("OK! IP:");
        display.println(WiFi.localIP());
    } else {
        Serial.println("\nSTA Failed, AP Only");
        display.println("Brak Hotspotu.");
        display.println("Tryb AP (Offline)");
    }
    display.display();
    delay(2000);

    // Konfiguracja AP
    WiFi.softAPConfig(IPAddress(192,168,4,1), IPAddress(192,168,4,1), IPAddress(255,255,255,0));
    WiFi.softAP("ESP32-Tracker", "12345678");
    Serial.print("AP IP: "); Serial.println(WiFi.softAPIP());

    // CORS Headers
    DefaultHeaders::Instance().addHeader("Access-Control-Allow-Origin", "*");
    DefaultHeaders::Instance().addHeader("Access-Control-Allow-Methods", "GET, POST, PUT, DELETE, OPTIONS");
    DefaultHeaders::Instance().addHeader("Access-Control-Allow-Headers", "Content-Type");
}

void setupServer() {
    // Main Page
    server.on("/", HTTP_GET, [](AsyncWebServerRequest *request){
        request->send_P(200, "text/html", index_html);
    });

    // Status API - ATOMIC READ
    server.on("/api/status", HTTP_GET, [](AsyncWebServerRequest *request){
        String json;
        json.reserve(256);
        
        // Szybka próba pobrania mutexu (nie blokujemy serwera)
        if(xSemaphoreTake(sdMutex, pdMS_TO_TICKS(10)) == pdTRUE) {
            // Czytamy z kopii (sharedStatus), nie z 'gps'
            json = "{";
            json += "\"state\":" + String(sharedStatus.state) + ",";
            json += "\"sats\":" + String(sharedStatus.sats) + ",";
            json += "\"lat\":" + String(sharedStatus.lat, 6) + ",";
            json += "\"lon\":" + String(sharedStatus.lon, 6) + ",";
            json += "\"speed\":" + String(sharedStatus.speed, 1) + ",";
            json += "\"alt\":" + String(sharedStatus.alt, 1) + ",";
            json += "\"dist\":" + String(sharedStatus.dist, 1) + ",";
            json += "\"ax\":" + String(sharedStatus.ax, 2) + ",";
            json += "\"ay\":" + String(sharedStatus.ay, 2) + ",";
            json += "\"az\":" + String(sharedStatus.az, 2);
            json += "}";
            xSemaphoreGive(sdMutex);
            
            request->send(200, "application/json", json);
        } else {
            request->send(503, "text/plain", "Busy");
        }
    });

    // Controls
    server.on("/api/start", HTTP_GET, [](AsyncWebServerRequest *request){
        if(currentState == IDLE) {
            startRec();
        } else if(currentState == PAUSED) {
            currentState = RECORDING; // Resume
            Serial.println("Resumed");
        }
        request->send(200);
    });
    
    server.on("/api/pause", HTTP_GET, [](AsyncWebServerRequest *request){
        if(currentState == RECORDING) {
            currentState = PAUSED;
            pauseStart = millis();
            
            // Flush buffer safe
            if(sdReady) {
                if(xSemaphoreTake(sdMutex, pdMS_TO_TICKS(100)) == pdTRUE) {
                    if(logBuffer.length() > 0) {
                        File f = SD.open(currentFileName, FILE_APPEND);
                        if(f) {
                            f.print(logBuffer);
                            f.flush();
                            f.close();
                            logBuffer = "";
                        }
                    }
                    xSemaphoreGive(sdMutex);
                }
            }
            Serial.println("Paused & Flushed");
        }
        request->send(200);
    });

    server.on("/api/stop", HTTP_GET, [](AsyncWebServerRequest *request){
        if(currentState != IDLE) {
            stopRec();
        }
        request->send(200);
    });
    
    server.on("/api/discard", HTTP_GET, [](AsyncWebServerRequest *request){
        if(currentState != IDLE) {
            currentState = IDLE;
            // Mutex for clearing buffer
            if(xSemaphoreTake(sdMutex, pdMS_TO_TICKS(100)) == pdTRUE) {
                logBuffer = "";
                if(SD.exists(currentFileName)) {
                    SD.remove(currentFileName);
                    Serial.println("File discarded");
                }
                xSemaphoreGive(sdMutex);
            }
        }
        request->send(200);
    });

    // Files API
    server.on("/api/files", HTTP_GET, [](AsyncWebServerRequest *request){
        String list = getFileList();
        request->send(200, "application/json", list);
    });

    // DOWNLOAD
    server.on("/download", HTTP_GET, [](AsyncWebServerRequest *request){
        if(!request->hasParam("file")) {
            request->send(400, "text/plain", "Missing file param");
            return;
        }
        String fname = request->getParam("file")->value();
        if(!fname.startsWith("/")) fname = "/" + fname;
        if(fname.indexOf("..") >= 0) { request->send(403, "text/plain", "Forbidden"); return; }
        
        if(xSemaphoreTake(sdMutex, pdMS_TO_TICKS(50)) == pdTRUE) { // Short wait
            if(SD.exists(fname)) {
                request->send(SD, fname, "application/octet-stream");
            } else {
                request->send(404, "text/plain", "Not Found");
            }
            xSemaphoreGive(sdMutex);
        } else {
            request->send(503, "text/plain", "SD Busy");
        }
    });

    // DELETE
    server.on("/delete", HTTP_DELETE, [](AsyncWebServerRequest *request){
        if(!request->hasParam("file")) { request->send(400, "text/plain", "Missing file param"); return; }
        String fname = request->getParam("file")->value();
        if(!fname.startsWith("/")) fname = "/" + fname;
        if(fname.indexOf("..") >= 0) { request->send(403, "text/plain", "Forbidden"); return; }
        if(fname == currentFileName && currentState != IDLE) { request->send(400, "text/plain", "Cannot delete active log!"); return; }
        
        if(xSemaphoreTake(sdMutex, pdMS_TO_TICKS(50)) == pdTRUE) {
            if(SD.exists(fname)) { 
                SD.remove(fname); 
                request->send(200, "text/plain", "Deleted"); 
            } else {
                request->send(404, "text/plain", "Not Found");
            }
            xSemaphoreGive(sdMutex);
        } else {
            request->send(503, "text/plain", "SD Busy");
        }
    });

    server.begin();
    Serial.println("Server started");
}

// --- LOGIKA ---

void updateSharedStatus() {
    // Kopiowanie stanu do sharedStatus POD MUTEXEM
    if(xSemaphoreTake(sdMutex, 0) == pdTRUE) { // 0 ticks - don't block loop if busy
        sharedStatus.lat = gps.location.isValid() ? gps.location.lat() : 0.0;
        sharedStatus.lon = gps.location.isValid() ? gps.location.lng() : 0.0;
        sharedStatus.speed = gps.speed.kmph();
        sharedStatus.alt = gps.altitude.meters();
        sharedStatus.sats = (int)gps.satellites.value();
        sharedStatus.dist = totalDist;
        sharedStatus.ax = mpuReady ? mpu.getAccX() : 0.0;
        sharedStatus.ay = mpuReady ? mpu.getAccY() : 0.0;
        sharedStatus.az = mpuReady ? mpu.getAccZ() : 0.0;
        sharedStatus.state = currentState;
        xSemaphoreGive(sdMutex);
    }
}

bool checkMotion() {
    bool gpsMoving = (gps.speed.kmph() > AUTO_PAUSE_SPEED);
    if(!mpuReady) return gpsMoving;
    float gMagnitude = sqrt(pow(mpu.getAccX(), 2) + pow(mpu.getAccY(), 2) + pow(mpu.getAccZ(), 2));
    bool imuMoving = (fabs(gMagnitude - 1.0) > 0.15);
    return gpsMoving || imuMoving;
}

void logicLoop() {
    gpsFix = gps.location.isValid();
    
    // Zawsze aktualizuj status dla WWW
    updateSharedStatus();
    
    if(currentState == IDLE) return;

    if(checkMotion()) {
        lastMotionTime = millis();
        if(currentState == PAUSED) {
            currentState = RECORDING;
            totalPaused += (millis() - pauseStart);
            Serial.println("Auto-resumed");
        }
    } else {
        if(currentState == RECORDING && (millis() - lastMotionTime > AUTO_PAUSE_TIME)) {
            currentState = PAUSED;
            pauseStart = millis();
            Serial.println("Auto-paused");
            
            // Flush buffer safe
            if(sdReady) {
                if(xSemaphoreTake(sdMutex, pdMS_TO_TICKS(50)) == pdTRUE) {
                    if(logBuffer.length() > 0) {
                        File f = SD.open(currentFileName, FILE_APPEND);
                        if(f) {
                            f.print(logBuffer);
                            f.flush();
                            f.close();
                            logBuffer = "";
                        }
                    }
                    xSemaphoreGive(sdMutex);
                }
            }
        }
    }

    if(currentState == RECORDING) {
        logData();
    }
}

void logData() {
    if(!gpsFix || !sdReady) return;

    // Obliczenia na zmiennych lokalnych (bez mutexa)
    double d = TinyGPSPlus::distanceBetween(
        gps.location.lat(), gps.location.lng(), 
        lastLat, lastLon
    );
    
    if(d > MIN_DIST || lastLat == 0) {
        char line[150];
        snprintf(line, sizeof(line), 
            "%lu,%.6f,%.6f,%.1f,%.1f,%d,%.2f,%.2f,%.2f\n",
            millis(),
            gps.location.lat(),
            gps.location.lng(),
            gps.speed.kmph(),
            gps.altitude.meters(),
            (int)gps.satellites.value(),
            mpuReady ? mpu.getAccX() : 0.0,
            mpuReady ? mpu.getAccY() : 0.0,
            mpuReady ? mpu.getAccZ() : 0.0
        );
        
        // Zapis do logBuffer i ewentualny flush POD MUTEXEM
        if(xSemaphoreTake(sdMutex, pdMS_TO_TICKS(10)) == pdTRUE) {
            logBuffer += line;
            
            // Aktualizacja stanu
            if(lastLat != 0) totalDist += d;
            lastLat = gps.location.lat();
            lastLon = gps.location.lng();

            if(logBuffer.length() >= LOG_BUFFER_SIZE) {
                File f = SD.open(currentFileName, FILE_APPEND);
                if(f) {
                    f.print(logBuffer);
                    f.close();
                    logBuffer = "";
                }
            }
            xSemaphoreGive(sdMutex);
        }
    }
}

void startRec() {
    if(!sdReady) {
        Serial.println("Cannot start: SD not ready");
        return;
    }
    
    // Zabezpieczenie całej operacji startu
    if(xSemaphoreTake(sdMutex, pdMS_TO_TICKS(500)) == pdTRUE) {
        currentFileName = "/log_" + String(millis()) + ".csv";
        File f = SD.open(currentFileName, FILE_WRITE);
        if(f) {
            f.println("time_ms,lat,lon,speed_kmh,alt_m,sats,ax,ay,az");
            f.close();
            Serial.println("Started: " + currentFileName);
            
            currentState = RECORDING;
            sessionStart = millis();
            lastMotionTime = millis();
            totalPaused = 0;
            totalDist = 0;
            lastLat = 0; 
            lastLon = 0;
            logBuffer = ""; // Clear buffer clearly under mutex
        } else {
            Serial.println("Failed to create file");
        }
        xSemaphoreGive(sdMutex);
    } else {
        Serial.println("Start busy");
    }
}

void stopRec() {
    // Final flush with Mutex
    if(xSemaphoreTake(sdMutex, pdMS_TO_TICKS(500)) == pdTRUE) {
        if(logBuffer.length() > 0 && sdReady) {
            File f = SD.open(currentFileName, FILE_APPEND);
            if(f) {
                f.print(logBuffer);
                f.flush();
                f.close();
            }
        }
        logBuffer = ""; // Clear buffer
        Serial.println("Stopped. Total dist: " + String(totalDist/1000.0) + " km");
        currentState = IDLE;
        xSemaphoreGive(sdMutex);
    }
}

String getFileList() {
    if(!sdReady) return "[]";
    
    String json;
    json.reserve(512); 
    json = "[";
    
    if(xSemaphoreTake(sdMutex, pdMS_TO_TICKS(300)) == pdTRUE) {
        File root = SD.open("/");
        if(!root) {
            xSemaphoreGive(sdMutex);
            return "[]";
        }
        
        File f = root.openNextFile();
        bool first = true;
        int fileCount = 0;
        
        while(f && fileCount < 50) {
            if(!f.isDirectory()) {
                if(!first) json += ",";
                String fname = String(f.name());
                fname.replace("\"", "\\\"");
                json += "{\"name\":\"" + fname + "\",\"size\":" + String(f.size()) + "}";
                first = false;
                fileCount++;
            }
            f.close();
            f = root.openNextFile();
        }
        root.close();
        xSemaphoreGive(sdMutex);
    }
    
    json += "]";
    return json;
}

void displayLoop() {
    // Use COPY of data to avoid holding mutex during slow I2C display update!
    TrackerStatus statusCopy;
    if(xSemaphoreTake(sdMutex, 0) == pdTRUE) {
        statusCopy = sharedStatus;
        xSemaphoreGive(sdMutex);
    } else {
        //If busy, just use sharedStatus (updated under mutex anyway, atomic struct copy safer than reading gps object)
        statusCopy = sharedStatus; 
    }

    display.clearDisplay();

    // Top Bar
    display.setCursor(0,0);
    display.print(sdReady ? "SD" : "NO SD");
    display.setCursor(50,0);
    display.printf("SAT:%d", statusCopy.sats);
    display.setCursor(95,0);
    
    if(statusCopy.state == RECORDING) display.print("REC");
    else if(statusCopy.state == PAUSED) display.print("PAUSE");
    else display.print("IDLE");
    
    display.drawLine(0,9,128,9, WHITE);

    // Main Info - Speed
    display.setTextSize(2);
    display.setCursor(0,18);
    display.printf("%.1f", statusCopy.speed);
    display.setTextSize(1);
    display.print(" km/h");

    // Bottom Info
    display.setCursor(0,45);
    
    if(statusCopy.state == IDLE) {
        String ip = (WiFi.status() == WL_CONNECTED) ? 
                    WiFi.localIP().toString() : 
                    WiFi.softAPIP().toString();
        display.print(ip);
    } else {
        display.printf("D: %.2fkm", statusCopy.dist/1000.0);
    }
    
    display.setCursor(0,55);
    if(gpsFix) { 
        display.printf("%.4f, %.4f", statusCopy.lat, statusCopy.lon);
    } else {
        display.print("Szukam GPS...");
    }

    display.display();
}

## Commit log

2026-01-06 Add README for GPS Tracker ESP32 project
    Added detailed project information for GPS Tracker using ESP32, including components, wiring, software requirements, and setup instructions.
2026-01-08 model i zdjecia
    [0603 Capacitor.ipt, 0603 Resistor.ipt, 18650_cell v1.ipt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]
2026-01-15 inventor model v2 update
    [FINALPOKRYWKAV2.0003.ipt, FINALPOKRYWKAV2.ipt, FINALPOKRYWKAV2.stl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]
